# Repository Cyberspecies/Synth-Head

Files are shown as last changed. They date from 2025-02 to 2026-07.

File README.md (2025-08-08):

# Synth Head
To create an open source suit which can be worn by an individual and customised to their will. It also must be constructed in such a way that an average human could build it within a reasonable budget and time. The suit must be modular whilst remaining safe for the user to operate. The software must be easy to configure for any individual and has capability to modify without the need to always reflashing its firmware. The project was created according to this standard however, it has evolved over time to be more of a testing ground for sensors and other features of the like as I will continue this along with other projects I have due to compatibility.

DX.3

## Overview
This project is always in the works and will be updated. Although regular updates are not possible due to me still being in uni, I will do what I can. This repo is basically a better version of the other repo and a true migration as the old one due to its structure. The reason for it being a new repo rather then just a fix is cause the title changed so the old link wouldn't have worked anyway. The current design is DX which stands for Design 10 as it is the 10th time the base shape has changed, the .3 at the end is an iterator for which version were on.

### Features
* <strong style='color: #99ccff;'>Vacuum Formed Visor</strong> allows the user to see out of a clear shell rather then the previous mesh version which caused chromatic abberation, preventing the true colours of the display from emiting through the visor properly.
* <strong style='color: #99ccff;'>Detachable Substructure</strong> which conformes to the visor ridge provides an easy to modify platform to which different displays, sensors and other modules.
* <strong style='color: #99ccff;'>Builtin Head Restraint</strong> was designed to hold in an average head with relatively high pressure, although the pressure seems like it cause pain, the addition of a foam pad mitigates this and is actually comfortable to wear.
* <strong style='color: #99ccff;'>Silent Slim Jaw Mount</strong> of around 6mm in total thickness is directly integrated to the shell.
* <strong style='color: #99ccff;'>Snoot Sensors</strong> All of the sensors and modules are attached directly into the detachable substructure and can easily be replaced and upgraded as needed, many of which includes: Boop detection, snoot holding detection & IMUs.
* <strong style='color: #99ccff;'>Ventillation</strong> is key to an alive and well user, there are 2 fans located below the tongue which negatively ventillates the user.

### In the works
* The visor edge and mating surface will be changed due to it currently resulting in an uneven edge to edge connection.
* The builtin head restraint will also be upgraded, although the system works it is not the best designed as it is currently difficult to put the pins in place.
* Electronics & other cabling will be hidden in the final release as it is not compact due to the Rushed version built for speed and prototyping rather then stability.
* ARCOS migration is still under play, the entire library is basically being rewritten slowly so it runs faster with more features. The library is currently not accessable as it is privated but it will be released with the release of the synth head 10.3.
* <strong style='color: #ffb3ff;'>Feature Inclusion:</strong> Cable management
* <strong style='color: #ffb3ff;'>Feature Inclusion:</strong> Visor Edge Alignment Upgrade
* <strong style='color: #ffb3ff;'>Feature Inclusion:</strong> Ventillation Upgrade
* <strong style='color: #ffb3ff;'>Feature Inclusion:</strong> Jaw Mount Upgrade (Attached to head restraint)
* <strong style='color: #ffb3ff;'>Feature Inclusion:</strong> Lighter Frame
* <strong style='color: #ffb3ff;'>Feature Inclusion:</strong> Custom PCB (Control Board, Power & Sensors)

### Roadmap
* <strong style='color: #99ff99;'>Milestone:</strong> [Synth Head DX](/Archives/DX/README.md)
* <strong style='color: #99ff99;'>Milestone:</strong> [Synth Head DX.1](/Archives/DX.1/README.md)
* <strong style='color: #99ff99;'>Milestone:</strong> [Synth Head DX.2 Rushed](/Archives/DX.2%20Rushed/README.md)
* <strong style='color: #99ff99;'>Milestone:</strong> [Synth Head DX.3 Rushed](/Archives/DX.3%20Rushed/README.md)
* <strong style='color: #99ff99;'>Milestone:</strong> Properly Structured Github

### Licensing
* GNU-GPL-3.0: All Software
* CC-NONCOMM: All Hardware (Circuits, CAD, etc)

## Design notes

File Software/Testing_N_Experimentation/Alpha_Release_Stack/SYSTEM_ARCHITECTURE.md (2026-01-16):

# Synth-Head System Architecture & Reference

> **For AI Agents / New Chat Sessions**  
> This document contains all critical information about the dual-ESP32 Synth-Head project including pin mappings, communication protocols, HAL layer, GPU commands, and example code.

---

## Table of Contents

1. [Hardware Overview](#hardware-overview)
2. [Pin Mappings](#pin-mappings)
3. [CPU-GPU Communication Protocol](#cpu-gpu-communication-protocol)
4. [GPU Command Reference](#gpu-command-reference)
5. [HAL Layer Architecture](#hal-layer-architecture)
6. [HAL Interface Reference](#hal-interface-reference)
7. [Display Systems](#display-systems)
8. [Example: Polygon Demo with Cycling Hue](#example-polygon-demo-with-cycling-hue)
9. [PlatformIO Build Configuration](#platformio-build-configuration)
10. [File Structure](#file-structure)

---

## Hardware Overview

The Synth-Head project uses a **dual ESP32-S3 architecture**:

| Component | Description | COM Port |
|---|---|---|
| **CPU** | Main processor - runs application logic, sensors, WiFi | COM15 |
| **GPU** | Display processor - drives HUB75 + OLED, receives draw commands | COM5 |

### Displays

| Display | Resolution | Type | Location | Interface |
|---|---|---|---|---|
| **HUB75** | 128×32 | RGB LED Matrix (2× 64×32 panels) | Both eyes | GPU direct |
| **OLED** | 128×128 | Monochrome SH1107 | GPU board | I2C (0x3C) |

### Communication

- **CPU ↔ GPU**: UART @ **10 Mbps** (10,000,000 baud)
- **Protocol**: `[0xAA][0x55][CmdType:1][Length:2 LE][Payload:N]`

---

## Pin Mappings

### CPU Pins (ESP32-S3 on COM15)

#### I2C Bus
| Pin | GPIO | Function | Connected Devices |
|-----|---|---|---|
| SDA | **9** | I2C Data | ICM20948 (0x68), BME280 (0x76) |
| SCL | **10** | I2C Clock | ICM20948 (0x68), BME280 (0x76) |

#### LED Strips (WS2812B / SK6812)
| Strip | GPIO | LED Count | Purpose |
|---|---|---|---|
| Strip 0 | 16 | - | *Unused* |
| Left Fin | **18** | 13 | Left fin animation |
| Tongue | **8** | 9 | Tongue animation |
| Strip 3 | 39 | - | *Unused* |
| Right Fin | **38** | 13 | Right fin animation |
| Scale LEDs | **37** | 14 | Scale row |

#### Buttons (Active LOW)
| Button | GPIO | Label |
|---|---|---|
| A | **5** | Button A |
| B | **6** | Button B |
| C | **7** | Button C |
| D | **15** | Button D |

#### Fans (PWM)
| Fan | GPIO | Status |
|-----|---|---|
| Fan 1 | 17 | *Unused* |
| Fan 2 | **36** | Active |

#### SD Card (SPI)
| Signal | GPIO |
|---|---|
| MISO | 14 |
| MOSI | 47 |
| CLK | 21 |
| CS | 48 |

#### GPS (NEO-M8, UART2)
| Signal | GPIO | Baud |
|---|---|---|
| TX | 43 | 9600 |
| RX | 44 | 9600 |

#### CPU-GPU UART (UART1)
| Signal | GPIO | Note |
|---|---|---|
| TX | **12** | → GPU RX (GPIO 13) |
| RX | **11** | ← GPU TX (GPIO 12) |
| **Baud** | - | **10,000,000** (10 Mbps) |

#### I2S Microphone (INMP441)
| Signal | GPIO |
|---|---|
| DOUT (SD) | 2 |
| CLK (BCK) | 40 |
| L/R Select | 41 |
| WS | 42 |

### GPU Pins (ESP32-S3 on COM5)

#### CPU-GPU UART (UART1)
| Signal | GPIO |
|---|---|
| TX | 12 |
| RX | **13** |

#### HUB75 (Directly driven by GPU)
```
Configured in ARCOS HUB75 driver - see driver_hub75_simple.hpp
```

#### OLED (I2C)
| Signal | Address |
|---|---|
| SH1107 | **0x3C** |

---

## CPU-GPU Communication Protocol

### Packet Format

```
┌──────┬──────┬─────────┬───────────────┬─────────────┐
│ 0xAA │ 0x55 │ CmdType │ Length (2 LE) │ Payload (N) │
└──────┴──────┴─────────┴───────────────┴─────────────┘
   1B     1B      1B          2B            0-N B
```

- **Sync bytes**: `0xAA 0x55` (must be present)
- **CmdType**: Single byte command identifier
- **Length**: 16-bit little-endian payload length
- **Payload**: Command-specific data

### UART Configuration

```cpp
// CPU side (sending to GPU)
constexpr uart_port_t UART_PORT = UART_NUM_1;
constexpr int UART_TX_PIN = 12;  // CPU TX -> GPU RX (GPIO 13)
constexpr int UART_RX_PIN = 11;  // CPU RX <- GPU TX (GPIO 12)
constexpr int UART_BAUD = 10000000;  // 10 Mbps

uart_config_t cfg = {
    .baud_rate = UART_BAUD,
    .data_bits = UART_DATA_8_BITS,
    .parity = UART_PARITY_DISABLE,
    .stop_bits = UART_STOP_BITS_1,
    .flow_ctrl = UART_HW_FLOWCTRL_DISABLE,
    .source_clk = UART_SCLK_DEFAULT,
};
uart_param_config(UART_PORT, &cfg);
uart_set_pin(UART_PORT, UART_TX_PIN, UART_RX_PIN, -1, -1);
uart_driver_install(UART_PORT, 4096, 2048, 0, nullptr, 0);  // RX=4KB, TX=2KB
```

### ⚠️ CRITICAL TIMING REQUIREMENTS

**The GPU ESP32's uart_task needs time to initialize after boot!**

If you send commands immediately after CPU UART init, the GPU may not be ready to receive them, resulting in:
- Ping timeouts
- Commands being lost/ignored
- Intermittent connection failures

**Required Timing:**

```cpp
// After uart_driver_install(), WAIT before sending first command!
uart_driver_install(UART_PORT, 4096, 2048, 0, nullptr, 0);

// CRITICAL: Wait 500ms for GPU to fully initialize its UART task
// This matches the working CPU_PolygonDemo.cpp timing
vTaskDelay(pdMS_TO_TICKS(500));

// Now safe to send commands
sendResetCommand();
```

**Best Practices:**
1. **Wait 500ms** after UART init before sending first command
2. Use `uart_wait_tx_done(port, timeout)` after sending commands that need confirmation
3. Flush RX buffer before expecting responses: `uart_flush_input(port)`
4. Use larger buffers (4096 RX, 2048 TX) for high-speed communication

**Reference Implementation:**
- See [CPU_PolygonDemo.cpp](src/CPU_PolygonDemo.cpp) - this demo works reliably every time
- Line 193 has the critical 500ms delay after UART init

**If GPU Won't Connect:**
1. Check hardware connections (TX/RX crossover)
2. Verify GPIO pins are correct
3. **Increase startup delay** (500ms is minimum)
4. Check baud rate matches (10 Mbps)
5. Verify GPU firmware is flashed and running

---

## GPU Command Reference

### Command Types (CmdType values)

#### System Commands
| Cmd | Hex | Payload | Description |
|-----|-----|---|---|
| NOP | 0x00 | - | No operation |
| PING | 0xF0 | - | Ping GPU |
| RESET | 0xFF | - | Reset GPU state |

#### Target Selection
| Cmd | Hex | Payload | Description |
|-----|-----|---|---|
| SET_TARGET | 0x50 | `[target:1]` | 0=HUB75, 1=OLED |
| PRESENT | 0x51 | - | Swap framebuffer to display |

#### HUB75 Drawing (Target 0)
| Cmd | Hex | Payload | Description |
|-----|-----|---|---|
| DRAW_PIXEL | 0x40 | `[x:2][y:2][r:1][g:1][b:1]` | Draw single pixel |
| DRAW_LINE | 0x41 | `[x1:2][y1:2][x2:2][y2:2][r:1][g:1][b:1]` | Draw line |
| DRAW_RECT | 0x42 | `[x:2][y:2][w:2][h:2][r:1][g:1][b:1]` | Rectangle outline |
| DRAW_FILL | 0x43 | `[x:2][y:2][w:2][h:2][r:1][g:1][b:1]` | Filled rectangle |
| DRAW_CIRCLE | 0x44 | `[cx:2][cy:2][radius:2][r:1][g:1][b:1]` | Circle outline |
| DRAW_POLY | 0x45 | `[nVerts:1][varStart:1][r:1][g:1][b:1]` | Polygon from vars |
| BLIT_SPRITE | 0x46 | `[id:1][x:2][y:2]` | Blit uploaded sprite |
| CLEAR | 0x47 | `[r:1][g:1][b:1]` | Clear to color |

#### Float Coordinate Versions (Anti-aliased)
| Cmd | Hex | Payload | Description |
|-----|-----|---|---|
| DRAW_LINE_F | 0x48 | `[x1:4f][y1:4f][x2:4f][y2:4f][r:1][g:1][b:1]` | AA line |
| DRAW_CIRCLE_F | 0x49 | `[cx:4f][cy:4f][radius:4f][r:1][g:1][b:1]` | AA circle |
| DRAW_RECT_F | 0x4A | `[x:4f][y:4f][w:4f][h:4f][r:1][g:1][b:1]` | AA rect |

#### OLED Drawing (128×128 Mono)
| Cmd | Hex | Payload | Description |
|-----|-----|---|---|
| OLED_CLEAR | 0x60 | - | Clear OLED |
| OLED_LINE | 0x61 | `[x1:2][y1:2][x2:2][y2:2][on:1]` | Draw line |
| OLED_RECT | 0x62 | `[x:2][y:2][w:2][h:2][on:1]` | Rectangle outline |
| OLED_FILL | 0x63 | `[x:2][y:2][w:2][h:2][on:1]` | Filled rectangle |
| OLED_CIRCLE | 0x64 | `[cx:2][cy:2][r:2][on:1]` | Circle outline |
| OLED_PRESENT | 0x65 | - | Update OLED display |
| OLED_PIXEL | 0x66 | `[x:2][y:2][on:1]` | Single pixel |
| OLED_VLINE | 0x67 | `[x:2][y:2][len:2][on:1]` | Vertical line |
| OLED_HLINE | 0x68 | `[x:2][y:2][len:2][on:1]` | Horizontal line |
| OLED_FILL_CIRCLE | 0x69 | `[cx:2][cy:2][r:2][on:1]` | Filled circle |

#### Shader System
| Cmd | Hex | Payload | Description |
|-----|-----|---|---|
| UPLOAD_SHADER | 0x10 | `[slot:1][bytecode:N]` | Upload shader |
| DELETE_SHADER | 0x11 | `[slot:1]` | Delete shader |
| EXEC_SHADER | 0x12 | `[slot:1]` | Execute shader |
| SET_VAR | 0x30 | `[id:1][value:2]` | Set variable |
| SET_VARS | 0x31 | `[startId:1][count:1][values:2×N]` | Set multiple vars |

#### Sprite System
| Cmd | Hex | Payload | Description |
|-----|-----|---|---|
| UPLOAD_SPRITE | 0x20 | `[id:1][w:1][h:1][fmt:1][data:N]` | Upload sprite |
| DELETE_SPRITE | 0x21 | `[id:1]` | Delete sprite |

### Payload Encoding

All multi-byte integers are **little-endian (LE)**:
```cpp
// Encode int16_t to payload
void encodeI16(uint8_t* buf, int idx, int16_t val) {
    buf[idx] = val & 0xFF;           // Low byte first
    buf[idx + 1] = (val >> 8) & 0xFF; // High byte second
}
```

---

## HAL Layer Architecture

### Namespace Structure

```
arcos::hal
├── HalResult          // Result codes (OK, ERROR, TIMEOUT, etc.)
├── HalTypes           // RGB, RGBW, Vec3f, Vec3i
├── pins::cpu          // CPU pin definitions
├── pins::gpu          // GPU pin definitions  
├── pins::i2c_addr     // I2C device addresses
├── pins::defaults     // Default settings
│
├── IHalGpio           // Digital GPIO interface
├── IHalPwm            // PWM output interface
├── IHalButton         // Button input interface
├── IHalUart           // UART interface
├── IHalI2c            // I2C interface
├── IHalSpi            // SPI interface
├── IHalI2s            // I2S audio interface
├── IHalTimer          // Timer/delay interface
├── IHalImu            // IMU sensor interface
├── IHalEnvironmental  // Temperature/humidity/pressure
├── IHalGps            // GPS interface
├── IHalMicrophone     // Microphone input
├── IHalLedStrip       // Addressable LED strips
├── IHalDisplay        // Display interface
└── IHalStorage        // SD card/flash storage
```

### Pin Constants (from `HAL/hal.hpp`)

```cpp
namespace arcos::hal::pins {

namespace cpu {
  // I2C
  constexpr gpio_pin_t I2C_SDA = 9;
  constexpr gpio_pin_t I2C_SCL = 10;
  
  // LED Strips
  constexpr gpio_pin_t LED_LEFT_FIN = 18;    // 13 LEDs
  constexpr gpio_pin_t LED_RIGHT_FIN = 38;   // 13 LEDs
  constexpr gpio_pin_t LED_TONGUE = 8;       // 9 LEDs
  constexpr gpio_pin_t LED_SCALE = 37;       // 14 LEDs
  
  // Buttons
  constexpr gpio_pin_t BUTTON_A = 5;
  constexpr gpio_pin_t BUTTON_B = 6;
  constexpr gpio_pin_t BUTTON_C = 7;
  constexpr gpio_pin_t BUTTON_D = 15;
  
  // CPU-GPU UART
  constexpr gpio_pin_t UART_TX = 12;
  constexpr gpio_pin_t UART_RX = 11;
  
  // I2S Microphone
  constexpr gpio_pin_t MIC_DOUT = 2;
  constexpr gpio_pin_t MIC_CLK = 40;
  constexpr gpio_pin_t MIC_LR_SEL = 41;
  constexpr gpio_pin_t MIC_WS = 42;
  
  // GPS
  constexpr gpio_pin_t GPS_TX = 43;
  constexpr gpio_pin_t GPS_RX = 44;
}

namespace i2c_addr {
  constexpr i2c_addr_t ICM20948 = 0x68;
  constexpr i2c_addr_t BME280 = 0x76;
  constexpr i2c_addr_t OLED_SH1107 = 0x3C;
}

namespace defaults {
  constexpr uint32_t CPU_GPU_BAUD = 10000000;  // 10 Mbps
  constexpr uint32_t GPS_BAUD = 9600;
  constexpr uint32_t I2C_FREQ = 400000;
}

}
```

---

## HAL Interface Reference

### IHalImu (ICM20948)

```cpp
struct ImuData {
  Vec3f accel;        // Accelerometer (g)
  Vec3f gyro;         // Gyroscope (°/s)
  Vec3f mag;          // Magnetometer (μT)
  float temperature;  // Temperature (°C)
  timestamp_ms_t timestamp;
  bool accel_valid, gyro_valid, mag_valid;
};

struct ImuConfig {
  i2c_addr_t address = 0x68;
  uint8_t accel_range = 4;      // ±2, ±4, ±8, ±16 g
  uint16_t accel_rate = 100;    // Hz
  uint16_t gyro_range = 500;    // ±250, ±500, ±1000, ±2000 dps
  uint16_t gyro_rate = 100;     // Hz
  bool mag_enabled = true;
  uint8_t mag_rate = 100;       // Hz
};

class IHalImu {
  virtual HalResult init(const ImuConfig& config) = 0;
  virtual HalResult deinit() = 0;
  virtual bool isInitialized() const = 0;
  virtual HalResult readAll(ImuData& data) = 0;
  virtual HalResult readAccel(Vec3f& accel) = 0;
  virtual HalResult readGyro(Vec3f& gyro) = 0;
  virtual HalResult readMag(Vec3f& mag) = 0;
};
```

### IHalEnvironmental (BME280)

```cpp
struct EnvironmentalData {
  float temperature;     // °C
  float humidity;        // %
  float pressure;        // Pa
  timestamp_ms_t timestamp;
  bool temperature_valid, humidity_valid, pressure_valid;
};

struct EnvironmentalConfig {
  i2c_addr_t address = 0x76;
  uint8_t temp_oversampling = 1;     // 1, 2, 4, 8, 16
  uint8_t humidity_oversampling = 1;
  uint8_t pressure_oversampling = 1;
  uint8_t mode = 3;                   // 0=sleep, 1=forced, 3=normal
  uint16_t standby_ms = 1000;
};

class IHalEnvironmental {
  virtual HalResult init(const EnvironmentalConfig& config) = 0;
  virtual HalResult readAll(EnvironmentalData& data) = 0;
  virtual HalResult readTemperature(float& temp) = 0;
  virtual HalResult readHumidity(float& humidity) = 0;
  virtual HalResult readPressure(float& pressure) = 0;
};
```

### IHalGpio

```cpp
enum class GpioMode { INPUT, OUTPUT, INPUT_PULLUP, INPUT_PULLDOWN };
enum class GpioState { LOW, HIGH };

class IHalGpio {
  virtual HalResult init() = 0;
  virtual HalResult pinMode(gpio_pin_t pin, GpioMode mode) = 0;
  virtual GpioState digitalRead(gpio_pin_t pin) = 0;
  virtual HalResult digitalWrite(gpio_pin_t pin, GpioState state) = 0;
};
```

### Common Types

```cpp
enum class HalResult : uint8_t {
  OK = 0, ERROR, TIMEOUT, BUSY, INVALID_PARAM,
  NOT_INITIALIZED, NOT_SUPPORTED, BUFFER_FULL,
  BUFFER_EMPTY, NO_DATA, HARDWARE_FAULT,
  ALREADY_INITIALIZED, INVALID_STATE, NO_MEMORY,
  DEVICE_NOT_FOUND, READ_FAILED, WRITE_FAILED
};

struct RGB { uint8_t r, g, b; };
struct RGBW { uint8_t r, g, b, w; };
struct Vec3f { float x, y, z; };
struct Vec3i { int32_t x, y, z; };
```

---

## Display Systems

### HUB75 (128×32 RGB)

- **Configuration**: 2× 64×32 panels side-by-side
- **Coordinate System**: (0,0) = top-left, X increases right, Y increases down
- **Color Depth**: 24-bit RGB (8 bits per channel)
- **Frame Rate**: 60 FPS typical, 30 FPS minimum
- **Notes**: GPU automatically mirrors X-axis for correct orientation

### OLED (128×128 Mono)

- **Controller**: SH1107
- **Interface**: I2C @ 0x3C
- **Color Depth**: 1-bit (on/off)
- **Frame Rate**: 15 FPS typical
- **Notes**: GPU mirrors both X and Y for correct orientation

### Display Workflow

```cpp
// HUB75 rendering
gpu.setTarget(0);           // Target HUB75
gpu.hub75Clear(0, 0, 0);    // Clear to black
gpu.hub75Line(0, 0, 127, 31, 255, 0, 0);  // Draw red diagonal
gpu.hub75Present();         // Swap to display

// OLED rendering
gpu.oledClear();            // Clear OLED
gpu.oledText(10, 10, "Hello");  // Draw text
gpu.oledPresent();          // Update display
```

---

## Example: Polygon Demo with Cycling Hue

This example demonstrates:
- UART setup for CPU→GPU communication
- HSV to RGB color conversion
- Scanline polygon fill algorithm
- Animated hue cycling

### Full Source Code (`CPU_PolygonDemo.cpp`)

```cpp
/*****************************************************************
 * CPU_PolygonDemo.cpp - Simple filled polygon with RGB effect
 * 
 * Displays a filled polygon on both HUB75 panels with animated
 * RGB color cycling. OLED stays black.
 *****************************************************************/

#include <cstdio>
#include <cstring>
#include <cmath>
#include "freertos/FreeRTOS.h"
#include "freertos/task.h"
#include "driver/uart.h"
#include "esp_log.h"
#include "esp_timer.h"

static const char* TAG = "POLY_DEMO";

// ============================================================
// UART Configuration
// ============================================================
constexpr uart_port_t UART_PORT = UART_NUM_1;
constexpr int UART_TX_PIN = 12;
constexpr int UART_RX_PIN = 11;
constexpr int UART_BAUD = 10000000;

// ============================================================
// Protocol Constants
// ============================================================
constexpr uint8_t SYNC0 = 0xAA;
constexpr uint8_t SYNC1 = 0x55;

enum CmdType : uint8_t {
    DRAW_PIXEL = 0x40,
    CLEAR = 0x47,
    SET_TARGET = 0x50,
    PRESENT = 0x51,
    OLED_CLEAR = 0x60,
    OLED_PRESENT = 0x65,
};

// ============================================================
// Polygon Vertices (YOUR SHAPE)
// ============================================================
// Original: {6,8},{14,8},{20,11},{26,17},{27,19},{28,22},{23,22},
//           {21,19},{19,17},{17,17},{16,19},{18,22},{7,22},{4,20},{2,17},{2,12}
static const int16_t POLY_X[] = {6, 14, 20, 26, 27, 28, 23, 21, 19, 17, 16, 18, 7, 4, 2, 2};
static const int16_t POLY_Y[] = {8, 8, 11, 17, 19, 22, 22, 19, 17, 17, 19, 22, 22, 20, 17, 12};
static const int NUM_VERTS = 16;

// ============================================================
// Send Command to GPU
// ============================================================
static void sendCmd(CmdType type, const uint8_t* payload, uint16_t len) {
    uint8_t header[5] = {SYNC0, SYNC1, type, (uint8_t)(len & 0xFF), (uint8_t)(len >> 8)};
    uart_write_bytes(UART_PORT, header, 5);
    if (len > 0 && payload) {
        uart_write_bytes(UART_PORT, payload, len);
    }
    uart_wait_tx_done(UART_PORT, pdMS_TO_TICKS(50));
}

static void setTarget(uint8_t t) { sendCmd(SET_TARGET, &t, 1); }
static void present() { sendCmd(PRESENT, nullptr, 0); }
static void oledClear() { sendCmd(OLED_CLEAR, nullptr, 0); }
static void oledPresent() { sendCmd(OLED_PRESENT, nullptr, 0); }

static void clear(uint8_t r, uint8_t g, uint8_t b) {
    uint8_t p[3] = {r, g, b};
    sendCmd(CLEAR, p, 3);
}

// ============================================================
// HSV to RGB Conversion
// ============================================================
static void hsvToRgb(float h, float s, float v, uint8_t* r, uint8_t* g, uint8_t* b) {
    float c = v * s;
    float x = c * (1 - fabsf(fmodf(h / 60.0f, 2) - 1));
    float m = v - c;
    
    float rf, gf, bf;
    if (h < 60)       { rf = c; gf = x; bf = 0; }
    else if (h < 120) { rf = x; gf = c; bf = 0; }
    else if (h < 180) { rf = 0; gf = c; bf = x; }
    else if (h < 240) { rf = 0; gf = x; bf = c; }
    else if (h < 300) { rf = x; gf = 0; bf = c; }
    else              { rf = c; gf = 0; bf = x; }
    
    *r = (uint8_t)((rf + m) * 255);
    *g = (uint8_t)((gf + m) * 255);
    *b = (uint8_t)((bf + m) * 255);
}

// ============================================================
// Scanline Polygon Fill with Gradient
// ============================================================
static void fillPolygonGradient(int16_t* px, int16_t* py, int n, float baseHue) {
    // Find bounding box
    int16_t minX = px[0], maxX = px[0];
    int16_t minY = py[0], maxY = py[0];
    for (int i = 1; i < n; i++) {
        if (px[i] < minX) minX = px[i];
        if (px[i] > maxX) maxX = px[i];
        if (py[i] < minY) minY = py[i];
        if (py[i] > maxY) maxY = py[i];
    }
    
    float width = maxX - minX;
    if (width < 1) width = 1;
    
    // Scanline fill
    for (int16_t y = minY; y <= maxY; y++) {
        int16_t nodeX[32];
        int nodes = 0;
        
        // Find edge intersections
        int j = n - 1;
        for (int i = 0; i < n; i++) {
            if ((py[i] < y && py[j] >= y) || (py[j] < y && py[i] >= y)) {
                nodeX[nodes++] = px[i] + (y - py[i]) * (px[j] - px[i]) / (py[j] - py[i]);
            }
            j = i;
        }
        
        // Sort intersections
        for (int i = 0; i < nodes - 1; i++) {
            for (int k = i + 1; k < nodes; k++) {
                if (nodeX[i] > nodeX[k]) {
                    int16_t tmp = nodeX[i];
                    nodeX[i] = nodeX[k];
                    nodeX[k] = tmp;
                }
            }
        }
        
        // Fill between pairs with gradient
        for (int i = 0; i < nodes; i += 2) {
            if (i + 1 < nodes) {
                for (int16_t x = nodeX[i]; x <= nodeX[i+1]; x++) {
                    // Gradient: position-based hue (0° to 240° = red to blue)
                    float t = (float)(x - minX) / width;
                    float hue = baseHue + t * 240.0f;  // Red→Blue spectrum
                    while (hue >= 360.0f) hue -= 360.0f;
                    
                    uint8_t r, g, b;
                    hsvToRgb(hue, 1.0f, 1.0f, &r, &g, &b);
                    
                    // Send DRAW_PIXEL command
                    uint8_t p[7];
                    p[0] = x & 0xFF; p[1] = x >> 8;
                    p[2] = y & 0xFF; p[3] = y >> 8;
                    p[4] = r; p[5] = g; p[6] = b;
                    uint8_t hdr[5] = {SYNC0, SYNC1, DRAW_PIXEL, 7, 0};
                    uart_write_bytes(UART_PORT, hdr, 5);
                    uart_write_bytes(UART_PORT, p, 7);
                }
            }
        }
    }
}

// ============================================================
// UART Initialization
// ============================================================
static bool initUart() {
    uart_config_t cfg = {
        .baud_rate = UART_BAUD,
        .data_bits = UART_DATA_8_BITS,
        .parity = UART_PARITY_DISABLE,
        .stop_bits = UART_STOP_BITS_1,
        .flow_ctrl = UART_HW_FLOWCTRL_DISABLE,
        .rx_flow_ctrl_thresh = 0,
        .source_clk = UART_SCLK_DEFAULT,
    };
    uart_param_config(UART_PORT, &cfg);
    uart_set_pin(UART_PORT, UART_TX_PIN, UART_RX_PIN, -1, -1);
    uart_driver_install(UART_PORT, 1024, 1024, 0, nullptr, 0);
    return true;
}

// ============================================================
// Main Entry Point
// ============================================================
extern "C" void app_main() {
    ESP_LOGI(TAG, "=== Polygon Demo ===");
    
    initUart();
    vTaskDelay(pdMS_TO_TICKS(500));
    
    // Clear OLED once
    oledClear();
    oledPresent();
    
    // Prepare polygon vertices - FLIPPED horizontally for both eyes
    int16_t leftX[NUM_VERTS], leftY[NUM_VERTS];
    int16_t rightX[NUM_VERTS], rightY[NUM_VERTS];
    
    for (int i = 0; i < NUM_VERTS; i++) {
        // Left eye: mirror around x=32
        leftX[i] = 64 - POLY_X[i];
        leftY[i] = POLY_Y[i];
        
        // Right eye: mirror around x=96
        rightX[i] = 128 - POLY_X[i];
        rightY[i] = POLY_Y[i];
    }
    
    // Animation loop
    float hueOffset = 0.0f;
    
    while (true) {
        setTarget(0);
        clear(0, 0, 0);
        
        // Draw both eyes with gradient
        fillPolygonGradient(leftX, leftY, NUM_VERTS, hueOffset);
        fillPolygonGradient(rightX, rightY, NUM_VERTS, hueOffset);
        
        uart_wait_tx_done(UART_PORT, pdMS_TO_TICKS(100));
        present();
        
        // Cycle hue for animation (remove this line for static gradient)
        hueOffset += 2.0f;
        if (hueOffset >= 360.0f) hueOffset -= 360.0f;
        
        vTaskDelay(pdMS_TO_TICKS(33));  // ~30 FPS
    }
}
```

### Static vs Animated Gradient

**For static gradient (red→blue):**
```cpp
// Set hueOffset = 0 and don't increment it
fillPolygonGradient(leftX, leftY, NUM_VERTS, 0.0f);
```

**For cycling animation:**
```cpp
hueOffset += 2.0f;  // Speed of color cycling
if (hueOffset >= 360.0f) hueOffset -= 360.0f;
```

---

## PlatformIO Build Configuration

### For CPU Polygon Demo

Add to `platformio.ini`:

```ini
[env:CPU_PolygonDemo]
platform = espressif32
board = esp32s3usbotg
framework = espidf
upload_port = COM15
monitor_port = COM15
monitor_speed = 115200
board_build.flash_size = 8MB
board_build.cmake_extra_args = -DCPU_POLYGON_DEMO_MODE=1
build_flags = 
    -DARDUINO_USB_CDC_ON_BOOT
    -DCPU_BUILD
    -O3
    -std=c++17
```

Add to `src/CMakeLists.txt`:

```cmake
option(CPU_POLYGON_DEMO_MODE "Build CPU Polygon Demo" OFF)

if(CPU_POLYGON_DEMO_MODE)
    idf_component_register(
        SRCS "CPU_PolygonDemo.cpp"
        INCLUDE_DIRS "../include"
    )
endif()
```

### For GPU Programmable

```ini
[env:GPU_Programmable]
platform = espressif32
board = esp32s3usbotg
framework = espidf
upload_port = COM5
monitor_port = COM5
monitor_speed = 115200
board_build.flash_size = 8MB
board_build.sdkconfig_defaults = sdkconfig.defaults.GPU
board_build.cmake_extra_args = -DGPU_PROGRAMMABLE_MODE=1
build_flags = 
    -DARDUINO_USB_CDC_ON_BOOT
    -DGPU_BUILD
    -DGPU_PROGRAMMABLE
    -O3
    -std=c++17
    -I ../include
```

### Build Commands

```bash
# Build and upload GPU firmware first
pio run -e GPU_Programmable -t upload

# Build and upload CPU demo
pio run -e CPU_PolygonDemo -t upload
```

---

## File Structure

```
Alpha_Release_Stack/
├── platformio.ini              # Build configurations
├── CMakeLists.txt              # Main CMake config
├── PIN_MAPPING_CPU.md          # CPU pin reference
├── SYSTEM_ARCHITECTURE.md      # THIS FILE
│
├── include/
│   ├── HAL/
│   │   ├── hal.hpp             # Master HAL include
│   │   ├── HalTypes.hpp        # Common types
│   │   ├── IHalGpio.hpp        # GPIO interface
│   │   ├── IHalI2c.hpp         # I2C interface
│   │   ├── IHalUart.hpp        # UART interface
│   │   ├── IHalImu.hpp         # IMU interface
│   │   ├── IHalEnvironmental.hpp
│   │   ├── IHalGps.hpp
│   │   ├── IHalMicrophone.hpp
│   │   └── ...
│   │
│   ├── GpuDriver/
│   │   ├── GpuCommands.hpp     # Stable GPU command wrapper
│   │   ├── GpuBaseAPI.hpp
│   │   └── ...
│   │
│   ├── FrameworkAPI/
│   │   ├── Physics2D.hpp       # 2D physics engine
│   │   ├── InputManager.hpp
│   │   └── ...
│   │
│   └── SystemAPI/
│       ├── SystemAPI.hpp
│       ├── WebServer.hpp
│       └── UI/
│
├── src/
│   ├── CMakeLists.txt          # Source selection
│   ├── CPU.cpp                 # Default CPU main
│   ├── GPU.cpp                 # Default GPU main
│   ├── CPU_PolygonDemo.cpp     # Polygon demo
│   ├── GPU_Programmable.cpp    # Programmable GPU firmware
│   └── ...
│
└── ARCOS/ARCOS_library/        # Core ARCOS library
    └── include/
        └── abstraction/
            └── drivers/
                └── components/
                    ├── HUB75/
                    └── OLED/
```

---

## Quick Reference Card

### Essential Commands

```cpp
// Setup
GpuCommands gpu;
gpu.init();  // UART @ 10Mbps on GPIO 12/11

// HUB75 (128x32 RGB)
gpu.hub75Clear(0, 0, 0);
gpu.hub75Pixel(x, y, r, g, b);
gpu.hub75Line(x1, y1, x2, y2, r, g, b);
gpu.hub75Fill(x, y, w, h, r, g, b);
gpu.hub75Present();

// OLED (128x128 Mono)
gpu.oledClear();
gpu.oledText(x, y, "Hello", scale, on);
gpu.oledFill(x, y, w, h, on);
gpu.oledPresent();
```

### Key Constants

| Constant | Value |
|---|---|
| CPU→GPU Baud | 10,000,000 |
| CPU TX Pin | GPIO 12 |
| CPU RX Pin | GPIO 11 |
| GPU RX Pin | GPIO 13 |
| HUB75 Size | 128×32 |
| OLED Size | 128×128 |
| IMU Address | 0x68 |
| BME280 Address | 0x76 |
| OLED Address | 0x3C |

---

*Last updated: January 2026*

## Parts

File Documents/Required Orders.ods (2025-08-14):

Board : Main
Part | Quantity | Est Cost/1 | Est Cost | Total Req | Total Est Cost | Multiplier | 5
Wroom32-S3 USB OTG No Antenna | 1 | $5.50 | $5.50 | 5 | $27.50
JST GH1.25 Horizontal 2 Pin | 2 | $0.10 | $0.20 | 10 | $2.00 | Total Cost | $485.00
JST GH1.25 Horizontal 8 Pin | 1 | $0.10 | $0.10 | 5 | $0.50
Amass XT30PW Female | 1 | $1.00 | $1.00 | 5 | $5.00
Amass XT30PW Male | 1 | $1.00 | $1.00 | 5 | $5.00
MicroSD 8GB | 1 | $5.00 | $5.00 | 5 | $25.00
FFC 0.5P 4 Pin | 1 | $0.50 | $0.50 | 5 | $2.50
Board : GPU
Part | Quantity | Est Cost | Est Cost | Total Req | Total Est Cost
Wroom32-S3 USB OTG No Antenna | 1 | $5.50 | $5.50 | 5 | $27.50
ESP32 External Antenna | 1 | $1.50 | $1.50 | 5 | $7.50
Amass XT30 Female | 1 | $0.50 | $0.50 | 5 | $2.50
Amass XT30 Male | 1 | $0.50 | $0.50 | 5 | $2.50
MicroSD 8GB | 1 | $5.00 | $5.00 | 5 | $25.00
FFC 0.5P 4 Pin | 1 | $0.50 | $0.50 | 5 | $2.50
Board : Substructure Interface (Main Side)
Part | Quantity | Est Cost | Est Cost | Total Req | Total Est Cost
FFC 0.5P 4 Pin | 1 | $0.50 | $0.50 | 5 | $2.50
Magnetic 20P Pogo Pin Connector Female | 1 | $2.50 | $2.50 | 5 | $12.50
Board : Substructure Interface (Substructure Side)
Part | Quantity | Est Cost | Est Cost | Total Req | Total Est Cost
Amass XT30PW Female | 1 | $1.00 | $1.00 | 5 | $5.00
FFC 0.5P 4 Pin | 1 | $0.50 | $0.50 | 5 | $2.50
Magnetic 20P Pogo Pin Connector Male | 1 | $2.50 | $2.50 | 5 | $12.50
Components
Part | Quantity | Est Cost | Est Cost | Total Req | Total Est Cost
LED Matrix HUB75 P2.5 64x32 | 2 | $15.00 | $30.00 | 10 | $300.00
I2S Microphone | 1 | $3.00 | $3.00 | 5 | $15.00
Cables & Connections
Part | Quantity | Est Cost | Est Cost | Total Req | Total Est Cost
 | 1 | $0.00 | $0.00 | 5 | $0.00

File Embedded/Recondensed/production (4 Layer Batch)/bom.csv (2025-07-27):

Designator | Footprint | Quantity | Value | LCSC Part #
C1_2, C10_2, C10, C12, C2_2, C2, C3, C8 | 0603 | 8 | 0.1uf | C1591
C1, C3_2, C4_2, C4, C5_2, C5, C7_2, C9_2 | 0603 | 8 | 10uF | C3039698
C11, C7, C8_2, C9 | 0603 | 4 | 22uF | C84419
C6_2, C6 | 0603 | 2 | 1uF | C95843
D1_2, D1, D2_2, D2 | 0603 | 4 | LED | C7207730
D3_2, D3 | DIO_PMEG3050EP_115 | 2 | PMEG3050EP_115 | C50603
J1_2, J1 | MOLEX_2171790001 | 2 | 10171746-00021LF | C3197684
J10 | JST_GH_SM02B-GHS-TB_1x02-1MP_P1.25mm_Horizontal | 1 | Fan 1 | C189893
J13_2, J13 | MicroSD_473092651 | 2 | MicroSD | C587826
J14 | JST_GH_SM08B-GHS-TB_1x08-1MP_P1.25mm_Horizontal | 1 | Mic | C265111
J15 | JST_GH_SM08B-GHS-TB_1x08-1MP_P1.25mm_Horizontal | 1 | Expansion | C265111
J2_2 | PinHeader_2x08_P2.54mm_Vertical | 1 | HUB75 Right | C492425
J2 | JST_GH_SM03B-GHS-TB_1x03-1MP_P1.25mm_Horizontal | 1 | LEDs 0 | C514175
J3_2 | JST_GH_SM03B-GHS-TB_1x03-1MP_P1.25mm_Horizontal | 1 | LEDs 1 | C514175
J4_2 | PinHeader_2x08_P2.54mm_Vertical | 1 | HUB75 Left | C492425
J4 | JST_GH_SM03B-GHS-TB_1x03-1MP_P1.25mm_Horizontal | 1 | LEDs 2 | C514175
J5_2 | JST_GH_SM03B-GHS-TB_1x03-1MP_P1.25mm_Horizontal | 1 | LEDs 3 | C514175
J6_2 | JST_GH_SM03B-GHS-TB_1x03-1MP_P1.25mm_Horizontal | 1 | LEDs 4 | C514175
J7 | JST_GH_SM03B-GHS-TB_1x03-1MP_P1.25mm_Horizontal | 1 | LEDs 5 | C514175
J8 | JST_GH_SM08B-GHS-TB_1x08-1MP_P1.25mm_Horizontal | 1 | Buttons | C265111
J9 | JST_GH_SM02B-GHS-TB_1x02-1MP_P1.25mm_Horizontal | 1 | Fan 0 | C189893
Q1, Q2 | SOT-23 | 2 | DMG3402L | C96614
R1_2, R1, R2_2, R2 | 0603 | 4 | 5.1K | C328432
R10_2, R10, R11_2, R11, R12_2, R12, R13, R14, R15, R16, R17, R18, R19, R20, R3_2, R3, R4_2, R4, R5_2, R5, R6_2, R6, R9_2, R9 | 0603 | 24 | 10K | C98220
R7_2 | 0603 | 1 | 147ohm | C2930065
R7 | 0603 | 1 | 145ohm | C2930065
R8_2 | 0603 | 1 | 33ohm | C105588
R8 | 0603 | 1 | 33ohm | C108661
S1_2 | SW_B3U-1000P | 1 | Boot | C231329
S1 | SW_B3U-1000P | 1 | Boot | C231329
S2_2 | SW_B3U-1000P | 1 | RST | C231329
S2 | SW_B3U-1000P | 1 | RST | C231329
U1 | Sensored | 1 | Sensored
U2, U3_2 | SOIC127P1032X265-20N | 2 | 74HC245D_653 | C5625
U3, U6 | SOT-223-3_TabPin2 | 2 | LD1117S33TR_SOT223 | C86781
U4, U7 | SOT-223-3_TabPin2 | 2 | LD1117S50TR_SOT223 | C134077

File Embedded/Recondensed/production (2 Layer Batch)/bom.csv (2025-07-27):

Designator | Footprint | Quantity | Value | LCSC Part #
J1_2, J1 | AMASS_XT30PW-M_1x02_P2.50mm_Horizontal | 2 | Substructure Power
J2_2, J2 | PinHeader_2x10_P2.00mm_Vertical | 2 | Pogo Pins
J8 | JST_GH_SM08B-GHS-TB_1x08-1MP_P1.25mm_Horizontal | 1 | Buttons
SW1 | SW_PUSH_6mm_H5mm | 1 | 0
SW2 | SW_PUSH_6mm_H5mm | 1 | 1
SW3 | SW_PUSH_6mm_H5mm | 1 | 2
SW4 | SW_PUSH_6mm_H5mm | 1 | 3
U1_2, U1 | FFC-4-0.5 | 2 | Substructure

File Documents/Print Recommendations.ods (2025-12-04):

Component | Colour | Quantity | Print Time @ 150mm/s Inner Wall | Per Item Filament | Per Item Filament | Floating | Rec Support Type | Rec Support Z Top | Extra Support | Rec Layer Height | Photo
Substructure | Black | 1 | 1177 min | 218 g | 146 g | Yes | Tree | 0.225mm | Yes – Side struts require extra support | 0.12mm
P2.5 LED Matrix Mounts | N/A | 2 | 93 min | 24 g | 20 g | No | N/A | 0.225mm | No | N/A
OLED Adapter | N/A | 1 | 45 min | 8 g | 7 g | No | N/A | 0.225mm | No | N/A
HUD Light Shield | Black | 1 | 68 min | 15 g | 13 g | No | N/A | N/A | Yes – Thin top bar requires extra support | N/A
Blank Mount | N/A | 1 | 38 min | 6 g | 5 g | No | N/A | N/A | No | N/A

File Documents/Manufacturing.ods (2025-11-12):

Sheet: Main
Manufacturing Costs
Area | Cost | Delivery Time | Wait Time
Printing
Electronics
Misc

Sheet: Printing
Category | Component | Total | Model | Colour | Cost | Waste | Time | Floating Required | Notes |  | AUD | USD | EUR
Main White | Main Shell Back + Main Shell Front + Weld Mounts + Top Scale + Linkage Adapter | 880 g | 676 g | White | $17.16 | $3.98 | 29 h | Partial | Add extra supports to Front Part | Conversion | 1 | 0.66 | 0.56
Main Black | Jaw Front + Jaw Back + Weld Mounts + Maw Floor Plate + Mask + Top Scale + Back Head Restraint + LED Mounts + Vent + Lever | 759 g | 645 g | Black | $14.80 | $2.22 | 25 h | Partial | Added support required | Cost/1KG | $19.50 | $12.87 | $10.92
 |  |  |  |  | $0.00 | $0.00
 |  |  |  |  | $0.00 | $0.00
 |  |  |  |  | $0.00 | $0.00 |  |  |  | Filament | 1639 g
 |  |  |  |  | $0.00 | $0.00 |  |  |  | Total Cost | $31.96
 |  |  |  |  |  |  |  |  |  | Total Time | 2d 6h
 |  |  |  |  |  |  |  |  |  | Total Time H | 54 h

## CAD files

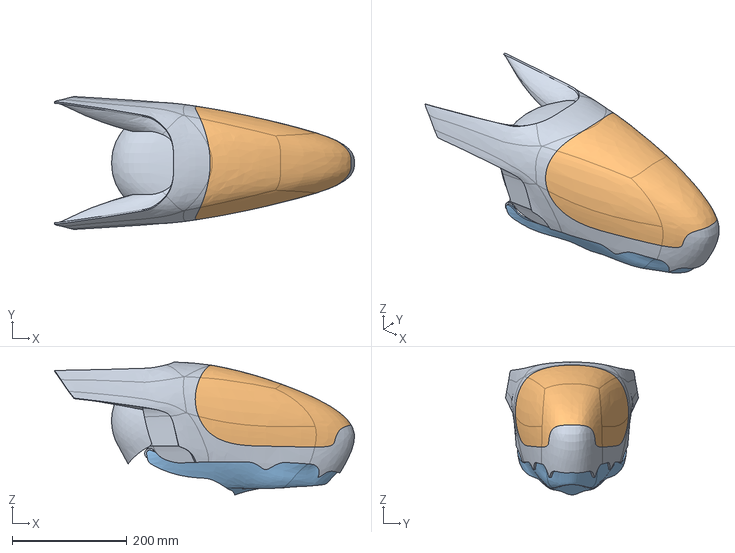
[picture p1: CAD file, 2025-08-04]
Hardware/XCR Head DX.3 (Main).step
522.7 x 231.6 x 231.5 mm

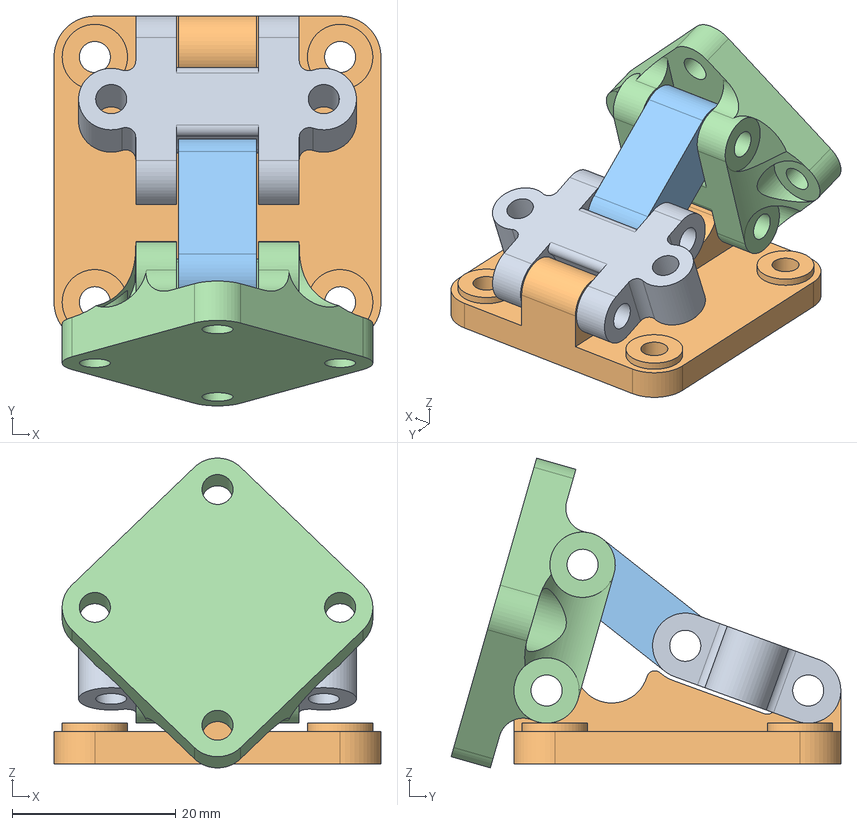
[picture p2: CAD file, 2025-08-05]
Hardware/Hardware Modules & Upgrades/Head Retention 4 Bar Linkage.step
40.0 x 47.7 x 37.9 mm

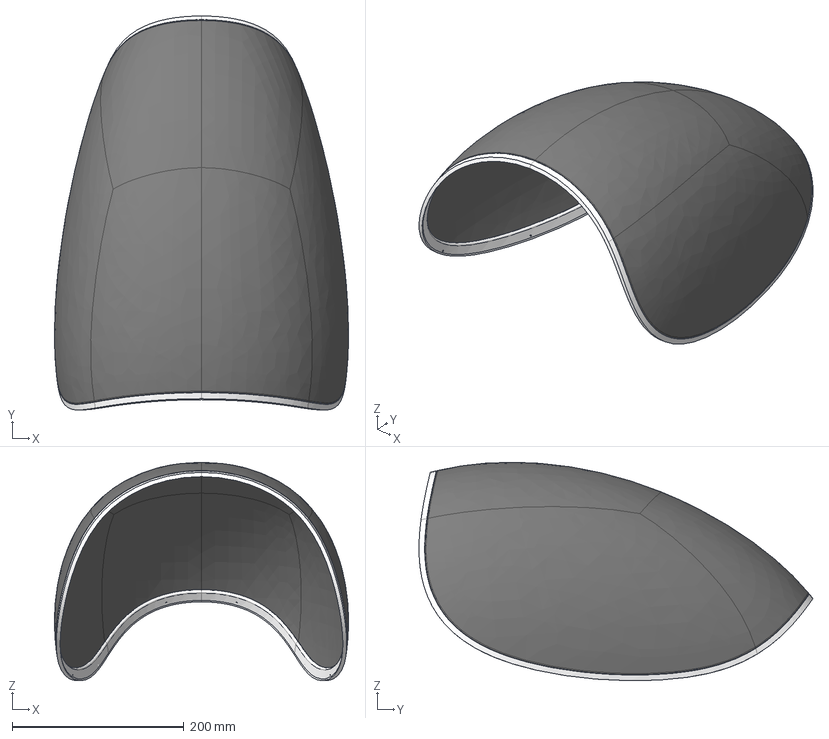
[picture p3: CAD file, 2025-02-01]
Hardware/Substructure Ideation/Substructure Edge Ideation.step
342.7 x 458.9 x 254.5 mm

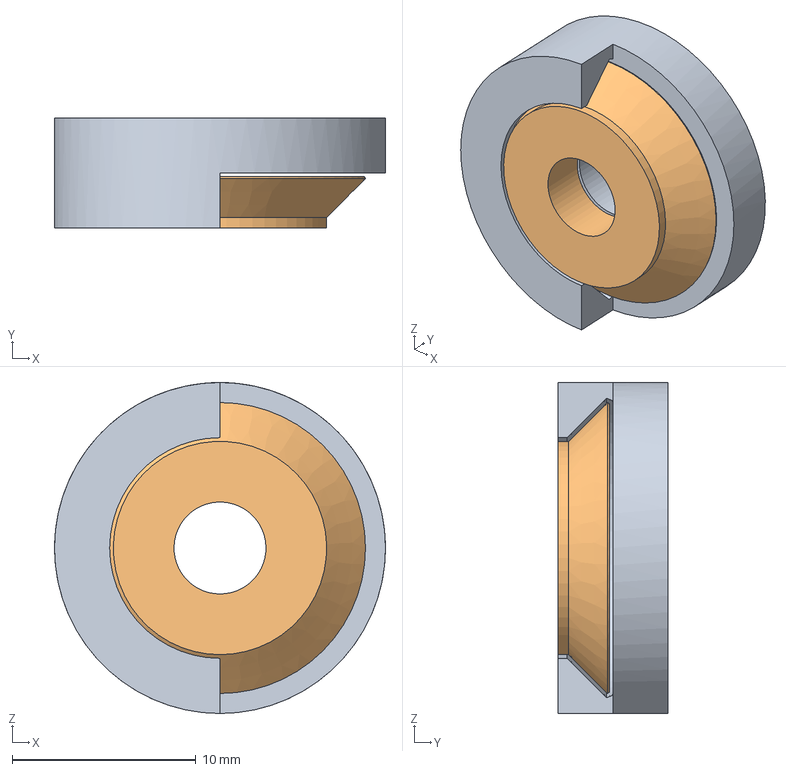
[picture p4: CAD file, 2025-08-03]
Hardware/Hardware Modules & Upgrades/Jaw Joint V4.step
18.0 x 6.00 x 18.0 mm

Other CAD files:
Hardware/Hardware Modules & Upgrades/Head Retention 4 Bar Linkage.f3d
Hardware/Hardware Modules & Upgrades/Jaw Joint V4.f3d
Hardware/Substructure Ideation/Substructure Edge Ideation.f3d

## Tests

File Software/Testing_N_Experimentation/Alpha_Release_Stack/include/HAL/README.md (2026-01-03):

# HAL (Hardware Abstraction Layer) API

## Overview

The HAL API provides **platform-independent interfaces** for all hardware access in the ARCOS system. This layer sits at the bottom of the software stack and abstracts all platform-specific code, registers, and direct hardware access.

```
┌────────────────────────────────────────────┐
│           Application Layer                │
│    (User code, animations, logic)          │
├────────────────────────────────────────────┤
│           Middleware Layer                 │
│  (Odometry, Telemetry, Graphics Pipeline)  │
│  ⚠️ NO platform-specific code allowed!     │
│  ⚠️ NO direct register/sensor access!      │
├────────────────────────────────────────────┤
│              HAL Layer                     │  ◄── YOU ARE HERE
│  (This API - Platform-independent          │
│   interfaces for all hardware)             │
├────────────────────────────────────────────┤
│       Platform Implementation              │
│  (ESP32-S3, etc. - implements HAL          │
│   interfaces with platform-specific code)  │
└────────────────────────────────────────────┘
```

## Design Principles

1. **Platform Independence**: All interfaces use only standard C++ types and custom ARCOS types. No platform-specific headers or types are exposed.

2. **Interface Segregation**: Each hardware category has its own interface file. Include only what you need.

3. **Dependency Injection**: Middleware receives HAL implementations through constructor injection, not global singletons.

4. **No Register Access**: Middleware MUST NOT access hardware registers directly. All hardware interaction goes through HAL interfaces.

5. **Sensor Abstraction**: Raw sensors (IMU, GPS, etc.) are wrapped in HAL interfaces. Middleware builds higher-level services (odometry, telemetry) on top.

## File Structure

```
include/HAL/
├── Hal.hpp                 # Master header - includes all interfaces
├── HalTypes.hpp            # Common types (RGB, Vec3f, HalResult, etc.)
├── README.md               # This file
│
├── Communication Interfaces
│   ├── IHalGpio.hpp        # GPIO, PWM, Button interfaces
│   ├── IHalUart.hpp        # UART serial communication
│   ├── IHalI2c.hpp         # I2C master communication
│   ├── IHalSpi.hpp         # SPI master communication
│   └── IHalI2s.hpp         # I2S audio interface
│
├── System Interfaces
│   └── IHalTimer.hpp       # System timers, delays, timestamps
│
├── Sensor Interfaces
│   ├── IHalImu.hpp         # 9-axis IMU (ICM20948)
│   ├── IHalEnvironmental.hpp # Temp/Humidity/Pressure (BME280)
│   ├── IHalGps.hpp         # GPS positioning (NEO-8M)
│   └── IHalMicrophone.hpp  # I2S microphone (INMP441)
│
├── Output Interfaces
│   ├── IHalLedStrip.hpp    # Addressable LED strips (NeoPixel/SK6812)
│   └── IHalDisplay.hpp     # Displays (HUB75, OLED)
│
└── Storage Interfaces
    └── IHalStorage.hpp     # SD card, file operations
```

## Quick Start

### Include the Master Header

```cpp
#include "HAL/Hal.hpp"

// All interfaces are now available under arcos::hal namespace
```

### Or Include Individual Interfaces

```cpp
#include "HAL/IHalI2c.hpp"
#include "HAL/IHalImu.hpp"

// Only I2C and IMU interfaces available
```

## Interface Categories

### Communication Interfaces

| Interface | File | Purpose |
|---|---|---|
| `IHalGpio` | [IHalGpio.hpp](IHalGpio.hpp) | Digital GPIO pin control |
| `IHalPwm` | [IHalGpio.hpp](IHalGpio.hpp) | PWM output (fans, dimmers) |
| `IHalButton` | [IHalGpio.hpp](IHalGpio.hpp) | Button input with debouncing |
| `IHalUart` | [IHalUart.hpp](IHalUart.hpp) | UART serial communication |
| `IHalI2c` | [IHalI2c.hpp](IHalI2c.hpp) | I2C master communication |
| `IHalSpi` | [IHalSpi.hpp](IHalSpi.hpp) | SPI master communication |
| `IHalI2s` | [IHalI2s.hpp](IHalI2s.hpp) | I2S audio streaming |

### System Interfaces

| Interface | File | Purpose |
|---|---|---|
| `IHalSystemTimer` | [IHalTimer.hpp](IHalTimer.hpp) | Timestamps, delays |
| `IHalHardwareTimer` | [IHalTimer.hpp](IHalTimer.hpp) | Periodic interrupts |

### Sensor Interfaces

| Interface | File | Hardware | Middleware Use |
|---|---|---|---|
| `IHalImu` | [IHalImu.hpp](IHalImu.hpp) | ICM20948 | → Odometry |
| `IHalEnvironmental` | [IHalEnvironmental.hpp](IHalEnvironmental.hpp) | BME280 | → Telemetry |
| `IHalGps` | [IHalGps.hpp](IHalGps.hpp) | NEO-8M | → Telemetry/Navigation |
| `IHalMicrophone` | [IHalMicrophone.hpp](IHalMicrophone.hpp) | INMP441 | → Audio Processing |

### Output Interfaces

| Interface | File | Hardware |
|---|---|---|
| `IHalLedStrip` | [IHalLedStrip.hpp](IHalLedStrip.hpp) | NeoPixel/SK6812 RGBW |
| `IHalHub75Display` | [IHalDisplay.hpp](IHalDisplay.hpp) | HUB75 LED Matrix |
| `IHalOledDisplay` | [IHalDisplay.hpp](IHalDisplay.hpp) | OLED SH1107 |

### Storage Interfaces

| Interface | File | Hardware |
|---|---|---|
| `IHalStorage` | [IHalStorage.hpp](IHalStorage.hpp) | SD Card |
| `IHalFile` | [IHalStorage.hpp](IHalStorage.hpp) | File operations |

## Pin Mapping

Pin definitions are available in `arcos::hal::pins` namespace:

```cpp
#include "HAL/Hal.hpp"
using namespace arcos::hal::pins;

// CPU pins (COM 15)
auto sda_pin = cpu::I2C_SDA;       // GPIO 9
auto button_a = cpu::BUTTON_A;     // GPIO 5

// GPU pins (COM 16)
auto gpu_tx = gpu::UART_TX;        // GPIO 12

// I2C addresses
auto imu_addr = i2c_addr::ICM20948; // 0x68

// Default settings
auto baud = defaults::CPU_GPU_BAUD; // 10 Mbps
```

## Usage Example

### Middleware Using HAL (Correct)

```cpp
// OdometryService.hpp
#include "HAL/IHalImu.hpp"

namespace arcos::middleware{

class OdometryService{
public:
  // Dependency injection - receives HAL implementation
  OdometryService(arcos::hal::IHalImu* imu)
    : imu_(imu){}
  
  bool init(){
    arcos::hal::ImuConfig config;
    config.accel_range = 4;
    config.gyro_range = 500;
    return imu_->init(config) == arcos::hal::HalResult::OK;
  }
  
  void update(){
    arcos::hal::ImuData data;
    if(imu_->readAll(data) == arcos::hal::HalResult::OK){
      // Process IMU data for odometry
      updateOrientation(data.accel, data.gyro);
    }
  }

private:
  arcos::hal::IHalImu* imu_;
  
  void updateOrientation(const arcos::hal::Vec3f& accel, 
                         const arcos::hal::Vec3f& gyro);
};

} // namespace arcos::middleware
```

### What NOT to Do in Middleware

```cpp
// ❌ WRONG - Direct hardware access in middleware
#include <driver/i2c.h>  // Platform-specific!

class BadOdometry{
  void readImu(){
    // ❌ Direct register access
    i2c_master_write_read_device(I2C_NUM_0, 0x68, ...);
  }
};
```

## Common Types

### HalResult

```cpp
enum class HalResult : uint8_t{
  OK = 0,           // Success
  ERROR,            // Generic error
  TIMEOUT,          // Operation timed out
  BUSY,             // Resource busy
  INVALID_PARAM,    // Invalid parameter
  NOT_INITIALIZED,  // Not initialized
  NOT_SUPPORTED,    // Not supported
  BUFFER_FULL,      // Buffer full
  BUFFER_EMPTY,     // Buffer empty
  NO_DATA,          // No data available
  HARDWARE_FAULT    // Hardware fault
};
```

### Color Types

```cpp
struct RGB{
  uint8_t r, g, b;
};

struct RGBW{
  uint8_t r, g, b, w;
  RGB toRGB() const;
};
```

### Vector Types

```cpp
struct Vec3f{
  float x, y, z;
};

struct Vec3i{
  int32_t x, y, z;
};
```

## Hardware Summary

### CPU (COM 15) Hardware

| Category | Hardware | HAL Interface |
|---|---|---|
| IMU | ICM20948 (I2C: 0x68) | `IHalImu` |
| Environmental | BME280 (I2C: 0x76) | `IHalEnvironmental` |
| GPS | NEO-8M (UART) | `IHalGps` |
| Microphone | INMP441 (I2S) | `IHalMicrophone` |
| LED Strips | SK6812 RGBW | `IHalLedStrip` |
| Buttons | A, B, C, D | `IHalButton` |
| Fans | PWM x2 | `IHalPwm` |
| SD Card | SPI | `IHalStorage` |
| GPU Comm | UART 10Mbps | `IHalUart` |

### GPU (COM 16) Hardware

| Category | Hardware | HAL Interface |
|---|---|---|
| Display | HUB75 128x32 | `IHalHub75Display` |
| OLED | SH1107 128x128 | `IHalOledDisplay` |
| CPU Comm | UART 10Mbps | `IHalUart` |

## See Also

- [CODING_STYLE.md](../../CODING_STYLE.md) - Project coding standards
- [PIN_MAPPING_CPU.md](../../PIN_MAPPING_CPU.md) - Hardware pin assignments
- [API_INDEX.md](../API_INDEX.md) - All API documentation index

---

*Part of the ARCOS (Autonomous Robotic Control & Operations System) project*
*Author: XCR1793 (Feather Forge)*

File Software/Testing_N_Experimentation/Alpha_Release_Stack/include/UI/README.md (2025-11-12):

# UI System Documentation

## Overview
Hierarchical menu system with button management for OLED interface.

## Directory Structure
```
include/UI/
├── ButtonManager.hpp          # Button state tracking with press/hold detection
├── Menu/
│   ├── MenuSystem.hpp         # Core menu hierarchy and navigation
│   └── MenuRenderer.hpp       # Rendering implementation
└── OLED/
    └── DebugPages.hpp         # Sensor data display pages
```

## Button Mapping
- **Button 1 (A / SET)**: Select/Confirm *(used in mode selector)*
- **Button 2 (B / UP)**: Navigate Up / Previous
- **Button 3 (C / DOWN)**: Navigate Down / Next
- **Button 4 (D / MODE)**: Mode selector (hold 2 seconds)

## Menu Hierarchy

### Top Level (Mode Selector)
Access by **holding MODE button (2 seconds)** from any screen:
1. **Debug Mode** - Sensor data pages
2. **Standard Mode** - Gyroscope circular visualization
3. **Screen Saver** - Animated bouncing text

**Mode Selector Controls:**
- **UP/DOWN**: Navigate between modes
- **SET**: Confirm selection and enter chosen mode
- **MODE (short press)**: Cancel and return to current mode

### Debug Mode Pages
Navigate with UP/DOWN buttons:
1. **IMU Data** - Accelerometer, gyroscope, magnetometer
2. **Environmental** - Temperature, humidity, pressure
3. **GPS Data** - Position, navigation, time
4. **Microphone** - Audio level, peak, bar graph
5. **System Info** - Frame rates, sensors, buttons

### Standard Mode
Gyroscope visualization with circular indicator:
- Center crosshair shows zero rotation
- Moving dot shows current gyro X/Y rotation rate (±500 dps)
- Line from center to dot shows direction of rotation
- Numeric values (X/Y/Z) displayed at bottom in dps
- Live pulse indicator shows active updates

## ButtonManager Features

### Detection Types
- **Short Press**: Released before 2 second threshold
- **Hold**: Triggered after 2 seconds
- **Hold Repeat**: Continuous events every 150ms while held
- **Debounce**: 50ms minimum

### API
```cpp
ButtonManager btnMgr;
btnMgr.update(sensor_data, current_time_ms);

if (btnMgr.wasPressed(ButtonID::UP)) { }      // Short press
if (btnMgr.wasHeld(ButtonID::MODE)) { }       // Hold started
if (btnMgr.isHeld(ButtonID::MODE)) { }        // Currently held
if (btnMgr.shouldRepeat(ButtonID::DOWN)) { }  // Repeat event

btnMgr.clearFlags();  // Call after processing
```

## MenuSystem Usage

```cpp
#include "UI/ButtonManager.hpp"
#include "UI/Menu/MenuSystem.hpp"
#include "UI/Menu/MenuRenderer.hpp"

// In your task:
ButtonManager btn_mgr;
MenuSystem menu;

// Update loop:
btn_mgr.update(sensor_data, current_time_ms);
menu.update(btn_mgr, sensor_data, current_time_ms);
menu.render(oled_manager);
```

## Integration with GPU.cpp

Replace existing OLED page code with menu system:
1. Include new headers
2. Create ButtonManager and MenuSystem instances
3. Update `oledUpdateTask()` to use menu system
4. Remove old `display*Page()` functions
5. Export stats as globals for system info page

## Global Variables Needed
```cpp
namespace arcos::ui::menu {
  uint32_t g_sensor_fps = 0;
  uint32_t g_led_fps = 0;
  uint8_t g_fan_speed = 0;
}
```

## Benefits
- ✅ **Organized**: UI code separated into logical modules
- ✅ **Hierarchical**: Clean menu tree structure
- ✅ **Extensible**: Easy to add new modes and pages
- ✅ **Robust**: Proper button debouncing and hold detection
- ✅ **Smaller GPU.cpp**: ~235 lines removed from main file

## File Sizes
- ButtonManager.hpp: ~180 lines
- MenuSystem.hpp: ~180 lines
- MenuRenderer.hpp: ~130 lines
- DebugPages.hpp: ~180 lines
- **Total**: ~670 lines (organized vs monolithic)

## Next Steps
To integrate into GPU.cpp:
1. Add includes for new UI system
2. Replace page navigation with menu system
3. Remove old display functions
4. Test button behavior and menu navigation

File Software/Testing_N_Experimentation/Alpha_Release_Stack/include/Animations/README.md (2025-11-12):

# Animation Library

This folder contains animation functions for HUB75, OLED, and LED displays. All animations use **function caching** rather than pixel caching for memory efficiency.

## Structure

```
Animations/
├── HUB75BootAnimations.hpp    - Boot animations for HUB75 matrix
├── HUB75TestAnimations.hpp    - Runtime test animations for HUB75
├── OLEDBootAnimations.hpp     - Boot animations for OLED display
├── LEDBootAnimations.hpp      - Boot animations for LED strips
└── LEDTestAnimations.hpp      - Runtime test animations for LEDs
```

## Usage Pattern

### 1. Include the animation header
```cpp
#include "Animations/HUB75BootAnimations.hpp"
```

### 2. Register animations with manager
```cpp
HUB75DisplayManager hub75;
hub75.initialize(true);

// Register all boot animations
arcos::animations::hub75::registerBootAnimations(hub75);

// Or register individual animations
hub75.registerAnimation("my_custom_anim", [&hub75](uint32_t time_ms){
  // Animation code here
  hub75.clear({0, 0, 0});
  // ... draw operations ...
  hub75.show();
});
```

### 3. Execute animations
```cpp
// By name
hub75.executeAnimation("boot_spinning_circles", millis());

// By index
hub75.executeAnimation(0, millis());
```

## Animation Function Signatures

### HUB75 & OLED Animations
```cpp
void animationFunc(uint32_t time_ms);
```
- `time_ms`: Animation time in milliseconds (for time-based effects)

### LED Animations
```cpp
void animationFunc(LedDataPayload& led_data, uint32_t time_ms);
```
- `led_data`: Reference to LED data payload (modify directly)
- `time_ms`: Animation time in milliseconds

## Creating Custom Animations

### Example: Custom HUB75 Animation
```cpp
inline void customPulse(arcos::manager::HUB75DisplayManager& manager, uint32_t time_ms){
  manager.clear({0, 0, 0});
  
  // Pulsing brightness
  float brightness = 127.5f + 127.5f * sinf(time_ms / 500.0f);
  RGB color = {static_cast<uint8_t>(brightness), 0, 0};
  
  // Draw expanding circle
  int radius = static_cast<int>(16.0f * (1.0f + sinf(time_ms / 300.0f)));
  manager.fillCircle(64, 16, radius, color);
  
  manager.show();
}

// Register it
hub75.registerAnimation("custom_pulse", [&hub75](uint32_t time_ms){
  customPulse(hub75, time_ms);
});
```

### Example: Custom LED Animation
```cpp
inline void customSparkle(LedDataPayload& led_data, uint32_t time_ms){
  // Clear all
  led_data.setAllColor(RgbwColor(0, 0, 0, 0));
  
  // Random sparkles
  for(int i = 0; i < 10; i++){
    uint16_t led_idx = (time_ms + i * 7) % LED_COUNT_TOTAL;
    uint8_t brightness = 255 - (i * 25);
    led_data.leds[led_idx] = RgbwColor(brightness, brightness, brightness, 0);
  }
}

// Register it
led_manager.registerAnimation("custom_sparkle", customSparkle);
```

## Boot Animations

### HUB75
- **boot_spinning_circles**: Dual counter-rotating patterns (good for showing dual display)
- **boot_progress_bar**: Gradient progress bar (visual feedback)
- **boot_ripple**: Expanding circles (smooth startup effect)

### OLED
- **boot_system_init**: Text-based initialization (shows subsystem status)
- **boot_circle_waves**: Expanding waves (visual appeal)
- **boot_logo**: Animated logo/brand (customizable branding)
- **boot_scan_lines**: Scanning effect (retro/technical look)

### LED
- **boot_rainbow_startup**: Rainbow fill (colorful startup)
- **boot_sequential_activation**: Strip-by-strip activation (hardware verification)
- **boot_pulse_wave**: Pulsing brightness (smooth transition)
- **boot_chase_effect**: Running lights (dynamic movement)
- **boot_color_wipe**: Progressive color fill (clear visual progress)

## Test/Runtime Animations

### HUB75
- **test_rainbow_wave**: Scrolling rainbow (color test)
- **test_plasma**: Plasma effect (complex math visualization)
- **test_bouncing_ball**: Physics simulation (motion test)
- **test_starfield**: Moving stars (depth effect)

### LED
- **test_rainbow**: Full spectrum wave
- **test_breathing**: Synchronized breathing per strip
- **test_wave**: Traveling wave effect
- **test_alternating**: Strip switching patterns
- **test_fire**: Flame simulation
- **test_theater_chase**: Classic marquee effect
- **test_color_fade**: Smooth color transitions

## Performance Notes

- All animations are computed in real-time (no pre-rendering)
- Typical animation execution: < 5ms per frame @ 60fps
- Memory usage: ~200 bytes per registered animation (function pointer + name)
- HUB75 antialiased lines: ~2-3x slower than normal lines (still fast enough)
- OLED antialiased lines: Similar performance (monochrome dithering)

## Tips for Animation Development

1. **Use time_ms for smooth animations**: Base effects on time rather than frame count
2. **Normalize values**: Keep brightness/position calculations in 0-1 range, then scale
3. **Avoid memory allocation**: Use stack variables or pre-allocated buffers
4. **Test on hardware**: Simulator doesn't show timing issues
5. **Profile performance**: Use `ESP_LOGI` with timestamps for debugging
6. **Consider display refresh**: HUB75 updates take ~1-2ms, OLED ~10-15ms

## Contributing

When adding new animations:
1. Follow CODING_STYLE.md conventions
2. Use `inline` keyword for header-only functions
3. Document parameters and behavior
4. Add to appropriate `register*Animations()` function
5. Test on actual hardware before committing

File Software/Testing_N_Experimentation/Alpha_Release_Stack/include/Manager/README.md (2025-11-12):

# Display and LED Managers

This folder contains manager classes for HUB75, OLED displays, and LED animations. Managers provide a high-level interface with animation function caching.

## Architecture

```
Manager/
├── HUB75DisplayManager.hpp    - HUB75 LED matrix manager
├── OLEDDisplayManager.hpp     - OLED display manager
└── LEDAnimationManager.hpp    - LED strip animation manager
```

## Design Philosophy

### Function Caching vs Pixel Caching
- **Function Caching**: Store animation functions, compute pixels on-demand
- **Pixel Caching**: Pre-render frames, store pixel data in memory

We use **function caching** because:
- Lower memory footprint (store function pointers, not pixel arrays)
- More flexible (animations can react to parameters)
- Easier to modify (change function, not data)
- Suitable for real-time rendering on ESP32-S3

## Manager Classes

### HUB75DisplayManager

Manages the dual HUB75 LED matrix (128x32 pixels, RGB).

#### Features
- Display initialization with dual OE pin support
- Line drawing (Bresenham and Xiaolin Wu antialiased)
- Shape primitives (circles, rectangles, filled variants)
- Alpha blending for antialiasing
- Animation registration and execution
- Direct pixel access

#### Example Usage
```cpp
#include "Manager/HUB75DisplayManager.hpp"

HUB75DisplayManager hub75;

void setup(){
  // Initialize display
  hub75.initialize(true);  // true = dual OE mode
  
  // Register animation
  hub75.registerAnimation("test", [&hub75](uint32_t time_ms){
    hub75.clear({0, 0, 0});
    
    // Draw antialiased line
    float angle = time_ms / 1000.0f;
    float x1 = 64.0f + 50.0f * cosf(angle);
    float y1 = 16.0f + 12.0f * sinf(angle);
    hub75.drawLineAntialiased(64.0f, 16.0f, x1, y1, {255, 0, 0});
    
    hub75.show();
  });
  
  // Execute animation
  hub75.executeAnimation("test", millis());
}
```

#### API Reference

**Initialization**
```cpp
bool initialize(bool dual_oe_mode = true);
```

**Drawing Functions**
```cpp
void clear(const RGB& color = {0, 0, 0});
void show();
void setPixel(int x, int y, const RGB& color);
void setPixelAlpha(int x, int y, const RGB& color, float alpha);
void drawLine(int x0, int y0, int x1, int y1, const RGB& color);
void drawLineAntialiased(float x0, float y0, float x1, float y1, const RGB& color);
void drawRect(int x, int y, int w, int h, const RGB& color);
void fillRect(int x, int y, int w, int h, const RGB& color);
void drawCircle(int cx, int cy, int radius, const RGB& color);
void fillCircle(int cx, int cy, int radius, const RGB& color);
```

**Animation Management**
```cpp
void registerAnimation(const char* name, HUB75AnimationFunc func);
void executeAnimation(size_t index, uint32_t time_ms);
bool executeAnimation(const char* name, uint32_t time_ms);
size_t getAnimationCount() const;
const char* getAnimationName(size_t index) const;
void clearAnimations();
```

---

### OLEDDisplayManager

Manages the OLED SH1107 display (128x128 pixels, monochrome).

#### Features
- I2C initialization with configurable pins
- Line drawing (normal and antialiased with dithering)
- Text rendering
- Shape primitives
- Animation registration and execution
- Display flip/rotation

#### Example Usage
```cpp
#include "Manager/OLEDDisplayManager.hpp"

OLEDDisplayManager oled;

void setup(){
  // Initialize display
  // i2c_bus, sda_pin, scl_pin, freq_hz, flip_h, flip_v, contrast
  oled.initialize(0, 2, 1, 400000, true, true, 0xCF);
  
  // Register animation
  oled.registerAnimation("clock", [&oled](uint32_t time_ms){
    oled.clear();
    
    // Draw clock face
    oled.drawCircle(64, 64, 50, true);
    
    // Draw hour hand
    float hour_angle = (time_ms / 1000.0f / 3600.0f) * 6.28318f;
    int hour_x = 64 + static_cast<int>(30.0f * sinf(hour_angle));
    int hour_y = 64 - static_cast<int>(30.0f * cosf(hour_angle));
    oled.drawLine(64, 64, hour_x, hour_y, true);
    
    oled.show();
  });
  
  // Execute animation
  oled.executeAnimation("clock", millis());
}
```

#### API Reference

**Initialization**
```cpp
bool initialize(int i2c_bus = 0, int sda_pin = 2, int scl_pin = 1, 
                uint32_t freq_hz = 400000, bool flip_horizontal = true,
                bool flip_vertical = true, uint8_t contrast = 0xCF);
```

**Drawing Functions**
```cpp
void clear();
void show();
void setPixel(int x, int y, bool on = true);
void drawText(int x, int y, const char* text, bool on = true);
void drawLine(int x0, int y0, int x1, int y1, bool on = true);
void drawLineAntialiased(float x0, float y0, float x1, float y1);
void drawRect(int x, int y, int w, int h, bool fill = false, bool on = true);
void fillRect(int x, int y, int w, int h, bool on = true);
void drawCircle(int cx, int cy, int radius, bool on = true);
void fillCircle(int cx, int cy, int radius, bool on = true);
```

**Animation Management**
```cpp
void registerAnimation(const char* name, OLEDAnimationFunc func);
void executeAnimation(size_t index, uint32_t time_ms);
bool executeAnimation(const char* name, uint32_t time_ms);
size_t getAnimationCount() const;
const char* getAnimationName(size_t index) const;
void clearAnimations();
```

---

### LEDAnimationManager

Manages NeoPixel RGBW LED strips (4 strips: left fin, tongue, right fin, scale).

#### Features
- Animation registration and execution
- Per-strip color control
- Fan speed management
- Animation cycling (next/previous)
- Current animation tracking
- Direct access to LED data payload for UART transmission

#### Example Usage
```cpp
#include "Manager/LEDAnimationManager.hpp"

LEDAnimationManager leds;

void setup(){
  // Initialize LED manager
  leds.initialize();
  leds.setFanSpeed(128);  // 50% fan speed
  
  // Register animation
  leds.registerAnimation("rainbow", [](LedDataPayload& data, uint32_t time_ms){
    float time_sec = time_ms / 1000.0f;
    
    for(uint16_t i = 0; i < LED_COUNT_TOTAL; i++){
      float hue = fmodf((i / (float)LED_COUNT_TOTAL) + time_sec * 0.1f, 1.0f);
      // Convert hue to RGB...
      data.leds[i] = RgbwColor(r, g, b, 0);
    }
  });
  
  // Set and update animation
  leds.setCurrentAnimation("rainbow");
  leds.updateCurrentAnimation(millis());
  
  // Get LED data for UART transmission
  LedDataPayload& data = leds.getLedData();
  uart.sendPacket(MessageType::LED_DATA, 
                  reinterpret_cast<uint8_t*>(&data), 
                  sizeof(LedDataPayload));
}
```

#### API Reference

**Initialization**
```cpp
void initialize();
```

**LED Control**
```cpp
LedDataPayload& getLedData();
void setFanSpeed(uint8_t speed);
uint8_t getFanSpeed() const;
void setAllColor(const RgbwColor& color);
void setLeftFinColor(const RgbwColor& color);
void setTongueColor(const RgbwColor& color);
void setRightFinColor(const RgbwColor& color);
void setScaleColor(const RgbwColor& color);
```

**Animation Management**
```cpp
void registerAnimation(const char* name, LEDAnimationFunc func);
void setCurrentAnimation(size_t index, bool reset_time = true);
bool setCurrentAnimation(const char* name, bool reset_time = true);
void updateCurrentAnimation(uint32_t time_ms);
void executeAnimation(size_t index, uint32_t time_ms);
bool executeAnimation(const char* name, uint32_t time_ms);
void nextAnimation();
void previousAnimation();
size_t getAnimationCount() const;
size_t getCurrentAnimationIndex() const;
const char* getAnimationName(size_t index) const;
void clearAnimations();
```

## Antialiasing

### HUB75 (RGB Color Display)
Uses **Xiaolin Wu's line algorithm** with alpha blending:
```cpp
hub75.drawLineAntialiased(0.5f, 0.5f, 127.5f, 31.5f, {255, 0, 0});
```
- Sub-pixel precision (float coordinates)
- Alpha blending based on pixel coverage
- Smooth, high-quality lines

### OLED (Monochrome Display)
Uses **dithering** to simulate antialiasing:
```cpp
oled.drawLineAntialiased(0.5f, 0.5f, 127.5f, 127.5f);
```
- Sub-pixel calculations
- Threshold-based pixel activation
- Best-effort smoothing for 1-bit display

## Thread Safety

### Shared Data Protection
When using managers across multiple tasks:

```cpp
// Create mutex
SemaphoreHandle_t display_mutex = xSemaphoreCreateMutex();

// Task 1: Update animation
void animationTask(void* param){
  while(true){
    if(xSemaphoreTake(display_mutex, portMAX_DELAY) == pdTRUE){
      hub75.executeAnimation("plasma", millis());
      xSemaphoreGive(display_mutex);
    }
    vTaskDelay(pdMS_TO_TICKS(16));
  }
}

// Task 2: Change animation
void controlTask(void* param){
  while(true){
    if(button_pressed){
      if(xSemaphoreTake(display_mutex, portMAX_DELAY) == pdTRUE){
        hub75.clearAnimations();
        hub75.registerAnimation("new_anim", newAnimFunc);
        xSemaphoreGive(display_mutex);
      }
    }
    vTaskDelay(pdMS_TO_TICKS(100));
  }
}
```

## Performance Considerations

### Frame Rate
- **Target**: 60 FPS (16.67ms per frame)
- **HUB75**: ~1-2ms update time
- **OLED**: ~10-15ms update time (I2C bottleneck)
- **LED Data**: <1ms preparation, UART transmission separate

### Optimization Tips
1. **Minimize `show()` calls**: Only call after all drawing complete
2. **Batch operations**: Group similar drawing operations
3. **Use integer math**: Faster than floating point where possible
4. **Profile animations**: Use ESP_LOGI with timestamps
5. **Avoid memory allocation**: Use stack or pre-allocated buffers

### Memory Usage
- **Manager overhead**: ~100-200 bytes per manager
- **Animation storage**: ~16 bytes per registered animation
- **Display buffers**: Managed by underlying drivers
- **No pixel caching**: Animations computed on-demand

## Best Practices

1. **RAII Pattern**: Managers handle initialization and cleanup
2. **Lambda Captures**: Capture manager by reference in lambdas
3. **Time-based Animation**: Use `time_ms` for smooth, frame-rate-independent effects
4. **Error Checking**: Always check `initialize()` return value
5. **Const Correctness**: Use const methods where appropriate

## Troubleshooting

### Display Not Initializing
```cpp
if(!hub75.initialize(true)){
  ESP_LOGE("APP", "HUB75 init failed!");
  // Check wiring, power supply, GPIO conflicts
}
```

### Animation Not Showing
```cpp
// Make sure to call show()
hub75.executeAnimation("test", millis());
hub75.show();  // <- Don't forget this!
```

### Flickering Display
```cpp
// Ensure single task updates display
// Use mutex if multiple tasks access display
```

### Slow Frame Rate
```cpp
// Profile animation execution time
uint32_t start = micros();
hub75.executeAnimation("plasma", millis());
uint32_t duration = micros() - start;
ESP_LOGI("PERF", "Animation took %luµs", duration);
```

## Future Enhancements

Potential improvements:
- [ ] Animation blending/transitions
- [ ] Sprite system for HUB75
- [ ] Font rendering for OLED
- [ ] Animation parameters/configuration
- [ ] Save/load animations from flash
- [ ] Animation scripting language

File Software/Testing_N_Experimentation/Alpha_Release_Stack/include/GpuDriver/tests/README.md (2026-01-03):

# GPU Driver Test Suite

## Overview

This directory contains comprehensive testing infrastructure for the GPU Driver system, including:
- **Virtual Tests**: Algorithm validation, protocol testing, performance benchmarks
- **Extended Tests**: Edge cases, boundary conditions, stress testing  
- **Hardware Tests**: Real ESP32-S3 device communication tests

## Test Files

| File | Tests | Description |
|---|---|---|
| `run_virtual_tests.py` | 35 | Core algorithm validation |
| `run_extended_tests.py` | 39 | Edge cases & stress tests |
| `run_hardware_tests.py` | 14 | Real hardware communication |
| `run_all_tests.py` | All | Master test runner |

## Running Tests

### Run All Virtual Tests
```bash
python run_all_tests.py --skip-hw
```

### Run Full Suite (with hardware)
```bash
python run_all_tests.py
```
Note: Ensure COM ports (COM5, COM15) are not in use by other applications.

### Run Individual Test Suites
```bash
python run_virtual_tests.py
python run_extended_tests.py
python run_hardware_tests.py --cpu-port COM15 --gpu-port COM5
```

## Test Categories

### Virtual Tests (run_virtual_tests.py)

| Category | Tests | Coverage |
|---|---|---|
| ISA | 3 | Opcode values, datatypes, encoding |
| Fixed-Point Math | 4 | Conversion, mul/div, precision |
| Trigonometry | 4 | sin/cos accuracy, identity, performance |
| Color Space | 3 | RGB/HSV conversion, roundtrip |
| Drawing Algorithms | 7 | Bresenham line, midpoint circle |
| Animation/Easing | 2 | Boundary conditions, monotonicity |
| SDF Rendering | 3 | Circle/box distance, operations |
| Protocol | 2 | Packet encoding, CRC |
| Stress Tests | 2 | Memory, fixed-point performance |
| Hardware Framework | 3 | Failure tracking, counters, thermal |
| Regression | 2 | Determinism, consistency |

### Extended Tests (run_extended_tests.py)

| Category | Tests | Coverage |
|---|---|---|
| Edge Cases | 5 | Empty/max payload, patterns |
| Boundary Conditions | 4 | Screen edges, clipping |
| Protocol Robustness | 4 | All opcodes, error detection |
| UART Simulation | 3 | Clean/noisy/lossy channels |
| GPU Integration | 3 | Command sequences |
| Fixed-Point Edge Cases | 4 | Overflow, underflow, negatives |
| Drawing Edge Cases | 4 | Zero-length, backwards lines |
| Animation/Timing | 3 | Frame timing, interpolation |
| Memory Patterns | 3 | Alignment, pooling, fragmentation |
| Color Conversion | 3 | RGB565, alpha blending |
| Performance Benchmarks | 3 | Encoding/decoding throughput |

### Hardware Tests (run_hardware_tests.py)

| Test | Description |
|---|---|
| GPU/CPU Connection | Verify serial port access |
| GPU Echo | Round-trip communication |
| GPU NOP/Reset | Basic commands |
| GPU Clear/Flip | Display operations |
| GPU Set Pixel | Single pixel write |
| GPU Fill Rect | Rectangle fill |
| GPU Draw Line | Line rendering |
| GPU Rapid Commands | Burst command handling |
| GPU Throughput | Data transfer rate |
| GPU Frame Rate | Achievable FPS |
| CPU to GPU Relay | Command forwarding |

## Test Results Summary

### Latest Run (Virtual Tests)
```
============================================================
   GPU Driver Complete Test Suite Results
============================================================

Test Suites Run:    3
Test Suites Passed: 3
Test Suites Failed: 0
Total Time:         0.54s

Individual Results:
  ✓ PASS  run_virtual_tests.py    (35 tests)
  ✓ PASS  run_extended_tests.py   (39 tests)
  ✓ PASS  run_hardware_tests.py   (skipped - ports in use)

Total: 74 tests PASSED
============================================================
```

## Performance Benchmarks

From extended test suite:
- Packet Encoding: ~235 ops/ms
- Packet Decoding: ~256 ops/ms
- GPU Command Execution: ~1200 ops/ms
- Trig Operations: ~10,500 ops/ms
- Fixed-Point Math: ~10,500 ops/ms
- Bresenham Line: ~140 lines/ms

## Hardware Requirements

For hardware tests:
- **CPU**: ESP32-S3 on COM15 (Arduino framework)
- **GPU**: ESP32-S3 on COM5 (ESP-IDF framework)
- **Baud Rate**: 2,000,000 (2 Mbps)

## Dependencies

```bash
pip install pyserial
```

## Adding New Tests

1. Create test function with `test_` prefix
2. Return `True` for pass, error message for fail
3. Add to appropriate test file
4. Use `runner.run_test("Test Name", test_function)` to register

## Continuous Integration

For CI environments, use:
```bash
python run_all_tests.py --skip-hw
exit $?  # Returns 0 on success, 1 on failure
```

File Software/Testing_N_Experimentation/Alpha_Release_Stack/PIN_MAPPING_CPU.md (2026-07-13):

# CPU Pin Mapping

Source of truth: `env:CPU_Main` → `CPU_Main.cpp` → `LifecycleController` / `CurrentMode` + `Drivers/*`.

Board: ESP32-S3 (`esp32s3_n16`), upload/monitor **COM6**.

---

## I2C (port 0, 400 kHz)

| Signal | GPIO | Devices |
|---|---|---|
| SDA | 9 | ICM20948 (`0x68`), BME280 (`0x76`) |
| SCL | 10 | |

## Buttons (active LOW)

| Button | GPIO | Notes |
|---|---|---|
| A | 5 | Boot: hold for debug menu; with D = system test |
| B | 6 | Select; hold 15s at boot = factory reset |
| C | 7 | Next / down |
| D | 15 | Back / cancel; with A at boot = system test |

## LED strips (WS2812)

| Strip | GPIO | LEDs | Role |
|---|---|---|---|
| 0 | 16 | 0 | Unused |
| 1 | 18 | 13 | Left fin |
| 2 | 8 | 9 | Tongue |
| 3 | 39 | 0 | Unused |
| 4 | 38 | 13 | Right fin |
| 5 | 37 | 14 | Scale LEDs |

## Fans

| Fan | GPIO |
|-----|---|
| 1 | 17 |
| 2 | 36 |

## MicroSD (SPI)

| Signal | GPIO |
|---|---|
| MISO | 14 |
| MOSI | 47 |
| CLK | 21 |
| CS | 48 |

## UART — GPS (UART2, 9600)

| Signal | GPIO | Direction |
|---|---|---|
| TX | 43 | CPU → GPS RX |
| RX | 44 | CPU ← GPS TX |

## UART — CPU↔GPU (UART1, **921600**)

| Signal | GPIO | Direction |
|---|---|---|
| TX | 12 | CPU → GPU RX (GPU GPIO 13) |
| RX | 11 | CPU ← GPU TX (GPU GPIO 12) |

## I2S mic (INMP441)

| Signal | GPIO |
|---|---|
| DOUT / DATA | 2 |
| CLK / BCK | 40 |
| L/R select | 41 |
| WS / LRCLK | 42 |

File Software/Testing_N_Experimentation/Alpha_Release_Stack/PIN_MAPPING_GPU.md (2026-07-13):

# GPU Pin Mapping

Source of truth: `env:GPU_Programmable` → `GPU_Programmable.cpp` (HUB75 pins from ARCOS `HUB75Config::getDefault()` / hardware pinout).

Board: ESP32-S3 (`esp32s3usbotg`), upload/monitor **COM5**.

---

## HUB75 (2× 64×32 → 128×32, dual OE)

Initialized with `begin(true, …)` (dual OE). Colour depth 5-bit, double buffer, gamma 2.2.

### Data

| Signal | GPIO |
|---|---|
| R0 | 7 |
| G0 | 15 |
| B0 | 16 |
| R1 | 17 |
| G1 | 18 |
| B1 | 8 |

### Row address

| Signal | GPIO |
|---|---|
| A | 41 |
| B | 40 |
| C | 39 |
| D | 38 |
| E | 42 |

### Control

| Signal | GPIO | Notes |
|---|---|---|
| CLK | 37 | |
| LAT | 36 | |
| OE | 35 | Left panel (X 0–63) |
| OE2 | 6 | Right panel (X 64–127) |

## I2C — OLED (SH1107 128×128)

| Signal | GPIO | Settings |
|---|---|---|
| SDA | 2 | 400 kHz, addr `0x3C` |
| SCL | 1 | Flip H + V on (upside-down mount); contrast `0xFF` |

## UART — CPU↔GPU (UART1, **921600**)

| Signal | GPIO | Direction |
|---|---|---|
| TX | 12 | GPU → CPU RX (CPU GPIO 11) |
| RX | 13 | GPU ← CPU TX (CPU GPIO 12) |

## GPIO summary

| GPIO | Function |
|---|---|
| 1 | OLED SCL |
| 2 | OLED SDA |
| 6 | HUB75 OE2 |
| 7 | HUB75 R0 |
| 8 | HUB75 B1 |
| 12 | UART TX → CPU |
| 13 | UART RX ← CPU |
| 15 | HUB75 G0 |
| 16 | HUB75 B0 |
| 17 | HUB75 R1 |
| 18 | HUB75 G1 |
| 35 | HUB75 OE |
| 36 | HUB75 LAT |
| 37 | HUB75 CLK |
| 38 | HUB75 D |
| 39 | HUB75 C |
| 40 | HUB75 B |
| 41 | HUB75 A |
| 42 | HUB75 E |

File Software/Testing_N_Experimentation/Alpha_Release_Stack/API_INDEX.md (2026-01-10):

# Lucidus/ARCOS API Documentation Index

## Overview

This document serves as the master index for all API documentation in the Lucidus project (powered by ARCOS - Autonomous Robotic Control & Operations System). Lucidus is an ESP32-S3 based animatronic eye display system with WiFi configuration, LED matrix displays, and a comprehensive sensor suite.

## System Architecture

```
┌─────────────────────────────────────────────────────────────────┐
│                     APPLICATION LAYER                           │
│  ┌───────────────┬──────────────────┬───────────────────────┐  │
│  │ BootMode      │ CurrentMode      │ CaptivePortalManager  │  │
│  │ (startup)     │ (runtime)        │ (web configuration)   │  │
│  └───────────────┴──────────────────┴───────────────────────┘  │
│  ┌───────────────────────────────────────────────────────────┐  │
│  │            EyeDisplayController (animations)              │  │
│  └───────────────────────────────────────────────────────────┘  │
├─────────────────────────────────────────────────────────────────┤
│                      SYSTEM API LAYER                           │
│  ┌─────────────┬─────────────┬──────────────┬───────────────┐  │
│  │   Network   │   Config    │   Security   │      UI       │  │
│  │  WiFiDriver │ EyeConfig   │ SecurityDrv  │  (future)     │  │
│  │  Portal     │ Storage     │ TRNG/Creds   │               │  │
│  └─────────────┴─────────────┴──────────────┴───────────────┘  │
├─────────────────────────────────────────────────────────────────┤
│                  MIDDLEWARE / GPU DRIVER                        │
│  ┌───────────────────────────────────────────────────────────┐  │
│  │  GpuDriver │ GpuRenderer │ GpuCommands │ GpuAnimations   │  │
│  └───────────────────────────────────────────────────────────┘  │
├─────────────────────────────────────────────────────────────────┤
│                   HAL (Hardware Abstraction)                    │
│  ┌─────────────┬─────────────┬─────────────┬─────────────────┐ │
│  │   Timer     │    GPIO     │    I2C      │    UART         │ │
│  │   I2S       │    SPI      │   IMU       │    GPS          │ │
│  │   Display   │  LEDStrip   │  Storage    │   Microphone    │ │
│  └─────────────┴─────────────┴─────────────┴─────────────────┘ │
├─────────────────────────────────────────────────────────────────┤
│              ESP32-S3 Platform (ESP-IDF 5.5.0)                  │
└─────────────────────────────────────────────────────────────────┘
```

---

## Quick Start

### Connecting to Lucidus

1. **Power on** the device
2. **Connect to WiFi**: Look for `Lucidus_XXXX` network
3. **Open browser**: Navigate to `http://10.0.0.1`
4. **Configure**: Use the web interface to customize eyes, animations, and settings

### Building & Uploading

```bash
# Build and upload to CPU (main processor)
pio run -e CPU_Main -t upload

# Build and upload to GPU (display processor)
pio run -e GPU_Programmable -t upload

# Monitor serial output
pio device monitor -p COM15 -b 115200
```

---

## API Layers

### 1. Application Layer

High-level application logic including modes and managers.

| File | Location | Description |
|---|---|---|
| `CPU_Main.cpp` | [src/CPU_Main.cpp](src/CPU_Main.cpp) | Main entry point |
| `BootMode` | [src/Modes/BootMode.hpp](src/Modes/BootMode.hpp) | Startup sequence, WiFi init |
| `CurrentMode` | [src/Modes/CurrentMode.hpp](src/Modes/CurrentMode.hpp) | Runtime eye display mode |
| `CaptivePortalManager` | [src/Application/CaptivePortalManager.hpp](src/Application/CaptivePortalManager.hpp) | Web portal orchestration |
| `EyeDisplayController` | [src/Application/EyeDisplayController.hpp](src/Application/EyeDisplayController.hpp) | Eye rendering & animation |

---

### 2. System API Layer

Platform services for networking, configuration, and security.
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

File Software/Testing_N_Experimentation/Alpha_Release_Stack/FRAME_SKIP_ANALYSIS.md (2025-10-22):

# Frame Skip Analysis Report

## Summary
Frame skip detection has been implemented and tested. The system shows **excellent frame delivery** with minimal skipping.

## Test Results (Sample)
```
Frame 60  | Counter=49 | Skipped=3 (0.6%)
Frame 120 | Counter=30 | Skipped=3 (0.3%)
Frame 180 | Counter=28 | Skipped=3 (0.2%)
```

**Conclusion**: Only **3 frames skipped out of 180 received** = **0.2% skip rate**

## Implementation Details
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

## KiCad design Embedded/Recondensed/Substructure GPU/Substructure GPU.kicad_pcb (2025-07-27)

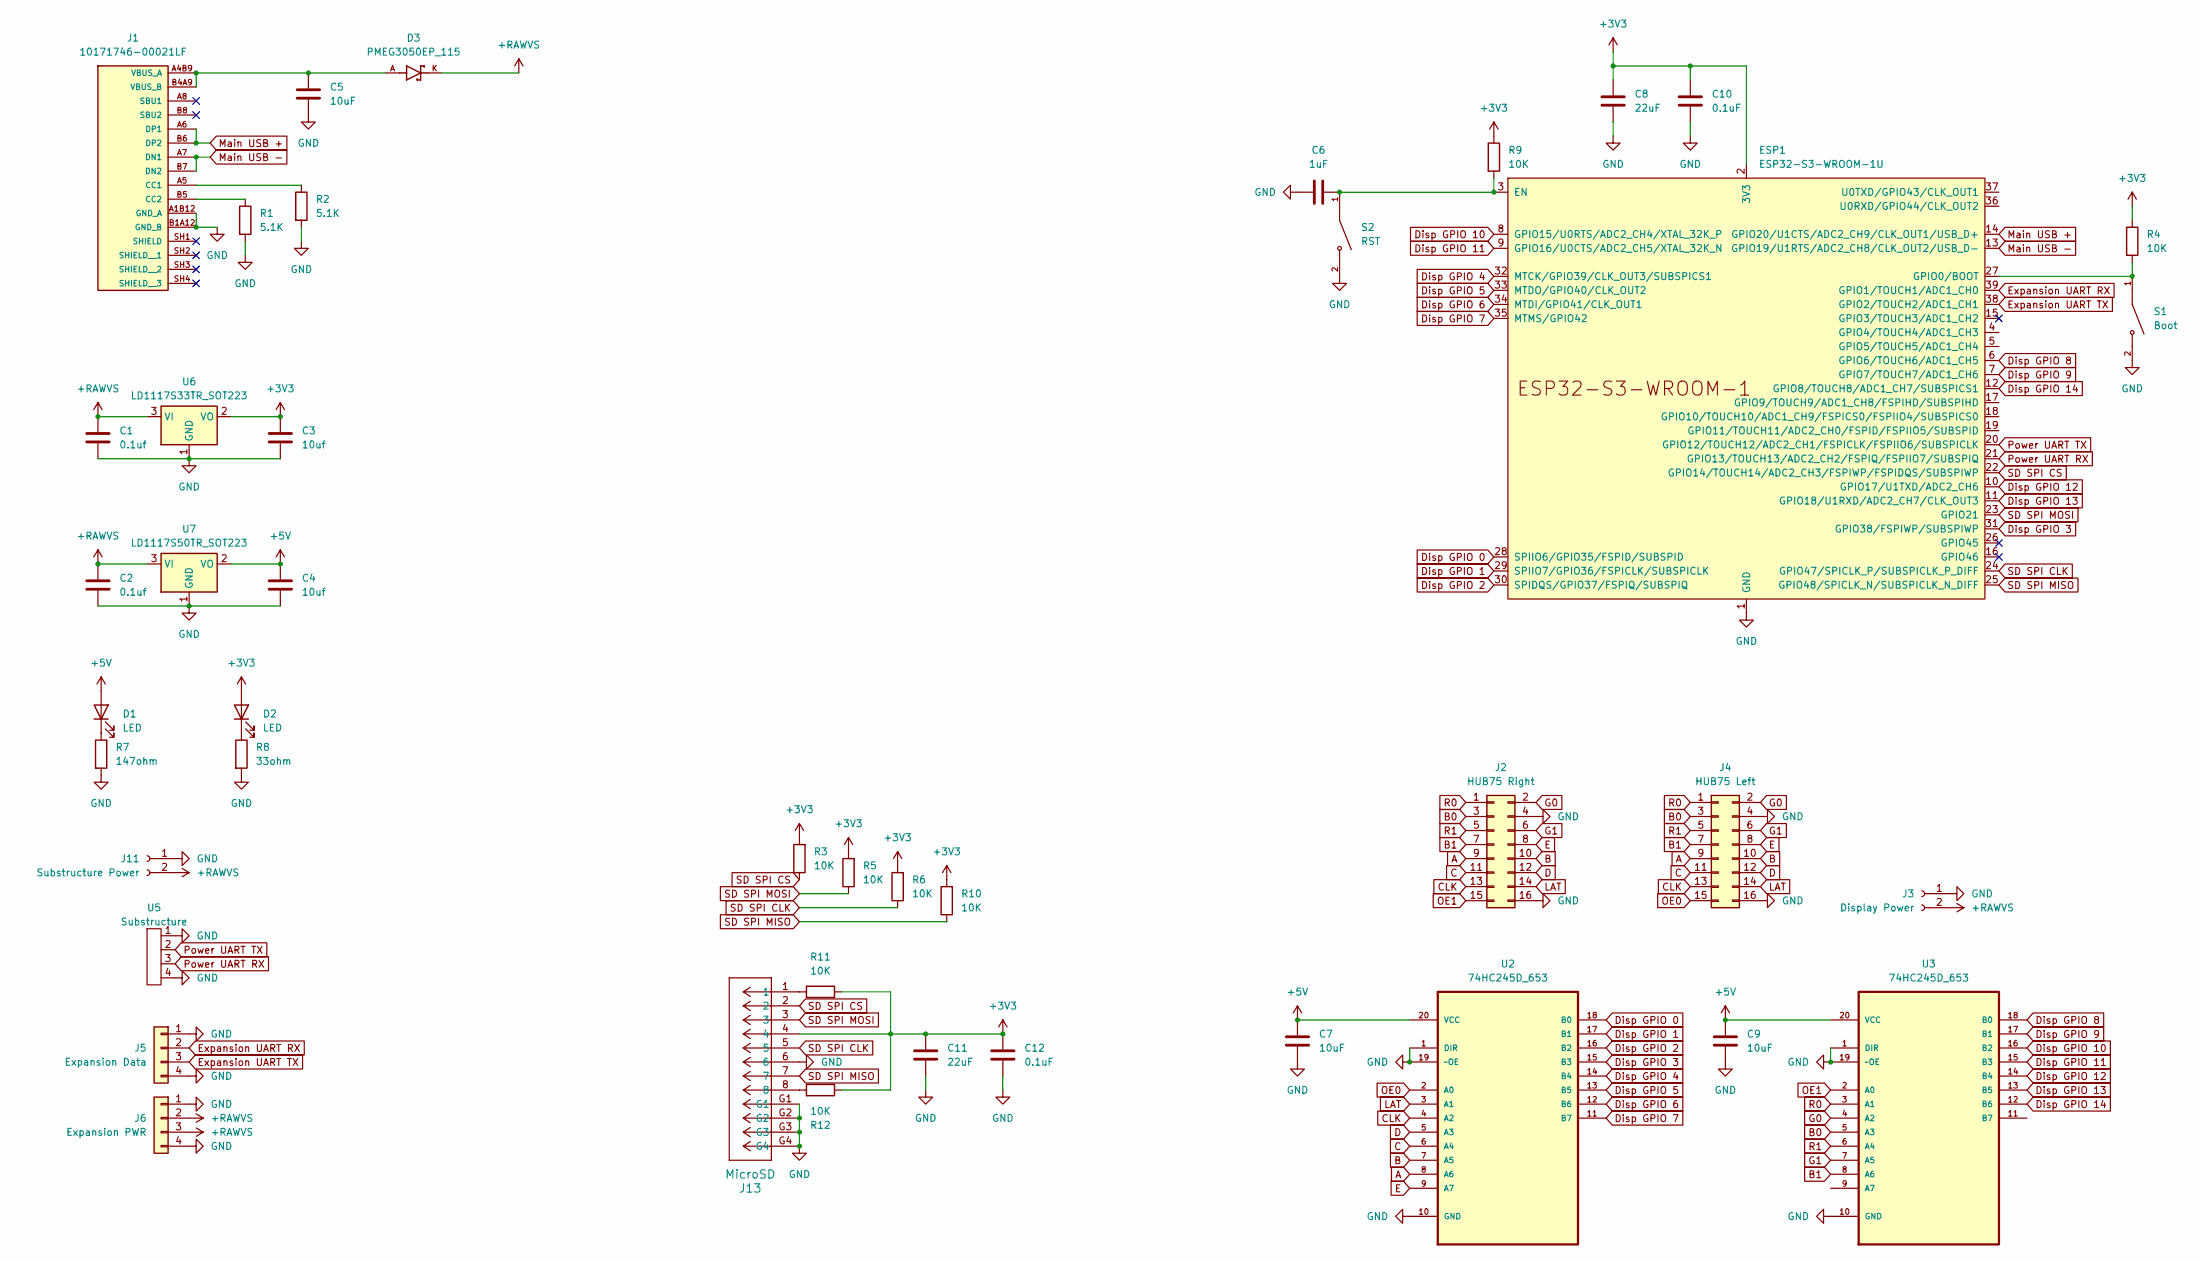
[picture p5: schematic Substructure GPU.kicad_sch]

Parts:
C1, C2: 0.1uf; C_0603_1608Metric_Pad1.08x0.95mm_HandSolder; LCSC C1591
C3, C4: 10uf; C_0603_1608Metric_Pad1.08x0.95mm_HandSolder; LCSC C3039698
C5: 10uF; C_0603_1608Metric; LCSC C3039698
C6: 1uF; C_0603_1608Metric_Pad1.08x0.95mm_HandSolder; LCSC C95843
C7, C9: 10uF; C_0603_1608Metric_Pad1.08x0.95mm_HandSolder; LCSC C3039698
C8, C11: 22uF; C_0603_1608Metric_Pad1.08x0.95mm_HandSolder; LCSC C84419
C10, C12: 0.1uF; C_0603_1608Metric_Pad1.08x0.95mm_HandSolder; LCSC C1591
D1, D2: LED; D_0603_1608Metric_Pad1.05x0.95mm_HandSolder; LCSC C7207730
D3: PMEG3050EP_115; DIO_PMEG3050EP_115; LCSC C50603
ESP1: ESP32-S3-WROOM-1U
J1: 10171746-00021LF; MOLEX_2171790001; PARTREV A; LCSC C3197684
J2: HUB75 Right; PinHeader_2x08_P2.54mm_Vertical; LCSC C492425
J3: Display Power; AMASS_XT30U-M_1x02_P5.0mm_Vertical
J4: HUB75 Left; PinHeader_2x08_P2.54mm_Vertical; LCSC C492425
J5: Expansion Data; PinSocket_1x04_P2.54mm_Vertical
J6: Expansion PWR; PinSocket_1x04_P2.54mm_Vertical
J11: Substructure Power; AMASS_XT30U-M_1x02_P5.0mm_Vertical
J13: MicroSD; MicroSD_473092651; LCSC C587826
R1, R2: 5.1K; R_0603_1608Metric; LCSC C328432
R3, R4, R5, R6, R9, R10, R11, R12: 10K; R_0603_1608Metric; LCSC C98220
R7: 147ohm; C_0603_1608Metric_Pad1.08x0.95mm_HandSolder; LCSC C2930065
R8: 33ohm; C_0603_1608Metric_Pad1.08x0.95mm_HandSolder; LCSC C105588
S1: Boot; SW_B3U-1000P; LCSC C231329
S2: RST; SW_B3U-1000P; LCSC C231329
U2, U3: 74HC245D_653; SOIC127P1032X265-20N; MPN 74HC245D,653; LCSC C5625
U5: Substructure; FFC-4-0.5
U6: LD1117S33TR_SOT223; SOT-223-3_TabPin2; LCSC C86781
U7: LD1117S50TR_SOT223; SOT-223-3_TabPin2; LCSC C134077

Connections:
+3V3: C3.1, C8.1, C10.1, C11.1, C12.1, D2.2 (A), ESP1.2 (3V3), J13.4, R3.2, R4.1, R5.2, R6.2, R9.1, R10.2, R11.1, R12.1, U6.2 (VO)
+5V: C4.1, C7.1, C9.1, D1.2 (A), U2.20 (VCC), U3.20 (VCC), U7.2 (VO)
+RAWVS: C1.1, C2.1, D3.K, J3.2, J6.2, J6.3, J11.2, U6.3 (VI), U7.3 (VI)
A: J2.9, J4.9, U2.8 (A6)
B: J2.10, J4.10, U2.7 (A5)
B0: J2.3, J4.3, U3.5 (A3)
B1: J2.7, J4.7, U3.8 (A6)
C: J2.11, J4.11, U2.6 (A4)
CLK: J2.13, J4.13, U2.4 (A2)
D: J2.12, J4.12, U2.5 (A3)
Disp GPIO 0: ESP1.28 (SPIIO6/GPIO35/FSPID/SUBSPID), U2.18 (B0)
Disp GPIO 1: ESP1.29 (SPIIO7/GPIO36/FSPICLK/SUBSPICLK), U2.17 (B1)
Disp GPIO 2: ESP1.30 (SPIDQS/GPIO37/FSPIQ/SUBSPIQ), U2.16 (B2)
Disp GPIO 3: ESP1.31 (GPIO38/FSPIWP/SUBSPIWP), U2.15 (B3)
Disp GPIO 4: ESP1.32 (MTCK/GPIO39/CLK_OUT3/SUBSPICS1), U2.14 (B4)
Disp GPIO 5: ESP1.33 (MTDO/GPIO40/CLK_OUT2), U2.13 (B5)
Disp GPIO 6: ESP1.34 (MTDI/GPIO41/CLK_OUT1), U2.12 (B6)
Disp GPIO 7: ESP1.35 (MTMS/GPIO42), U2.11 (B7)
Disp GPIO 8: ESP1.6 (GPIO6/TOUCH6/ADC1_CH5), U3.18 (B0)
Disp GPIO 9: ESP1.7 (GPIO7/TOUCH7/ADC1_CH6), U3.17 (B1)
Disp GPIO 10: ESP1.8 (GPIO15/U0RTS/ADC2_CH4/XTAL_32K_P), U3.16 (B2)
Disp GPIO 11: ESP1.9 (GPIO16/U0CTS/ADC2_CH5/XTAL_32K_N), U3.15 (B3)
Disp GPIO 12: ESP1.10 (GPIO17/U1TXD/ADC2_CH6), U3.14 (B4)
Disp GPIO 13: ESP1.11 (GPIO18/U1RXD/ADC2_CH7/CLK_OUT3), U3.13 (B5)
Disp GPIO 14: ESP1.12 (GPIO8/TOUCH8/ADC1_CH7/SUBSPICS1), U3.12 (B6)
E: J2.8, J4.8, U2.9 (A7)
Expansion UART RX: ESP1.39 (GPIO1/TOUCH1/ADC1_CH0), J5.2
Expansion UART TX: ESP1.38 (GPIO2/TOUCH2/ADC1_CH1), J5.3
G0: J2.2, J4.2, U3.4 (A2)
G1: J2.6, J4.6, U3.7 (A5)
GND: C1.2, C2.2, C3.2, C4.2, C5.2, C6.1, C7.2, C8.2, C9.2, C10.2, C11.2, C12.2, ESP1.1 (GND), ESP1.40 (GND), ESP1.41 (GND), J1.A1B12 (GND_A), J1.B1A12 (GND_B), J2.4, J2.16, J3.1, J4.4, J4.16, J5.1, J5.4, J6.1, J6.4, J11.1, J13.6, J13.G1, J13.G2, J13.G3, J13.G4, R1.2, R2.2, R7.2, R8.2, S1.2, S2.2, U2.1 (DIR), U2.10 (GND), U2.19 (~OE), U3.1 (DIR), U3.10 (GND), U3.19 (~OE), U5.1, U5.4, U6.1 (GND), U7.1 (GND)
LAT: J2.14, J4.14, U2.3 (A1)
Main USB +: ESP1.14 (GPIO20/U1CTS/ADC2_CH9/CLK_OUT1/USB_D+), J1.A6 (DP1), J1.B6 (DP2)
Main USB -: ESP1.13 (GPIO19/U1RTS/ADC2_CH8/CLK_OUT2/USB_D-), J1.A7 (DN1), J1.B7 (DN2)
unnamed: D1.1 (K), R7.1
unnamed: D2.1 (K), R8.1
unnamed: C6.2, ESP1.3 (EN), R9.2, S2.1
unnamed: ESP1.27 (GPIO0/BOOT), R4.2, S1.1
unnamed: J1.A5 (CC1), R2.1
unnamed: J1.B5 (CC2), R1.1
unnamed: C5.1, D3.A, J1.A4B9 (VBUS_A), J1.B4A9 (VBUS_B)
unnamed: J13.1, R11.2
unnamed: J13.8, R12.2
OE0: J4.15, U2.2 (A0)
OE1: J2.15, U3.2 (A0)
Power UART RX: ESP1.21 (GPIO13/TOUCH13/ADC2_CH2/FSPIQ/FSPIIO7/S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), U5.3
Power UART TX: ESP1.20 (GPIO12/TOUCH12/ADC2_CH1/FSPICLK/FSPIIO6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), U5.2
R0: J2.1, J4.1, U3.3 (A1)
R1: J2.5, J4.5, U3.6 (A4)
SD SPI CLK: ESP1.24 (GPIO47/SPICLK_P/SUBSPICLK_P_DIFF), J13.5, R6.1
SD SPI CS: ESP1.22 (GPIO14/TOUCH14/ADC2_CH3/FSPIWP/FSPIDQS/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), J13.2, R3.1
SD SPI MISO: ESP1.25 (GPIO48/SPICLK_N/SUBSPICLK_N_DIFF), J13.7, R10.1
SD SPI MOSI: ESP1.23 (GPIO21), J13.3, R5.1

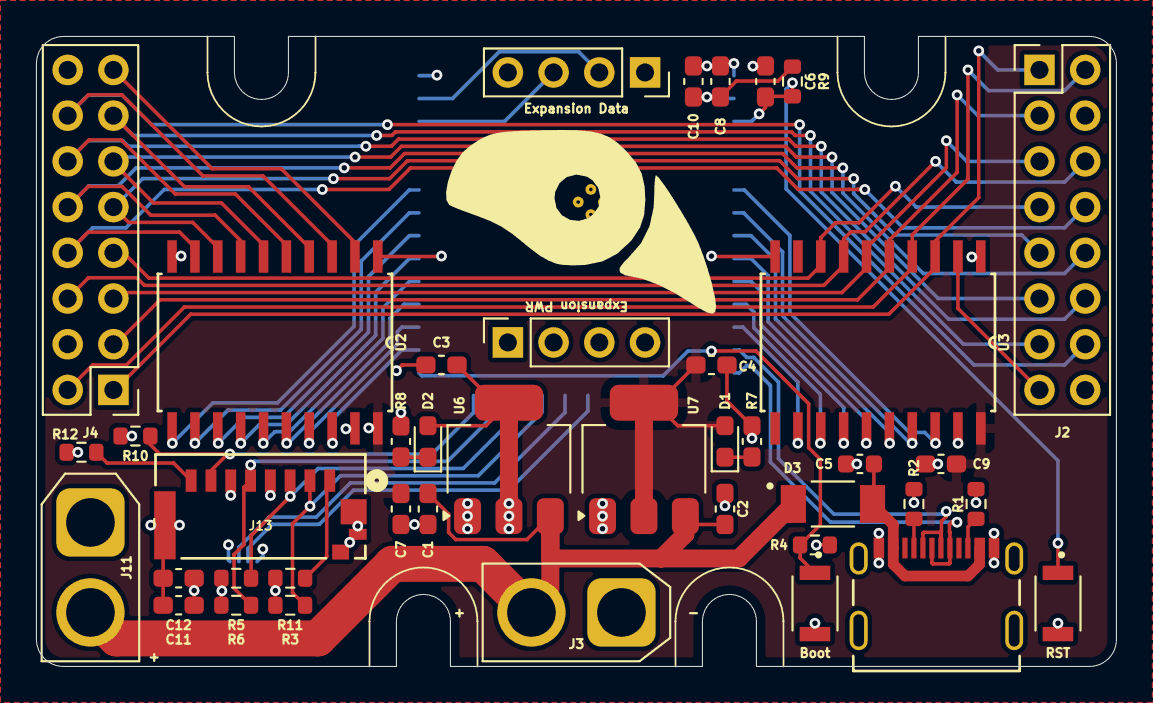
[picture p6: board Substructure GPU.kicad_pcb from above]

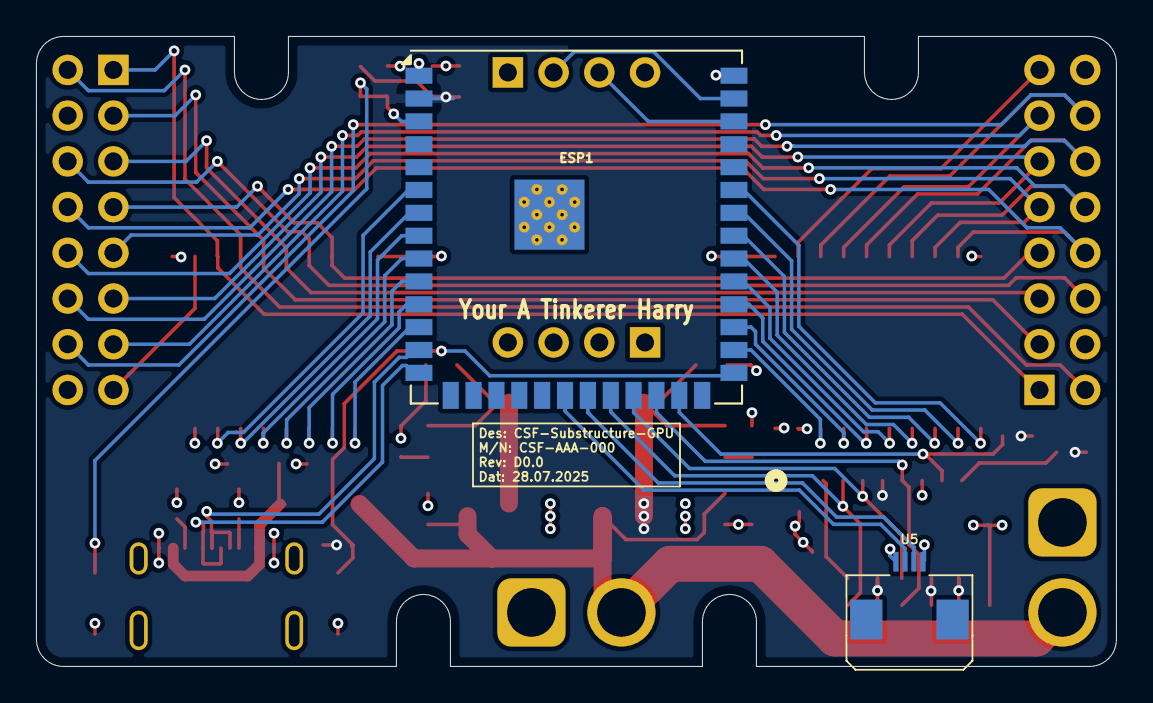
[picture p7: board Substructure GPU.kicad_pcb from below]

Board: 4 copper layers, 60.0 x 35.0 mm, 43 parts (2 on the bottom side), 53 nets.

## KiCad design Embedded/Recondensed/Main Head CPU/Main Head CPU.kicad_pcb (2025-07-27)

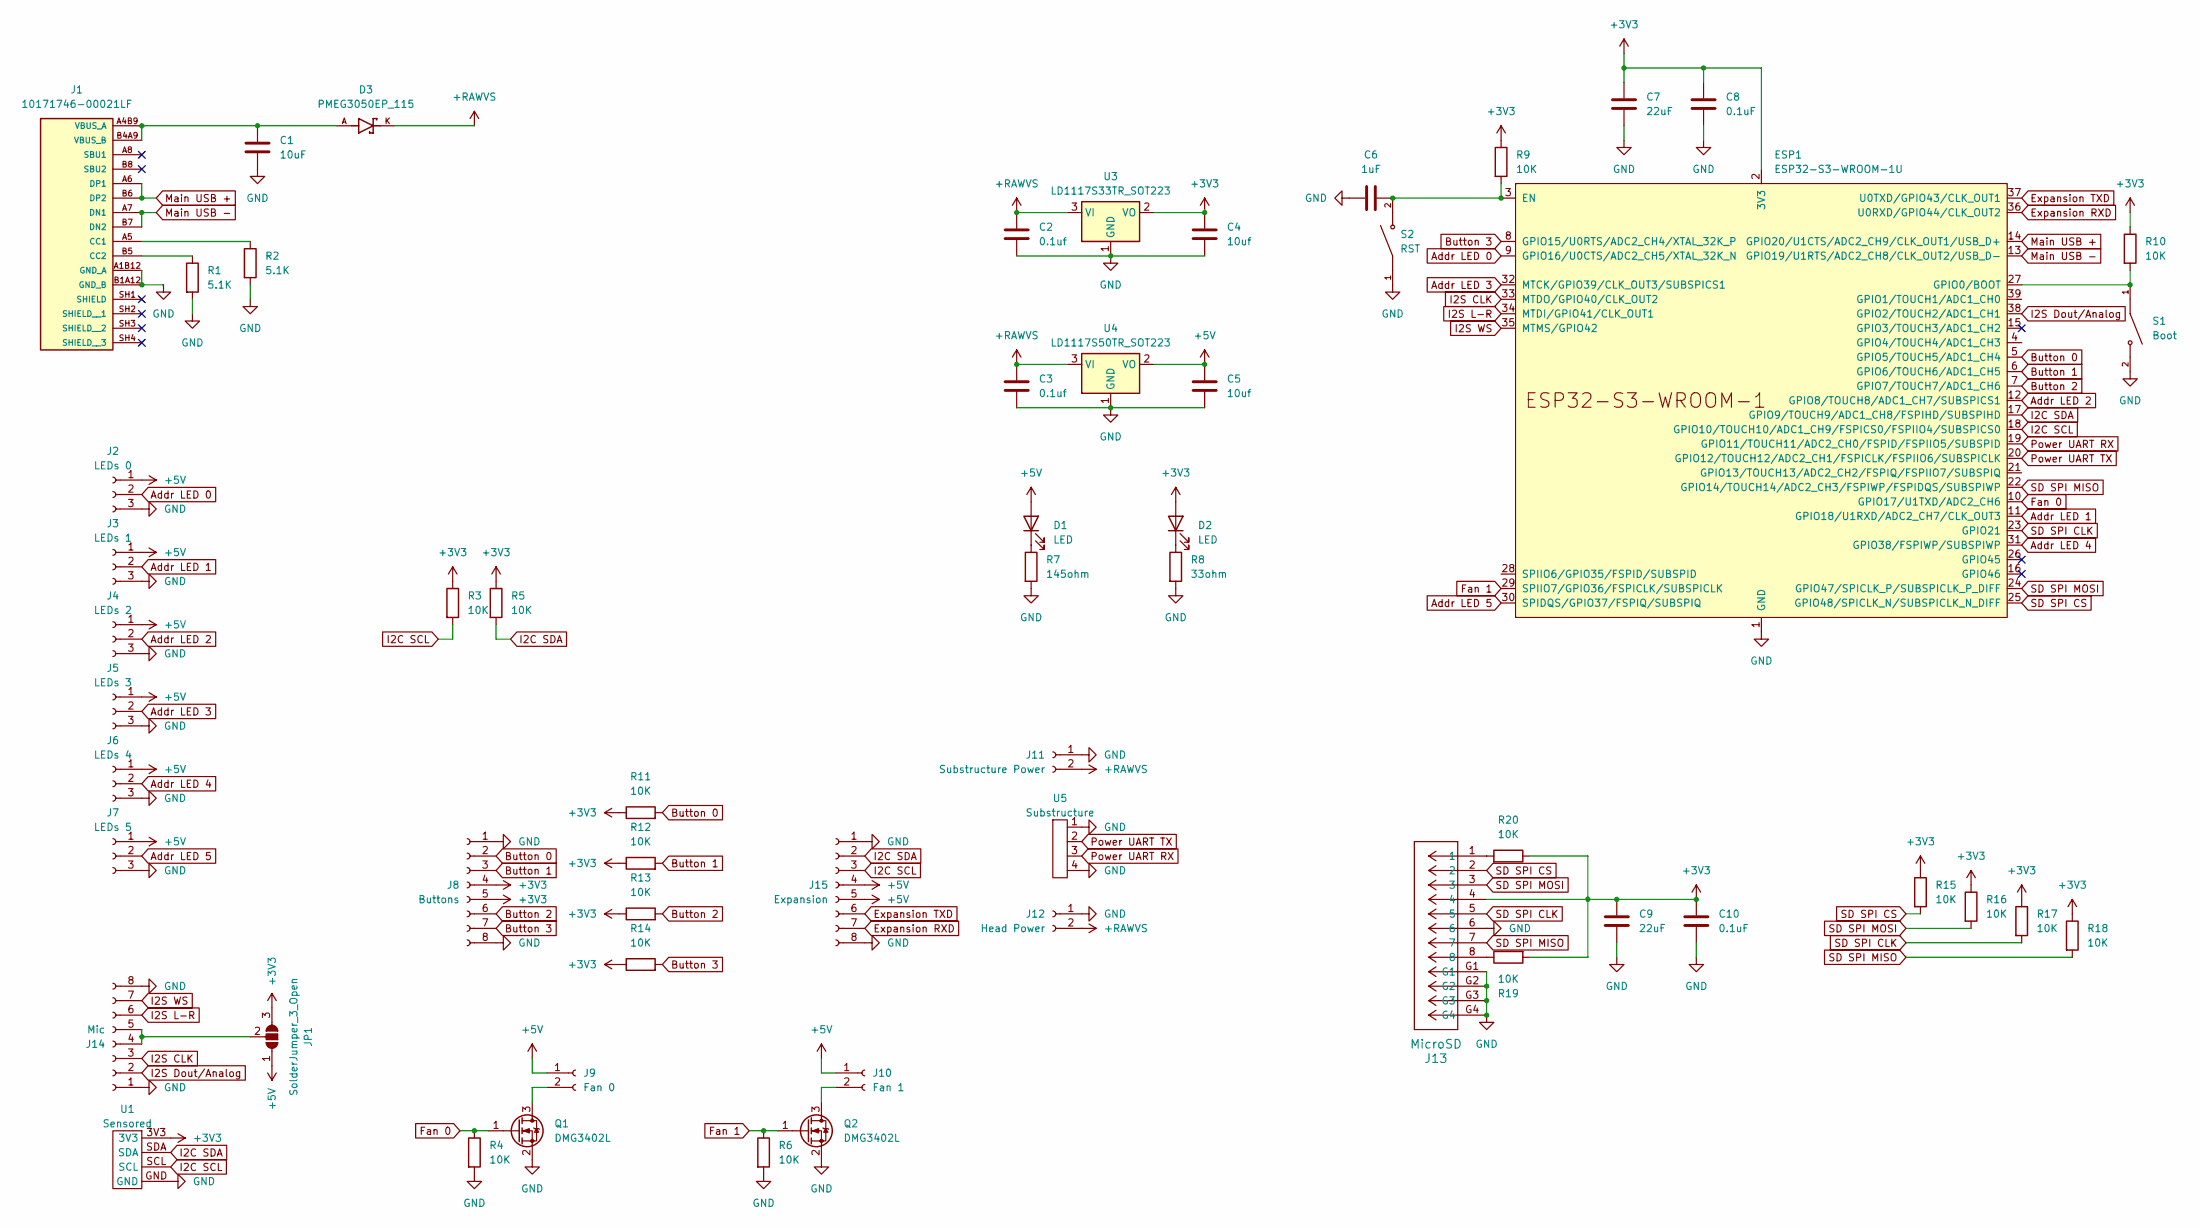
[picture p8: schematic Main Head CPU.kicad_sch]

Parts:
C1: 10uF; C_0603_1608Metric; LCSC C3039698
C2, C3: 0.1uf; C_0603_1608Metric_Pad1.08x0.95mm_HandSolder; LCSC C1591
C4, C5: 10uf; C_0603_1608Metric_Pad1.08x0.95mm_HandSolder; LCSC C3039698
C6: 1uF; C_0603_1608Metric_Pad1.08x0.95mm_HandSolder; LCSC C95843
C7, C9: 22uF; C_0603_1608Metric_Pad1.08x0.95mm_HandSolder; LCSC C84419
C8, C10: 0.1uF; C_0603_1608Metric_Pad1.08x0.95mm_HandSolder; LCSC C1591
D1, D2: LED; D_0603_1608Metric_Pad1.05x0.95mm_HandSolder; LCSC C7207730
D3: PMEG3050EP_115; DIO_PMEG3050EP_115; LCSC C50603
ESP1: ESP32-S3-WROOM-1U
J1: 10171746-00021LF; MOLEX_2171790001; PARTREV A; LCSC C3197684
J2: LEDs 0; JST_GH_SM03B-GHS-TB_1x03-1MP_P1.25mm_Horizontal; LCSC C514175
J3: LEDs 1; JST_GH_SM03B-GHS-TB_1x03-1MP_P1.25mm_Horizontal; LCSC C514175
J4: LEDs 2; JST_GH_SM03B-GHS-TB_1x03-1MP_P1.25mm_Horizontal; LCSC C514175
J5: LEDs 3; JST_GH_SM03B-GHS-TB_1x03-1MP_P1.25mm_Horizontal; LCSC C514175
J6: LEDs 4; JST_GH_SM03B-GHS-TB_1x03-1MP_P1.25mm_Horizontal; LCSC C514175
J7: LEDs 5; JST_GH_SM03B-GHS-TB_1x03-1MP_P1.25mm_Horizontal; LCSC C514175
J8: Buttons; JST_GH_SM08B-GHS-TB_1x08-1MP_P1.25mm_Horizontal; LCSC C265111
J9: Fan 0; JST_GH_SM02B-GHS-TB_1x02-1MP_P1.25mm_Horizontal; LCSC C189893
J10: Fan 1; JST_GH_SM02B-GHS-TB_1x02-1MP_P1.25mm_Horizontal; LCSC C189893
J11: Substructure Power; AMASS_XT30PW-M_1x02_P2.50mm_Horizontal
J12: Head Power; AMASS_XT30PW-M_1x02_P2.50mm_Horizontal
J13: MicroSD; MicroSD_473092651; LCSC C587826
J14: Mic; JST_GH_SM08B-GHS-TB_1x08-1MP_P1.25mm_Horizontal; LCSC C265111
J15: Expansion; JST_GH_SM08B-GHS-TB_1x08-1MP_P1.25mm_Horizontal; LCSC C265111
JP1: SolderJumper_3_Open; SolderJumper-3_P1.3mm_Open_RoundedPad1.0x1.5mm
Q1, Q2: DMG3402L; SOT-23; LCSC C96614
R1, R2: 5.1K; R_0603_1608Metric; LCSC C328432
R3, R4, R5, R6, R11, R12, R13, R14, R15, R16, R17, R18, R19, R20: 10K; R_0603_1608Metric_Pad0.98x0.95mm_HandSolder; LCSC C98220
R7: 145ohm; C_0603_1608Metric_Pad1.08x0.95mm_HandSolder; LCSC C2930065
R8: 33ohm; C_0603_1608Metric_Pad1.08x0.95mm_HandSolder; LCSC C108661
R9, R10: 10K; R_0603_1608Metric; LCSC C98220
S1: Boot; SW_B3U-1000P; LCSC C231329
S2: RST; SW_B3U-1000P; LCSC C231329
U1: Sensored
U3: LD1117S33TR_SOT223; SOT-223-3_TabPin2; LCSC C86781
U4: LD1117S50TR_SOT223; SOT-223-3_TabPin2; LCSC C134077
U5: Substructure; FFC-4-0.5

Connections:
+3V3: C4.1, C7.1, C8.1, C9.1, C10.1, D2.2 (A), ESP1.2 (3V3), J8.4, J8.5, J13.4, JP1.3 (B), R3.1, R5.1, R9.1, R10.1, R11.1, R12.1, R13.1, R14.1, R15.1, R16.1, R17.1, R18.1, R19.2, R20.1, U1.3V3, U3.2 (VO)
+5V: C5.1, D1.2 (A), J2.1, J3.1, J4.1, J5.1, J6.1, J7.1, J9.1, J10.1, J15.4, J15.5, JP1.1 (A), U4.2 (VO)
+RAWVS: C2.1, C3.1, D3.K, J11.2, J12.2, U3.3 (VI), U4.3 (VI)
Addr LED 0: ESP1.9 (GPIO16/U0CTS/ADC2_CH5/XTAL_32K_N), J2.2
Addr LED 1: ESP1.11 (GPIO18/U1RXD/ADC2_CH7/CLK_OUT3), J3.2
Addr LED 2: ESP1.12 (GPIO8/TOUCH8/ADC1_CH7/SUBSPICS1), J4.2
Addr LED 3: ESP1.32 (MTCK/GPIO39/CLK_OUT3/SUBSPICS1), J5.2
Addr LED 4: ESP1.31 (GPIO38/FSPIWP/SUBSPIWP), J6.2
Addr LED 5: ESP1.30 (SPIDQS/GPIO37/FSPIQ/SUBSPIQ), J7.2
Button 0: ESP1.5 (GPIO5/TOUCH5/ADC1_CH4), J8.2, R11.2
Button 1: ESP1.6 (GPIO6/TOUCH6/ADC1_CH5), J8.3, R12.2
Button 2: ESP1.7 (GPIO7/TOUCH7/ADC1_CH6), J8.6, R13.2
Button 3: ESP1.8 (GPIO15/U0RTS/ADC2_CH4/XTAL_32K_P), J8.7, R14.2
Expansion RXD: ESP1.36 (U0RXD/GPIO44/CLK_OUT2), J15.7
Expansion TXD: ESP1.37 (U0TXD/GPIO43/CLK_OUT1), J15.6
Fan 0: ESP1.10 (GPIO17/U1TXD/ADC2_CH6), Q1.1 (G), R4.1
Fan 1: ESP1.29 (SPIIO7/GPIO36/FSPICLK/SUBSPICLK), Q2.1 (G), R6.1
GND: C1.2, C2.2, C3.2, C4.2, C5.2, C6.1, C7.2, C8.2, C9.2, C10.2, ESP1.1 (GND), ESP1.40 (GND), ESP1.41 (GND), J1.A1B12 (GND_A), J1.B1A12 (GND_B), J2.3, J3.3, J4.3, J5.3, J6.3, J7.3, J8.1, J8.8, J11.1, J12.1, J13.6, J13.G1, J13.G2, J13.G3, J13.G4, J14.1, J14.8, J15.1, J15.8, Q1.2 (S), Q2.2 (S), R1.2, R2.2, R4.2, R6.2, R7.2, R8.2, S1.2, S2.1, U1.GND, U3.1 (GND), U4.1 (GND), U5.1, U5.4
I2C SCL: ESP1.18 (GPIO10/TOUCH10/ADC1_CH9/FSPICS0/FSPIIO4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), J15.3, R3.2, U1.SCL
I2C SDA: ESP1.17 (GPIO9/TOUCH9/ADC1_CH8/FSPIHD/SUBSPIHD), J15.2, R5.2, U1.SDA
I2S CLK: ESP1.33 (MTDO/GPIO40/CLK_OUT2), J14.3
I2S Dout/Analog: ESP1.38 (GPIO2/TOUCH2/ADC1_CH1), J14.2
I2S L-R: ESP1.34 (MTDI/GPIO41/CLK_OUT1), J14.6
I2S WS: ESP1.35 (MTMS/GPIO42), J14.7
Main USB +: ESP1.14 (GPIO20/U1CTS/ADC2_CH9/CLK_OUT1/USB_D+), J1.A6 (DP1), J1.B6 (DP2)
Main USB -: ESP1.13 (GPIO19/U1RTS/ADC2_CH8/CLK_OUT2/USB_D-), J1.A7 (DN1), J1.B7 (DN2)
unnamed: D1.1 (K), R7.1
unnamed: D2.1 (K), R8.1
unnamed: C6.2, ESP1.3 (EN), R9.2, S2.2
unnamed: ESP1.27 (GPIO0/BOOT), R10.2, S1.1
unnamed: J1.A5 (CC1), R2.1
unnamed: J1.B5 (CC2), R1.1
unnamed: C1.1, D3.A, J1.A4B9 (VBUS_A), J1.B4A9 (VBUS_B)
unnamed: J9.2, Q1.3 (D)
unnamed: J10.2, Q2.3 (D)
unnamed: J13.1, R20.2
unnamed: J13.8, R19.1
unnamed: J14.4, J14.5, JP1.2 (C)
Power UART RX: ESP1.19 (GPIO11/TOUCH11/ADC2_CH0/FSPID/FSPIIO5/S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), U5.3
Power UART TX: ESP1.20 (GPIO12/TOUCH12/ADC2_CH1/FSPICLK/FSPIIO6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), U5.2
SD SPI CLK: ESP1.23 (GPIO21), J13.5, R17.2
SD SPI CS: ESP1.25 (GPIO48/SPICLK_N/SUBSPICLK_N_DIFF), J13.2, R15.2
SD SPI MISO: ESP1.22 (GPIO14/TOUCH14/ADC2_CH3/FSPIWP/FSPIDQS/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), J13.7, R18.2
SD SPI MOSI: ESP1.24 (GPIO47/SPICLK_P/SUBSPICLK_P_DIFF), J13.3, R16.2

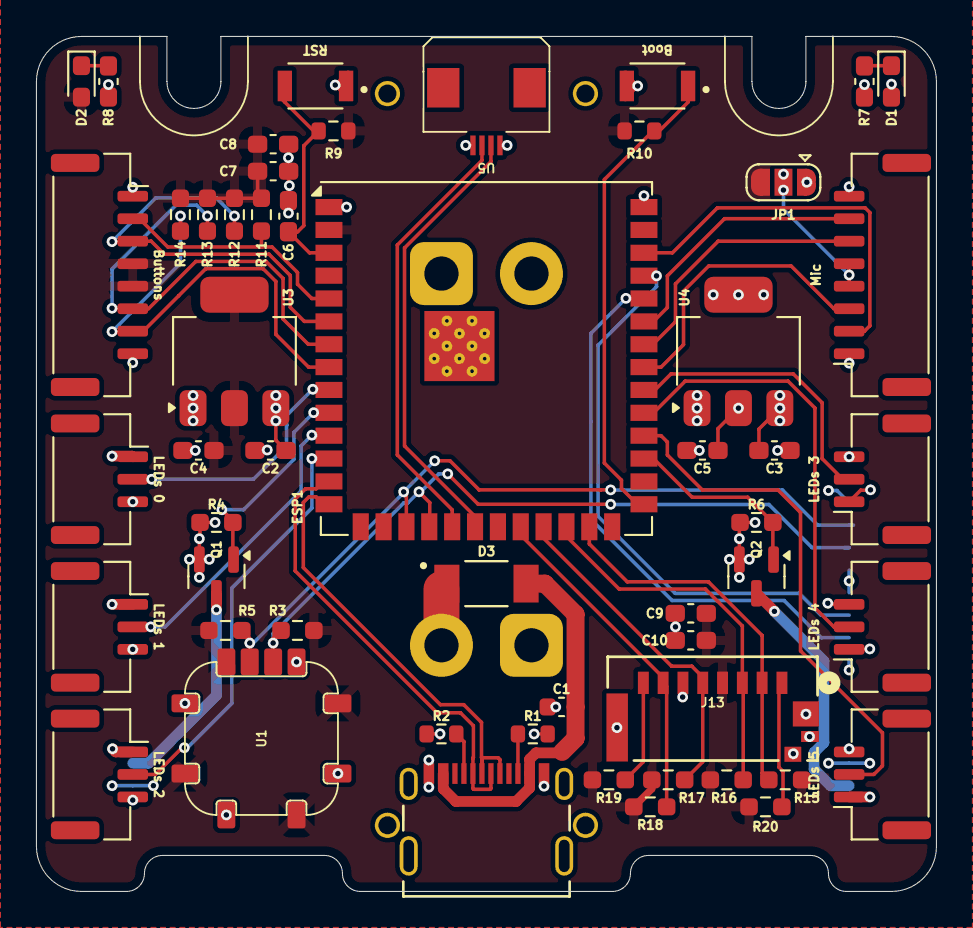
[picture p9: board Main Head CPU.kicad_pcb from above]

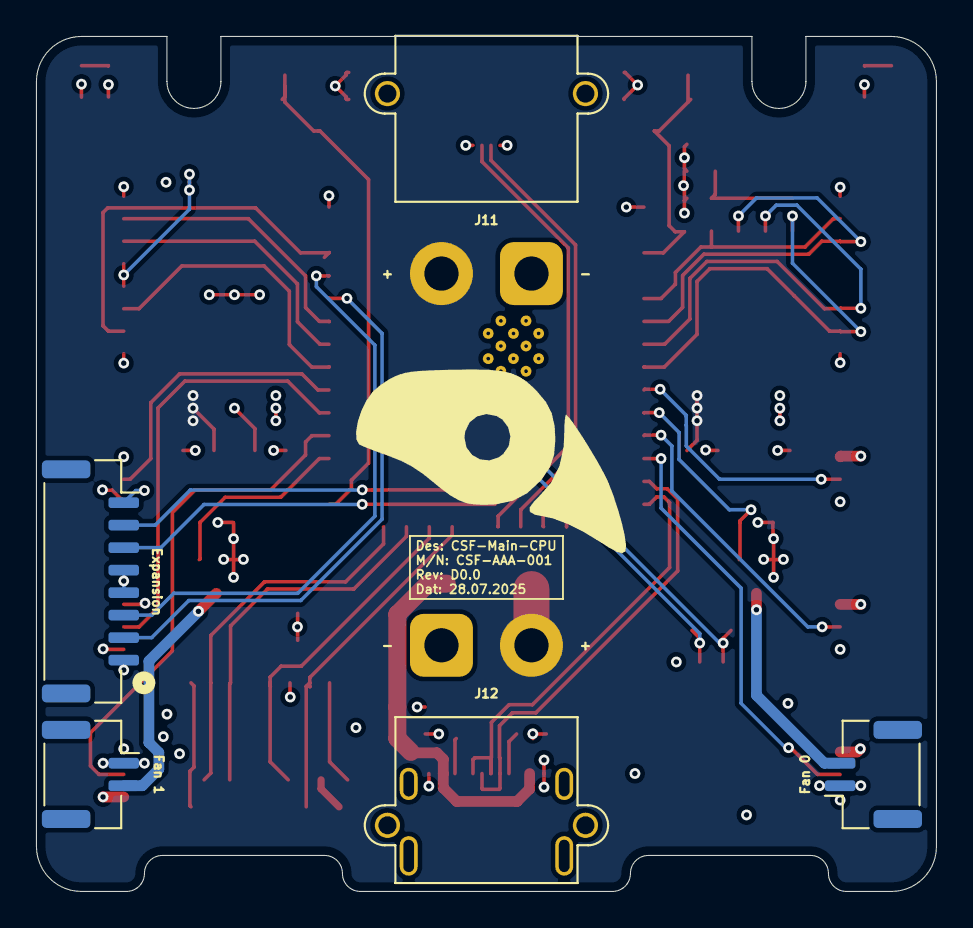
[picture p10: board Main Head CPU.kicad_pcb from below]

Board: 4 copper layers, 50.0 x 47.5 mm, 58 parts (5 on the bottom side), 44 nets.

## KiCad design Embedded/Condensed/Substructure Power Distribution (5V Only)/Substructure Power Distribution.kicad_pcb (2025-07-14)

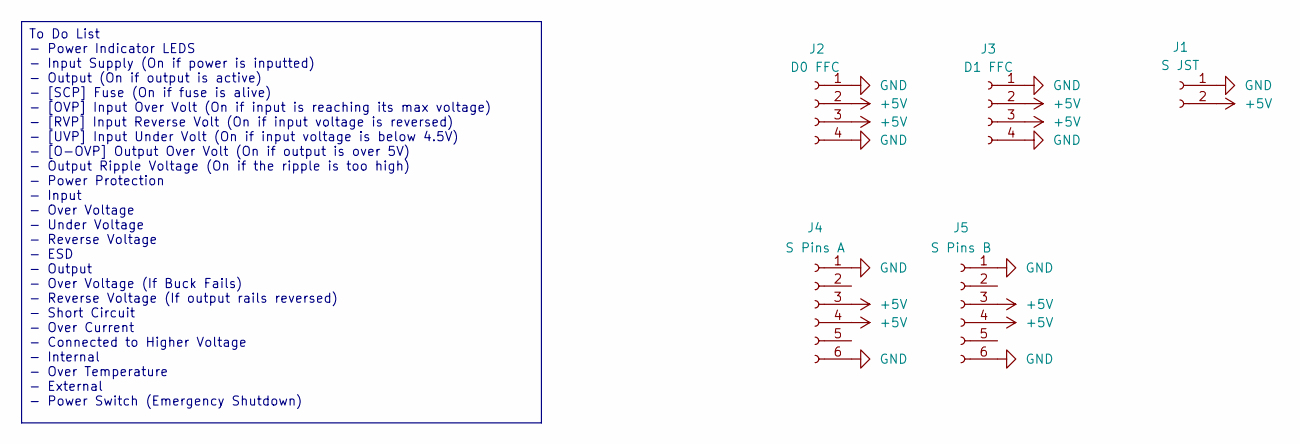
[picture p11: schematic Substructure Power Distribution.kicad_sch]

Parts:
J1: S JST; AMASS_XT30PW-M_1x02_P2.50mm_Horizontal
J2: D0 FFC; JST_XH_B4B-XH-A_1x04_P2.50mm_Vertical
J3: D1 FFC; JST_XH_B4B-XH-A_1x04_P2.50mm_Vertical
J4: S Pins A; PinHeader_1x06_P2.54mm_Vertical
J5: S Pins B; PinHeader_1x06_P2.54mm_Vertical

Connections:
+5V: J1.2, J2.2, J2.3, J3.2, J3.3, J4.3, J4.4, J5.3, J5.4
GND: J1.1, J2.1, J2.4, J3.1, J3.4, J4.1, J4.6, J5.1, J5.6

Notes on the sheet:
To Do List - Power Indicator LEDS - Input Supply (On if power is inputted) - Output (On if output is active) - [SCP] Fuse (On if fuse is alive) - [OVP] Input Over Volt (On if input is reaching its max voltage) - [RVP] Input Reverse Volt (On if input voltage is reversed) - [UVP] Input Under Volt (On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

Board: 2 copper layers, 5 parts (2 on the bottom side), 2 nets, no tracks yet.

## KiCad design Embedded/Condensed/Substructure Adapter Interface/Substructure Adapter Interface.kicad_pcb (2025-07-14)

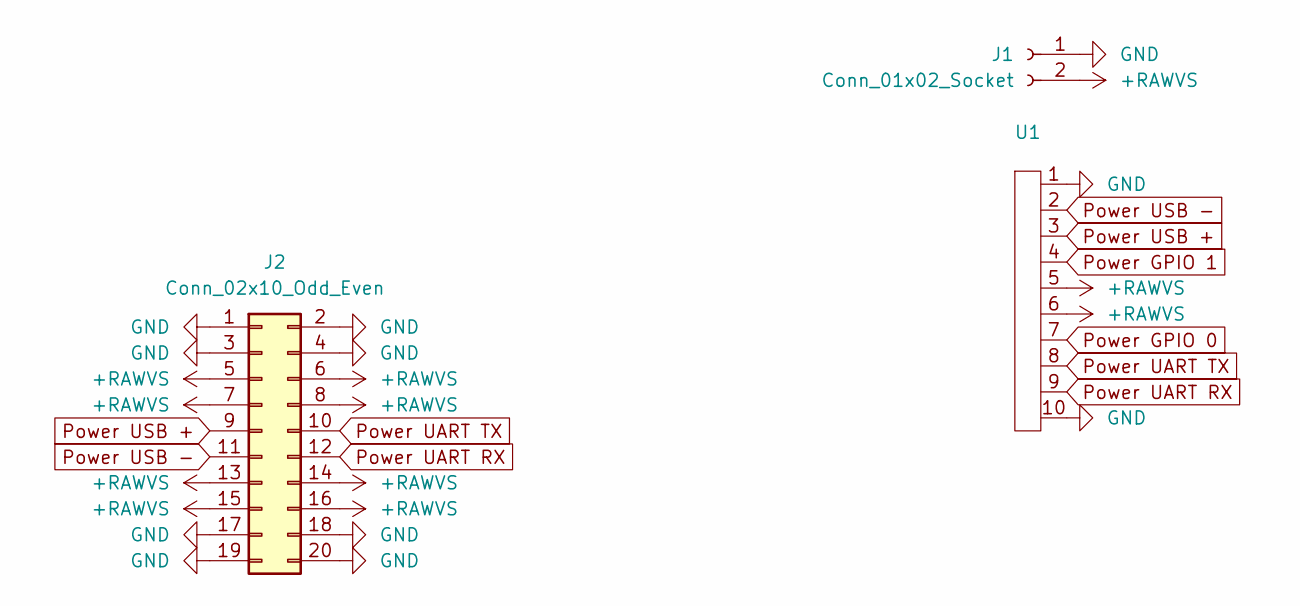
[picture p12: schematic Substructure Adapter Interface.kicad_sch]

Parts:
J1: Conn_01x02_Socket; AMASS_XT30PW-M_1x02_P2.50mm_Horizontal
J2: Conn_02x10_Odd_Even; PinHeader_2x10_P1.00mm_Vertical
U1: FFC 0.8mm 10P

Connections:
+RAWVS: J1.2, J2.5, J2.6, J2.7, J2.8, J2.13, J2.14, J2.15, J2.16, U1.5, U1.6
GND: J1.1, J2.1, J2.2, J2.3, J2.4, J2.17, J2.18, J2.19, J2.20, U1.1, U1.10
Power GPIO 0: U1.7
Power GPIO 1: U1.4
Power UART RX: J2.12, U1.9
Power UART TX: J2.10, U1.8
Power USB +: J2.9, U1.3
Power USB -: J2.11, U1.2

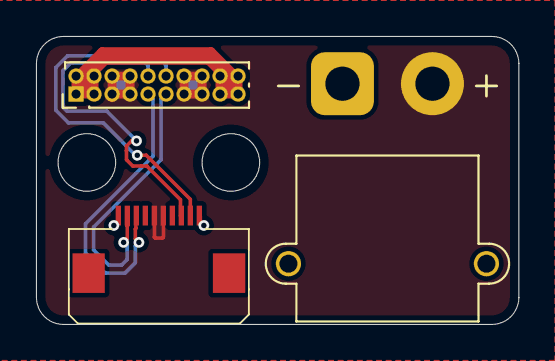
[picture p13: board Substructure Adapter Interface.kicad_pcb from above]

Board: 2 copper layers, 26.8 x 16.0 mm, 3 parts (0 on the bottom side), 6 nets.

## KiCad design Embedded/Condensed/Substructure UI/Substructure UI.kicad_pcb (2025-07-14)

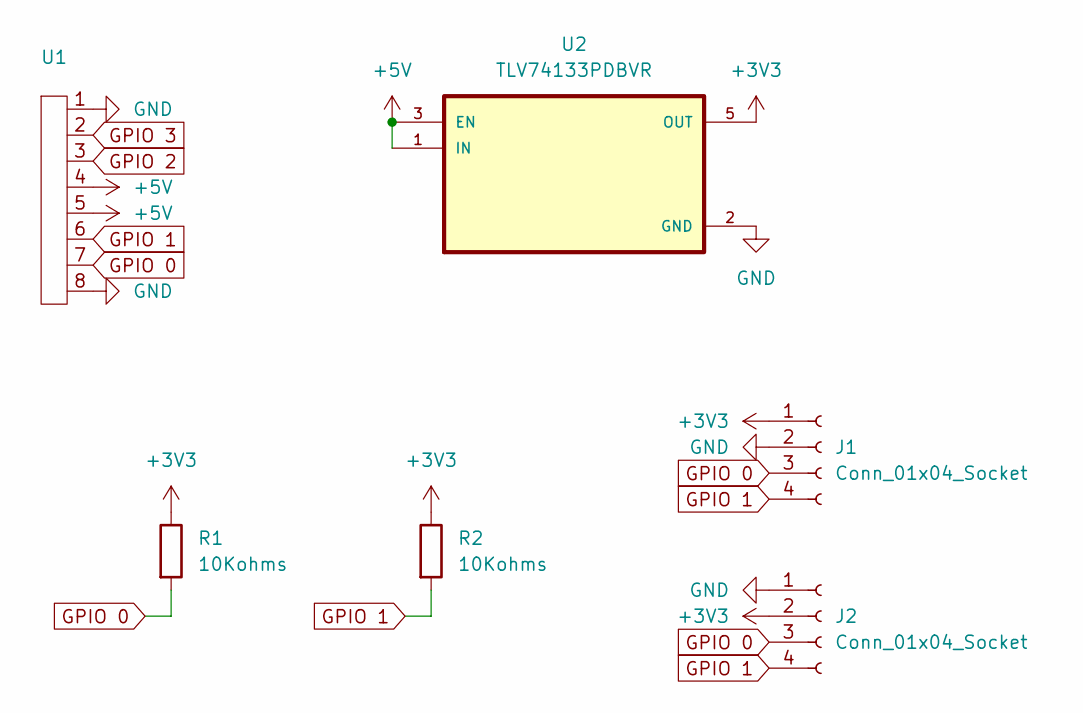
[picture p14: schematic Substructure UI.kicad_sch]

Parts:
J1, J2: Conn_01x04_Socket; PinHeader_1x04_P2.54mm_Vertical
R1, R2: 10Kohms; R_0603_1608Metric_Pad0.98x0.95mm_HandSolder
U1: FFC 0.8mm 8P
U2: TLV74133PDBVR; SOT95P280X145-5N

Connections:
+3V3: J1.1, J2.2, R1.1, R2.1, U2.5 (OUT)
+5V: U1.4, U1.5, U2.1 (IN), U2.3 (EN)
GND: J1.2, J2.1, U1.1, U1.8, U2.2 (GND)
GPIO 0: J1.3, J2.3, R1.2, U1.7
GPIO 1: J1.4, J2.4, R2.2, U1.6
GPIO 2: U1.3
GPIO 3: U1.2

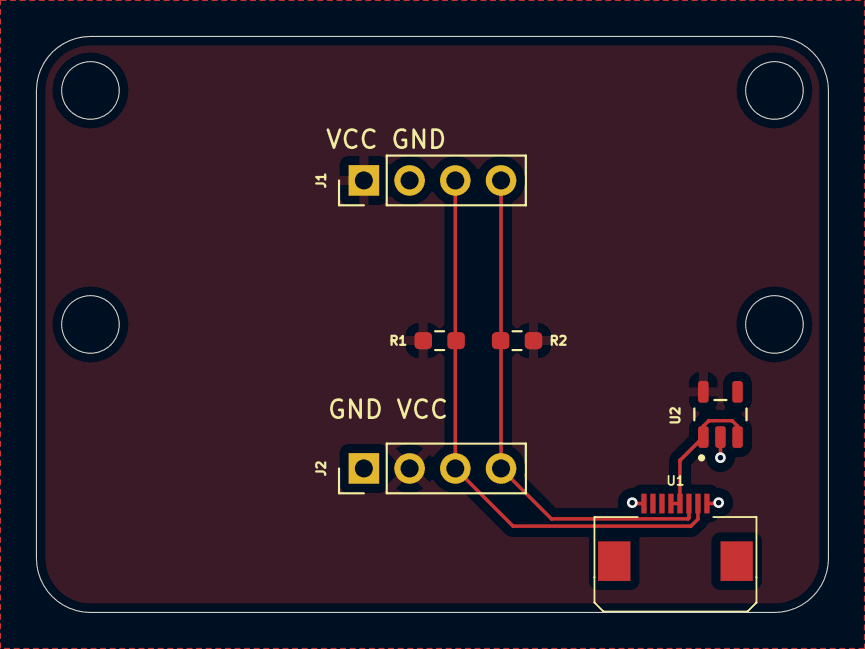
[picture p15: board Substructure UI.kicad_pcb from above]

Board: 2 copper layers, 44.0 x 32.0 mm, 6 parts (0 on the bottom side), 5 nets.

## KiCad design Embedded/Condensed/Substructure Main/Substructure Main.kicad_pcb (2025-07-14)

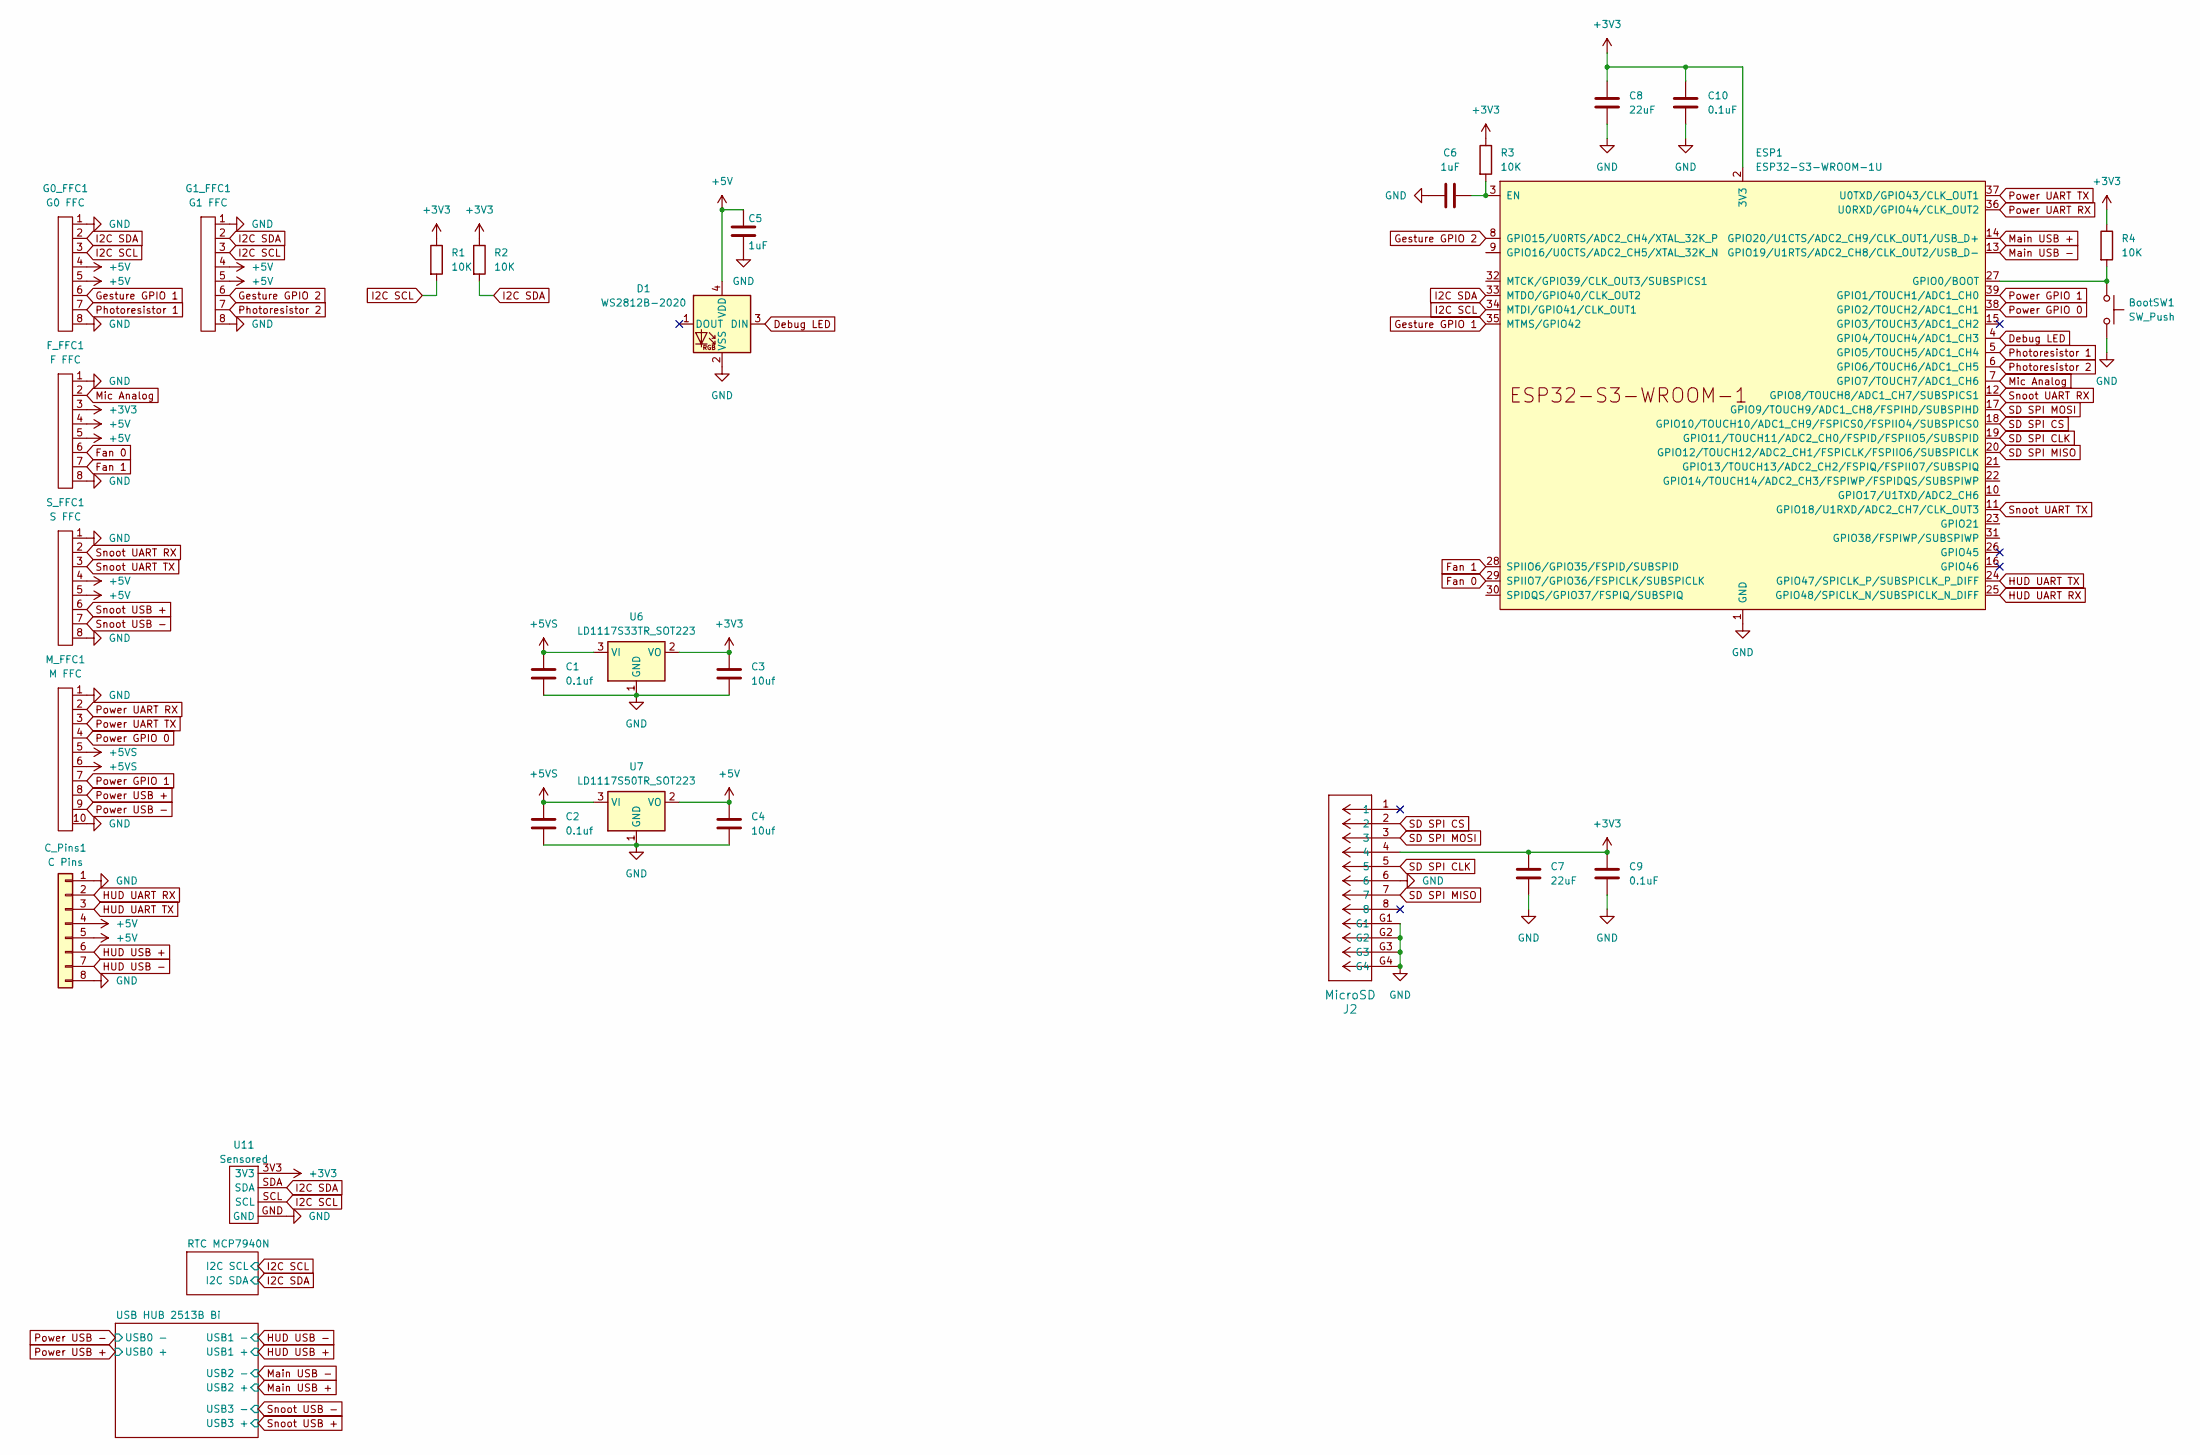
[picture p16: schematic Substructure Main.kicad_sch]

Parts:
BootSW1: SW_Push; R-667843
C1, C2: 0.1uf; C_0603_1608Metric_Pad1.08x0.95mm_HandSolder
C3, C4: 10uf; C_0603_1608Metric_Pad1.08x0.95mm_HandSolder
C5, C6: 1uF; C_0603_1608Metric_Pad1.08x0.95mm_HandSolder
C7, C8: 22uF; C_0603_1608Metric_Pad1.08x0.95mm_HandSolder
C9, C10: 0.1uF; C_0603_1608Metric_Pad1.08x0.95mm_HandSolder
C_Pins1: C Pins; PinHeader_1x08_P1.27mm_Vertical
D1: WS2812B-2020; LED_WS2812B-2020_PLCC4_2.0x2.0mm
ESP1: ESP32-S3-WROOM-1U
F_FFC1: F FFC; FFC-8-0.5
G0_FFC1: G0 FFC; FFC-8-0.5
G1_FFC1: G1 FFC; FFC-8-0.5
J2: MicroSD; MicroSD_473092651
M_FFC1: M FFC; FFC-10-0.5
R1, R2: 10K; R_0603_1608Metric_Pad0.98x0.95mm_HandSolder
R3, R4: 10K; R_0603_1608Metric
S_FFC1: S FFC; FFC-8-0.5
U6: LD1117S33TR_SOT223; SOT-223-3_TabPin2
U7: LD1117S50TR_SOT223; SOT-223-3_TabPin2
U11: Sensored

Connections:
+3V3: C3.1, C7.1, C8.1, C9.1, C10.1, ESP1.2 (3V3), F_FFC1.3, J2.4, R1.1, R2.1, R3.1, R4.1, U6.2 (VO), U11.3V3; also elsewhere on the board
+5V: C4.1, C5.1, C_Pins1.4, C_Pins1.5, D1.4 (VDD), F_FFC1.4, F_FFC1.5, G0_FFC1.4, G0_FFC1.5, G1_FFC1.4, G1_FFC1.5, S_FFC1.4, S_FFC1.5, U7.2 (VO)
+5VS: C1.1, C2.1, M_FFC1.5, M_FFC1.6, U6.3 (VI), U7.3 (VI)
Debug LED: D1.3 (DIN), ESP1.4 (GPIO4/TOUCH4/ADC1_CH3)
Fan 0: ESP1.29 (SPIIO7/GPIO36/FSPICLK/SUBSPICLK), F_FFC1.6
Fan 1: ESP1.28 (SPIIO6/GPIO35/FSPID/SUBSPID), F_FFC1.7
GND: BootSW1.2, C1.2, C2.2, C3.2, C4.2, C5.2, C6.1, C7.2, C8.2, C9.2, C10.2, C_Pins1.1, C_Pins1.8, D1.2 (VSS), ESP1.1 (GND), ESP1.40 (GND), ESP1.41 (GND), F_FFC1.1, F_FFC1.8, G0_FFC1.1, G0_FFC1.8, G1_FFC1.1, G1_FFC1.8, J2.6, J2.G1, J2.G2, J2.G3, J2.G4, M_FFC1.1, M_FFC1.10, S_FFC1.1, S_FFC1.8, U6.1 (GND), U7.1 (GND), U11.GND; also elsewhere on the board
Gesture GPIO 1: ESP1.35 (MTMS/GPIO42), G0_FFC1.6
Gesture GPIO 2: ESP1.8 (GPIO15/U0RTS/ADC2_CH4/XTAL_32K_P), G1_FFC1.6
HUD UART RX: C_Pins1.2, ESP1.25 (GPIO48/SPICLK_N/SUBSPICLK_N_DIFF)
HUD UART TX: C_Pins1.3, ESP1.24 (GPIO47/SPICLK_P/SUBSPICLK_P_DIFF)
HUD USB +: C_Pins1.6; also elsewhere on the board
HUD USB -: C_Pins1.7; also elsewhere on the board
I2C SCL: ESP1.34 (MTDI/GPIO41/CLK_OUT1), G0_FFC1.3, G1_FFC1.3, R1.2, U11.SCL; also elsewhere on the board
I2C SDA: ESP1.33 (MTDO/GPIO40/CLK_OUT2), G0_FFC1.2, G1_FFC1.2, R2.2, U11.SDA; also elsewhere on the board
Main USB +: ESP1.14 (GPIO20/U1CTS/ADC2_CH9/CLK_OUT1/USB_D+); also elsewhere on the board
Main USB -: ESP1.13 (GPIO19/U1RTS/ADC2_CH8/CLK_OUT2/USB_D-); also elsewhere on the board
Mic Analog: ESP1.7 (GPIO7/TOUCH7/ADC1_CH6), F_FFC1.2
unnamed: C6.2, ESP1.3 (EN), R3.2
unnamed: BootSW1.1, ESP1.27 (GPIO0/BOOT), R4.2
Photoresistor 1: ESP1.5 (GPIO5/TOUCH5/ADC1_CH4), G0_FFC1.7
Photoresistor 2: ESP1.6 (GPIO6/TOUCH6/ADC1_CH5), G1_FFC1.7
Power GPIO 0: ESP1.38 (GPIO2/TOUCH2/ADC1_CH1), M_FFC1.4
Power GPIO 1: ESP1.39 (GPIO1/TOUCH1/ADC1_CH0), M_FFC1.7
Power UART RX: ESP1.36 (U0RXD/GPIO44/CLK_OUT2), M_FFC1.2
Power UART TX: ESP1.37 (U0TXD/GPIO43/CLK_OUT1), M_FFC1.3
Power USB +: M_FFC1.8; also elsewhere on the board
Power USB -: M_FFC1.9; also elsewhere on the board
SD SPI CLK: ESP1.19 (GPIO11/TOUCH11/ADC2_CH0/FSPID/FSPIIO5/S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), J2.5
SD SPI CS: ESP1.18 (GPIO10/TOUCH10/ADC1_CH9/FSPICS0/FSPIIO4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), J2.2
SD SPI MISO: ESP1.20 (GPIO12/TOUCH12/ADC2_CH1/FSPICLK/FSPIIO6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), J2.7
SD SPI MOSI: ESP1.17 (GPIO9/TOUCH9/ADC1_CH8/FSPIHD/SUBSPIHD), J2.3
Snoot UART RX: ESP1.12 (GPIO8/TOUCH8/ADC1_CH7/SUBSPICS1), S_FFC1.2
Snoot UART TX: ESP1.11 (GPIO18/U1RXD/ADC2_CH7/CLK_OUT3), S_FFC1.3
Snoot USB +: S_FFC1.6; also elsewhere on the board
Snoot USB -: S_FFC1.7; also elsewhere on the board


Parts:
C11, C12: 18pf; C_0402_1005Metric_Pad0.74x0.62mm_HandSolder
C13, C17: 1uF; C_0402_1005Metric_Pad0.74x0.62mm_HandSolder
C14, C15, C16, C18, C19, C20, C21, C22, C23, C24: 0.1uF; C_0402_1005Metric_Pad0.74x0.62mm_HandSolder
R5: 1M; R_0402_1005Metric_Pad0.72x0.64mm_HandSolder
R6: 100K; R_0402_1005Metric_Pad0.72x0.64mm_HandSolder
R7: 12K; R_0402_1005Metric_Pad0.72x0.64mm_HandSolder
U8: USB2513B_Bi; QFN-36-1EP_6x6mm_P0.5mm_EP3.7x3.7mm
Y1: TSX-3225 24MF18X-C0; Crystal_SMD_SeikoEpson_TSX3225-4Pin_3.2x2.5mm_HandSoldering

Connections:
+3V3: C19.1, C20.1, C21.1, C22.1, C23.1, C24.1, R6.2, U8.5 (VDDA33), U8.10 (VDDA33), U8.15 (VDD33), U8.23 (VDD33), U8.29 (VDDA33), U8.36 (VDDA33); also elsewhere on the board
+5VP: C16.1, U8.27 (VBUS_DET)
GND: C11.1, C12.1, C13.2, C14.2, C15.2, C16.2, C17.2, C18.2, C19.2, C20.2, C21.2, C22.2, C23.2, C24.2, R7.1, U8.11 (TEST), U8.37 (VSS), Y1.2, Y1.4; also elsewhere on the board
HUD USB +: U8.2 (USBDP_DN1/PRT_DIS_P1); also elsewhere on the board
HUD USB -: U8.1 (USBDM_DN1/PRT_DIS_M1); also elsewhere on the board
Main USB +: U8.4 (USBDP_DN2/PRT_DIS_P2); also elsewhere on the board
Main USB -: U8.3 (USBDM_DN2/PRT_DIS_M2); also elsewhere on the board
unnamed: C17.1, C18.1, U8.14 (CRFILT)
unnamed: C13.1, C15.1, U8.34 (PLLFILT)
unnamed: R7.2, U8.35 (RBIAS)
unnamed: C14.1, R6.1, U8.26 (RESET_N)
unnamed: C11.2, R5.2, U8.33 (XTALIN/CLKIN), Y1.3
unnamed: C12.2, R5.1, U8.32 (XTALOUT), Y1.1
Power USB +: U8.31 (USBDP_UP); also elsewhere on the board
Power USB -: U8.30 (USBDM_UP); also elsewhere on the board
Snoot USB +: U8.7 (USBDP_DN3/PRT_DIS_P3); also elsewhere on the board
Snoot USB -: U8.6 (USBDM_DN3/PRT_DIS_M3); also elsewhere on the board


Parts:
C25: 0.1uF; C_0402_1005Metric_Pad0.74x0.62mm_HandSolder
C26: 10pf; C_0402_1005Metric_Pad0.74x0.62mm_HandSolder
C27: 12pf; C_0402_1005Metric_Pad0.74x0.62mm_HandSolder
Coin_Cell1: Coin Cell; JST_GH_SM02B-GHS-TB_1x02-1MP_P1.25mm_Horizontal
U9: MCP7940N-xMNY; DFN-8-1EP_3x2mm_P0.5mm_EP1.36x1.46mm
Y2: CM7V-T1A; Crystal_SMD_MicroCrystal_CC7V-T1A-2Pin_3.2x1.5mm_HandSolder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

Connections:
+3V3: C25.1, U9.8 (VCC); also elsewhere on the board
GND: C25.2, C26.2, C27.2, Coin_Cell1.1, U9.4 (VSS), U9.9 (EP); also elsewhere on the board
I2C SCL: U9.6 (SCL); also elsewhere on the board
I2C SDA: U9.5 (SDA); also elsewhere on the board
unnamed: Coin_Cell1.2, U9.3 (VBAT)
unnamed: C26.1, U9.1 (X1), Y2.1
unnamed: C27.1, U9.2 (X2), Y2.2



Board: 4 copper layers, 40.0 x 35.5 mm, 52 parts (17 on the bottom side), 46 nets.

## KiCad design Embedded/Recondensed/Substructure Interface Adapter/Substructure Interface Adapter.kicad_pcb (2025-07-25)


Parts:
J1: Substructure Power; AMASS_XT30PW-M_1x02_P2.50mm_Horizontal
J2: Pogo Pins; PinHeader_2x10_P2.00mm_Vertical
U1: Substructure; FFC-4-0.5

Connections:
+RAWVS: J1.2, J2.5, J2.6, J2.7, J2.8, J2.13, J2.14, J2.15, J2.16
GND: J1.1, J2.1, J2.2, J2.3, J2.4, J2.17, J2.18, J2.19, J2.20, U1.1, U1.4
Power UART RX: J2.9, J2.12, U1.2
Power UART TX: J2.10, J2.11, U1.3


Board: 2 copper layers, 15.5 x 20.0 mm, 3 parts (1 on the bottom side), 4 nets.

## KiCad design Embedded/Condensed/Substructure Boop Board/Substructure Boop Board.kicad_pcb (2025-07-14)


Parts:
C1: 10nF; C_0402_1005Metric_Pad0.74x0.62mm_HandSolder; LCSC C327025
C2, C7, C8, C9: 10uF; C_0402_1005Metric_Pad0.74x0.62mm_HandSolder; LCSC C15525
C3, C4, C5, C6, C10, C11, C16: 0.1uF; C_0402_1005Metric_Pad0.74x0.62mm_HandSolder; LCSC C1525
C12, C13: 33pF; C_0402_1005Metric_Pad0.74x0.62mm_HandSolder; LCSC C70465
C14: 0.1uF; C_0603_1608Metric_Pad1.08x0.95mm_HandSolder; LCSC C1591
C15: 10uF; C_0603_1608Metric_Pad1.08x0.95mm_HandSolder; LCSC C3039698
C17: 1nF; C_0402_1005Metric_Pad0.74x0.62mm_HandSolder; LCSC C14442
C18, C23: 150pF; C_0402_1005Metric_Pad0.74x0.62mm_HandSolder; LCSC C86286
C19, C21, C24, C27: NC; C_0402_1005Metric_Pad0.74x0.62mm_HandSolder
C20, C25: 22pF; C_0402_1005Metric_Pad0.74x0.62mm_HandSolder; LCSC C307342
C22, C26: 220pF; C_0402_1005Metric_Pad0.74x0.62mm_HandSolder; LCSC C307445
L1, L2: 560nH; L_0603_1608Metric_Pad1.05x0.95mm_HandSolder; LCSC C502009
R1, R2: 2.2K; C_0402_1005Metric_Pad0.74x0.62mm_HandSolder; LCSC C163447
R3: 1K; C_0402_1005Metric_Pad0.74x0.62mm_HandSolder; LCSC C844716
R4: 1.7K; C_0402_1005Metric_Pad0.74x0.62mm_HandSolder; LCSC C482079
R5, R6: 1.5; C_0402_1005Metric_Pad0.74x0.62mm_HandSolder; LCSC C482091
U1: PN5321A3HN_C1xx; HVQFN-40-1EP_6x6mm_P0.5mm_EP4.1x4.1mm; LCSC C28925
U2: AD7142ACPZ-500RL7; LFCSP-32-1EP_5x5mm_P0.5mm_EP3.1x3.1mm_ThermalVias; LCSC C208139
U3: LD1117S33TR_SOT223; SOT-223-3_TabPin2; LCSC C86781
U4: 0.35uH (Per Coil); 30 x 40 - 2 Pair 2 Layer 2 Turn Loop Antenna
U5: R FFC; FFC 0.8mm 8P
Y1: 7M-27.120MAAJ-T; XTAL_7M-27.120MAAJ-T; PARTREV N/A; DIGIKEY 887-1424-1-ND

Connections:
+3V3: C2.1, C3.1, C10.1, C11.1, C15.1, R1.1, R2.2, U1.16 (I0), U1.23 (PVDD), U1.38 (~RSTPD), U1.40 (VBAT), U2.13 (AVCC), U2.17 (DVCC), U2.20 (VDrive), U2.28 (VREF+), U3.2 (VO)
+5V: C14.1, U3.3 (VI), U5.4, U5.5
GND: C1.1, C2.2, C3.2, C4.2, C5.2, C6.2, C7.2, C8.2, C9.2, C10.2, C11.2, C12.2, C13.2, C14.2, C15.2, C16.2, C18.2, C19.2, C22.2, C23.2, C24.2, C26.1, U1.1 (DVSS), U1.3 (TVSS1), U1.7 (TVSS2), U1.11 (AVSS), U1.17 (I1), U1.18 (TESTEN), U1.41 (AVSS), U2.14 (AGND), U2.18 (DGND1), U2.19 (DGND2), U2.22 (SDI/ADD0), U2.24 (_CS/ADD1), U2.27 (TEST), U2.29 (VREF-), U3.1 (GND), U4.3, U5.1, U5.8, Y1.2 (GND), Y1.4 (GND__1)
I2C SCL: R2.1, U1.27 (NSS/P50_SCL/HSU_RX), U2.23 (SCLK), U5.3, U5.7
I2C SDA: R1.2, U1.28 (MOSI/SDA/HSU_TX), U2.21 (SDO/SDA), U5.2, U5.6
unnamed: C17.2, R4.1
unnamed: C18.1, C19.1, C20.1, C21.1, R5.1
unnamed: C20.2, C21.2, C22.1, L1.2
unnamed: C23.1, C24.1, C25.1, C27.1, R6.1
unnamed: C25.2, C26.2, C27.2, L2.2, R4.2
unnamed: R5.2, U4.1
unnamed: R6.2, U4.2
unnamed: C4.1, C5.1, C6.1, C7.1, C8.1, C9.1, U1.5 (TVDD), U1.8 (AVDD), U1.39 (DVDD)
unnamed: C12.1, U1.14 (OSCIN), Y1.1
unnamed: C13.1, U1.15 (OSCOUT), Y1.3
unnamed: C17.1, R3.1, U1.10 (RX)
unnamed: L1.1, U1.4 (TX1)
unnamed: L2.1, U1.6 (TX2)
unnamed: C16.1, R3.2, U1.9 (VMID)
unnamed: C1.2, U2.12 (CShield)

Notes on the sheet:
LC Tank (Tuned to 13.62MHz 1% Error from 13.56MHZ)
Note: The capacitive charge differential is between CINx and SRC


Board: 2 copper layers, 30.0 x 40.0 mm, 41 parts (1 on the bottom side), 20 nets.

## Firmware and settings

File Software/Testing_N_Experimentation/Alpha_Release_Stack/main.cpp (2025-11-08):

/*****************************************************************
 * File:      main.cpp
 * Category:  application
 * Author:    XCR1793 (Feather Forge)
 * 
 * Purpose:
 *    Main application for SD card image converter. Lists all
 *    images with metadata, converts them to BMP format with
 *    progress tracking, then lists the converted bitmaps.
 *****************************************************************/

#include <stdio.h>
#include <string.h>
#include <sys/unistd.h>
#include <sys/stat.h>
#include "freertos/FreeRTOS.h"
#include "freertos/task.h"
#include "esp_log.h"
#include "esp_vfs_fat.h"
#include "driver/spi_common.h"
#include "driver/sdspi_host.h"
#include "sdmmc_cmd.h"
#include "ImageConverter.h"
#include "ImageConverter.impl.hpp"

using namespace arcos::abstraction::utilities;

static const char* MAIN_TAG = "main";

// Global image converter instance
ImageConverter image_converter;

/** List all image files on SD card with metadata
 * @param directory Directory to search
 * @param file_count Output parameter for total files found
 */
void listImageFiles(const char* directory, int& file_count);

/** List all BMP files on SD card
 * @param directory Directory to search
 */
void listBmpFiles(const char* directory);

/** Recursive helper to list images with metadata */
void listImagesRecursive(const char* dir_path, int& file_count);

/** Recursive helper to list BMP files */
void listBmpsRecursive(const char* dir_path);

/** Check if file is an image */
bool isImageFile(const char* filename);

/** Get image dimensions and bit depth from file */
bool getImageMetadata(const char* filepath, uint32_t& width, uint32_t& height, uint16_t& bit_depth);

/** Format file size as human-readable string */
void formatFileSize(size_t size, char* buffer, size_t buffer_size);

/** Convert all images with progress tracking */
int convertAllImagesWithProgress(const char* directory);

/** Recursive conversion with progress */
void convertRecursiveWithProgress(const char* dir_path, int& converted_count, int& total_count, int total_images);

extern "C" void app_main(void){
  // Wait 3 seconds at startup
  vTaskDelay(pdMS_TO_TICKS(3000));
  
  ESP_LOGI(MAIN_TAG, "\n========================================");
  ESP_LOGI(MAIN_TAG, "    SD Card Image Converter v1.0");
  ESP_LOGI(MAIN_TAG, "========================================\n");
  
  // Configure SD card and image converter
  ImageConverterConfig config;
  config.cs_pin = 14;
  config.mosi_pin = 21;
  config.miso_pin = 48;
  config.clk_pin = 47;
  config.spi_frequency = 40000000; // 40 MHz
  config.chunk_size = 2048; // Process 2KB at a time for better performance
  
  // Initialize the converter
  ESP_LOGI(MAIN_TAG, "Initializing SD card...");
  if(!image_converter.init(config)){
    ESP_LOGE(MAIN_TAG, "\n[ERROR] Failed to initialize image converter!");
    ESP_LOGE(MAIN_TAG, "Please check SD card connection and try again.");
    return;
  }
  
  ESP_LOGI(MAIN_TAG, "SD card initialized successfully!\n");
  
  // Step 1: List all image files with metadata
  ESP_LOGI(MAIN_TAG, "========================================");
  ESP_LOGI(MAIN_TAG, "  STEP 1: Scanning for Image Files");
  ESP_LOGI(MAIN_TAG, "========================================\n");
  
  int file_count = 0;
  listImageFiles("/sdcard", file_count);
  
  if(file_count == 0){
    ESP_LOGI(MAIN_TAG, "\nNo image files found on SD card.");
    return;
  }
  
  ESP_LOGI(MAIN_TAG, "\nTotal images found: %d\n", file_count);
  
  // Step 2: Convert all images with progress tracking
  ESP_LOGI(MAIN_TAG, "========================================");
  ESP_LOGI(MAIN_TAG, "  STEP 2: Converting Images to BMP");
  ESP_LOGI(MAIN_TAG, "========================================\n");
  
  int converted = convertAllImagesWithProgress("/sdcard");
  
  ESP_LOGI(MAIN_TAG, "\n========================================");
  ESP_LOGI(MAIN_TAG, "  Conversion Complete: %d/%d images", converted, file_count);
  ESP_LOGI(MAIN_TAG, "========================================\n");
  
  // Step 3: List all BMP files
  ESP_LOGI(MAIN_TAG, "========================================");
  ESP_LOGI(MAIN_TAG, "  STEP 3: Listing BMP Files");
  ESP_LOGI(MAIN_TAG, "========================================\n");
  
  listBmpFiles("/sdcard");
  
  ESP_LOGI(MAIN_TAG, "\n========================================");
  ESP_LOGI(MAIN_TAG, "  All operations completed!");
  ESP_LOGI(MAIN_TAG, "========================================\n");
  
  // Keep task alive
  while(1){
    vTaskDelay(pdMS_TO_TICKS(1000));
  }
}

void listImageFiles(const char* directory, int& file_count){
  DIR* dir = opendir(directory);
  if(!dir){
    ESP_LOGE(MAIN_TAG, "[ERROR] Failed to open directory: %s", directory);
    return;
  }
  
  file_count = 0;
  printf("Filename                        | Size      | Dimensions  | Bit Depth\n");
  printf("----------------------------------------------------------------\n");
  
  listImagesRecursive(directory, file_count);
  closedir(dir);
}

void listImagesRecursive(const char* dir_path, int& file_count){
  DIR* dir = opendir(dir_path);
  if(!dir){
    return;
  }
  
  struct dirent* entry;
  while((entry = readdir(dir)) != NULL){
    // Skip . and ..
    if(strcmp(entry->d_name, ".") == 0 || strcmp(entry->d_name, "..") == 0){
      continue;
    }
    
    // Build full path
    char full_path[256];
    snprintf(full_path, sizeof(full_path), "%s/%s", dir_path, entry->d_name);
    
    // Check if directory or file
    struct stat st;
    if(stat(full_path, &st) == 0){
      if(S_ISDIR(st.st_mode)){
        // Recursively list subdirectories
        listImagesRecursive(full_path, file_count);
      }else{
        if(isImageFile(entry->d_name)){
          file_count++;
          
          // Get file size
          size_t file_size = st.st_size;
          char size_str[16];
          formatFileSize(file_size, size_str, sizeof(size_str));
          
          // Get image metadata
          uint32_t width = 0;
          uint32_t height = 0;
          uint16_t bit_depth = 0;
          bool has_metadata = getImageMetadata(full_path, width, height, bit_depth);
          
          // Print file information
          printf("%-30s | %-9s | ", full_path, size_str);
          
          if(has_metadata && width > 0 && height > 0){
            printf("%4lu x %-4lu | %u-bit\n", (unsigned long)width, (unsigned long)height, (unsigned int)bit_depth);
          }else{
            printf("Unknown     | Unknown\n");
          }
        }
      }
    }
  }
  
  closedir(dir);
}

void listBmpFiles(const char* directory){
  DIR* dir = opendir(directory);
  if(!dir){
    ESP_LOGE(MAIN_TAG, "[ERROR] Failed to open directory: %s", directory);
    return;
  }
  
  printf("BMP Filename                    | Size      | Dimensions  | Bit Depth\n");
  printf("----------------------------------------------------------------\n");
  
  listBmpsRecursive(directory);
  closedir(dir);
}

void listBmpsRecursive(const char* dir_path){
  DIR* dir = opendir(dir_path);
  if(!dir){
    return;
  }
  
  struct dirent* entry;
  while((entry = readdir(dir)) != NULL){
    // Skip . and ..
    if(strcmp(entry->d_name, ".") == 0 || strcmp(entry->d_name, "..") == 0){
      continue;
    }
    
    // Build full path
    char full_path[256];
    snprintf(full_path, sizeof(full_path), "%s/%s", dir_path, entry->d_name);
    
    // Check if directory or file
    struct stat st;
    if(stat(full_path, &st) == 0){
      if(S_ISDIR(st.st_mode)){
        // Recursively list subdirectories
        listBmpsRecursive(full_path);
      }else{
        size_t len = strlen(entry->d_name);
        
        // Check if file is .bmp
        if(len > 4 && strcasecmp(entry->d_name + len - 4, ".bmp") == 0){
          // Get file size
          size_t file_size = st.st_size;
          char size_str[16];
          formatFileSize(file_size, size_str, sizeof(size_str));
          
          // Get BMP metadata
          uint32_t width = 0;
          uint32_t height = 0;
          uint16_t bit_depth = 0;
          bool has_metadata = getImageMetadata(full_path, width, height, bit_depth);
          
          // Print BMP information
          printf("%-30s | %-9s | ", full_path, size_str);
          
          if(has_metadata && width > 0 && height > 0){
            printf("%4lu x %-4lu | %u-bit\n", (unsigned long)width, (unsigned long)height, (unsigned int)bit_depth);
          }else{
            printf("Unknown     | Unknown\n");
          }
        }
      }
    }
  }
  
  closedir(dir);
}

bool isImageFile(const char* filename){
  if(!filename){
    return false;
  }
  
  size_t len = strlen(filename);
  if(len < 4){
    return false;
  }
  
  // Check file extension (case-insensitive)
  const char* ext = filename + len - 4;
  return (strcasecmp(ext, ".jpg") == 0 ||
          strcasecmp(ext, ".png") == 0 ||
          strcasecmp(ext, ".gif") == 0 ||
          strcasecmp(ext, ".tga") == 0 ||
          (len > 5 && strcasecmp(filename + len - 5, ".jpeg") == 0));
}

bool getImageMetadata(const char* filepath, uint32_t& width, uint32_t& height, uint16_t& bit_depth){
  FILE* file = fopen(filepath, "rb");
  if(!file){
    return false;
  }
  
  uint8_t header[32];
  size_t bytes_read = fread(header, 1, sizeof(header), file);
  
  if(bytes_read < 4){
    fclose(file);
    return false;
  }
  
  // Check for BMP format
  if(header[0] == 'B' && header[1] == 'M'){
    if(bytes_read < 30){
      fclose(file);
      return false;
    }
    
    // BMP dimensions are at offset 18
    width = *((uint32_t*)(header + 18));
    height = *((uint32_t*)(header + 22));
    bit_depth = *((uint16_t*)(header + 28));
    
    fclose(file);
    return true;
  }
  
  // Check for GIF format
  if(header[0] == 'G' && header[1] == 'I' && header[2] == 'F'){
    if(bytes_read < 10){
      fclose(file);
      return false;
    }
    
    // GIF width and height are at bytes 6-7 and 8-9 (little-endian)
    width = header[6] | (header[7] << 8);
    height = header[8] | (header[9] << 8);
    bit_depth = ((header[10] & 0x07) + 1); // Color depth from packed field
    
    fclose(file);
    return true;
  }
  
  // Check for JPEG format
  if(header[0] == 0xFF && header[1] == 0xD8){
    // JPEG parsing requires scanning for SOF marker
    bit_depth = 24; // Typically 24-bit
    fclose(file);
    return false; // Dimension parsing not implemented
  }
  
  // Check for PNG format
  if(header[0] == 0x89 && header[1] == 'P' && header[2] == 'N' && header[3] == 'G'){
    if(bytes_read < 24){
      fclose(file);
      return false;
    }
    
    // PNG IHDR chunk at offset 16 (width and height are big-endian)
    width = (header[16] << 24) | (header[17] << 16) | (header[18] << 8) | header[19];
    height = (header[20] << 24) | (header[21] << 16) | (header[22] << 8) | header[23];
    bit_depth = header[24]; // Bit depth
    
    fclose(file);
    return true;
  }
  
  fclose(file);
  return false;
}

void formatFileSize(size_t size, char* buffer, size_t buffer_size){
  if(size < 1024){
    snprintf(buffer, buffer_size, "%zu B", size);
  }else if(size < 1024 * 1024){
    snprintf(buffer, buffer_size, "%.1f KB", size / 1024.0);
  }else{
    snprintf(buffer, buffer_size, "%.1f MB", size / (1024.0 * 1024.0));
  }
}

int convertAllImagesWithProgress(const char* directory){
  DIR* dir = opendir(directory);
  if(!dir){
    ESP_LOGE(MAIN_TAG, "[ERROR] Failed to open directory: %s", directory);
    return 0;
  }
  closedir(dir);
  
  // First pass: count total images
  int total_images = 0;
  listImagesRecursive(directory, total_images);
  
  // Second pass: convert with progress
  int converted_count = 0;
  int processed_count = 0;
  convertRecursiveWithProgress(directory, converted_count, processed_count, total_images);
  
  return converted_count;
}

void convertRecursiveWithProgress(const char* dir_path, int& converted_count, int& total_count, int total_images){
  DIR* dir = opendir(dir_path);
  if(!dir){
    return;
  }
  
  struct dirent* entry;
  while((entry = readdir(dir)) != NULL){
    // Skip . and ..
    if(strcmp(entry->d_name, ".") == 0 || strcmp(entry->d_name, "..") == 0){
      continue;
    }
    
    // Build full path
    char full_path[256];
    snprintf(full_path, sizeof(full_path), "%s/%s", dir_path, entry->d_name);
    
    // Check if directory or file
    struct stat st;
    if(stat(full_path, &st) == 0){
      if(S_ISDIR(st.st_mode)){
        // Recursively convert subdirectories
        convertRecursiveWithProgress(full_path, converted_count, total_count, total_images);
      }else{
        if(isImageFile(entry->d_name)){
          total_count++;
          
          // Calculate progress
          int progress = (total_count * 100) / total_images;
          
          printf("[%3d%%] Converting: %s\n", progress, full_path);
          
          // Generate output path
          char output_path[256];
          strncpy(output_path, full_path, sizeof(output_path) - 1);
          output_path[sizeof(output_path) - 1] = '\0';
          
          char* last_dot = strrchr(output_path, '.');
          if(last_dot){
            strncpy(last_dot, ".bmp", sizeof(output_path) - (last_dot - output_path));
          }else{
            strncat(output_path, ".bmp", sizeof(output_path) - strlen(output_path) - 1);
          }
          
          // Check if output already exists and is same as input (skip .bmp files)
          if(strcmp(full_path, output_path) == 0){
            printf("       -> Skipped (already BMP format)\n");
            continue;
          }
          
          // Convert the image
          if(image_converter.convertImage(full_path, output_path)){
            converted_count++;
            printf("       -> Success: %s\n", output_path);
          }else{
            printf("       -> Failed\n");
          }
        }
      }
    }
  }
  
  closedir(dir);
}

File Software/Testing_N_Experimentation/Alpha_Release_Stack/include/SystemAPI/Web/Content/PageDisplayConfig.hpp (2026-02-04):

/*****************************************************************
 * @file PageDisplayConfig.hpp
 * @brief Display Configuration Page using YAML-driven UI
 * 
 * This page auto-generates a settings UI based on the active
 * scene's YAML configuration. All controls are defined by the
 * schema metadata in the YAML file itself.
 * 
 * @author ARCOS
 * @version 1.0
 *****************************************************************/

#pragma once

namespace SystemAPI {
namespace Web {
namespace Content {

/**
 * @brief Display Configuration Page HTML
 * 
 * The page loads the current scene YAML and renders UI controls
 * based on the schema definitions. All updates are sent to
 * /api/scene/update and saved back to the YAML file.
 */
inline const char PAGE_DISPLAY_CONFIG[] = R"rawliteral(
<!DOCTYPE html>
<html lang="en">
<head>
  <meta charset="UTF-8">
  <meta name="viewport" content="width=device-width, initial-scale=1.0, maximum-scale=1.0, user-scalable=no">
  <title>Lucidius - Display Config</title>
  <link rel="stylesheet" href="/style.css">
  <style>
/* ============================================
   YAML UI Generator Styles
   ============================================ */

.yaml-form {
  display: flex;
  flex-direction: column;
  gap: 16px;
}

/* Section Cards */
.yaml-section {
  background: var(--bg-card);
  border-radius: 12px;
  border: 1px solid var(--border);
  overflow: hidden;
}

.yaml-section-header {
  display: flex;
  align-items: center;
  justify-content: space-between;
  padding: 14px 18px;
  background: var(--bg-tertiary);
  cursor: pointer;
  user-select: none;
}

.yaml-section-header:hover {
  background: var(--bg-secondary);
}

.yaml-section-title {
  display: flex;
  align-items: center;
  gap: 10px;
  font-weight: 600;
  font-size: 14px;
  color: var(--text-primary);
}

.yaml-section-icon {
  font-size: 16px;
  color: var(--accent);
  opacity: 0.9;
}

.yaml-section-chevron {
  transition: transform 0.2s ease;
  color: var(--text-muted);
}

.yaml-section.collapsed .yaml-section-chevron {
  transform: rotate(-90deg);
}

.yaml-section-body {
  padding: 18px;
  display: flex;
  flex-direction: column;
  gap: 12px;
}

.yaml-section.collapsed .yaml-section-body {
  display: none;
}

/* Field Rows */
.yaml-field-row {
  display: flex;
  align-items: center;
  justify-content: space-between;
  padding: 10px 0;
  border-bottom: 1px solid var(--border);
}

.yaml-field-row:last-child {
  border-bottom: none;
}

.yaml-field-label {
  flex: 0 0 40%;
  font-size: 13px;
  color: var(--text-secondary);
  display: flex;
  align-items: center;
  gap: 6px;
}

.yaml-field-label .help-icon {
  width: 14px;
  height: 14px;
  font-size: 10px;
  background: var(--bg-tertiary);
  border-radius: 50%;
  text-align: center;
  line-height: 14px;
  color: var(--text-muted);
  cursor: help;
}

.yaml-field-control {
  flex: 0 0 55%;
  display: flex;
  align-items: center;
  gap: 8px;
}

/* Text Input */
.yaml-input-text {
  width: 100%;
  padding: 10px 14px;
  background: var(--bg-tertiary);
  border: 1px solid var(--border);
  border-radius: 8px;
  color: var(--text-primary);
  font-size: 13px;
  transition: border-color 0.2s;
}

.yaml-input-text:focus {
  outline: none;
  border-color: var(--accent);
  box-shadow: 0 0 0 3px var(--accent-glow);
}

/* Number Input */
.yaml-input-number {
  width: 90px;
  padding: 10px 30px 10px 12px;
  background: var(--bg-tertiary);
  border: 1px solid var(--border);
  border-radius: 8px;
  color: var(--text-primary);
  font-size: 13px;
  font-family: 'SF Mono', Monaco, monospace;
  text-align: left;
  -moz-appearance: textfield;
}

.yaml-input-number::-webkit-inner-spin-button,
.yaml-input-number::-webkit-outer-spin-button {
  -webkit-appearance: none;
  margin: 0;
}

.yaml-input-number:focus {
  outline: none;
  border-color: var(--accent);
}

.yaml-input-unit {
  font-size: 12px;
  color: var(--text-muted);
  min-width: 24px;
}

/* Slider */
.yaml-slider-container {
  display: flex;
  align-items: center;
  gap: 10px;
  width: 100%;
}

.yaml-slider {
  flex: 1;
  height: 6px;
  -webkit-appearance: none;
  background: var(--bg-tertiary);
  border-radius: 3px;
  outline: none;
}

.yaml-slider::-webkit-slider-thumb {
  -webkit-appearance: none;
  width: 16px;
  height: 16px;
  background: var(--accent);
  border-radius: 50%;
  cursor: pointer;
}

.yaml-slider-value {
  min-width: 50px;
  text-align: right;
  font-size: 12px;
  font-family: 'SF Mono', Monaco, monospace;
  color: var(--text-muted);
}

/* Toggle Switch */
.yaml-toggle {
  position: relative;
  width: 44px;
  height: 24px;
  flex-shrink: 0;
}

.yaml-toggle input {
  opacity: 0;
  width: 0;
  height: 0;
}

.yaml-toggle-slider {
  position: absolute;
  cursor: pointer;
  top: 0;
  left: 0;
  right: 0;
  bottom: 0;
  background-color: var(--bg-tertiary);
  border: 1px solid var(--border);
  transition: 0.2s;
  border-radius: 24px;
}
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

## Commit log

2024-12-26 Schematic Rework
    Placed all old files in an folder for review and referencing use only as the electronic architecture will change.
    [1V8 Reg.kicad_sch, 3V3 Reg.kicad_sch, 5V Reg.kicad_sch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]
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2025-01-17 Added foam padding & starry effect features to list
    [Features.ods]
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2025-01-19 Added a couple extra features
    Batteries & Scales
    [Features.ods]
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2025-02-01 Added Bolt Holes for the Substructure Visor Retention
    [Substructure Edge Ideation.step]
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2025-02-06 Modified Tape to 3M
    From testing, the phone screen 2mm tape is way too weak.
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2025-03-17 Added Top Level Redesign, Started KiCAD Fab Files & Migrated old files to OBSOLETE
    [1V8 Reg.kicad_sch, 3V3 Reg.kicad_sch, 5V Reg.kicad_sch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]
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2025-03-20 Modified Schematic to use correct library
    [Substructure Main.kicad_sch]
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2025-03-24 Added 2 features & removed synth complexities column
    [Features.ods]
2025-03-25 Added Ports
    Main to Snoot
    Power to Main
    Main to HUD
    [Substructure Main.kicad_sch]
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2025-03-28 Added Hot Swappable Panel Mount Ideation
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2025-04-07 Added USB & Power Pins for Main Board
    [Substructure Main.kicad_sch]
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2025-04-08 Added Power & General Connections to Current Sensor
    [Substructure Main.kicad_sch]
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2025-04-19 Modified USB HUB Components from 0603 to 0402
    [Substructure Main.kicad_pcb, Substructure Main.kicad_sch]
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2025-04-21 Added FFC Ports U and R to Schematic
    [Substructure Snoot Board.kicad_sch]
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2025-04-23 Modified ESP32 for 1U instead of Integrated Antenna
    [Substructure Main.kicad_pcb, Substructure Main.kicad_sch]
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2025-04-30 Modified GPU PSU Buck Converter IC to LM5176PWPR
    [Substructure Snoot Board.kicad_sch, buckconverter.kicad_sch]
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2025-05-03 Modified Buck Converter (Added Duplicate Components from Reference Design)
    [buckconverter.kicad_sch]
2025-05-04 Added Footprints to the Input Power Filtering (Buck Converter)
    [Substructure Snoot Board.kicad_sch, buckconverter.kicad_sch]
2025-05-04 Added LCSC Parts to Power Input, VCC and Mosfets (Buck Converter)
    [buckconverter.kicad_sch]
2025-05-04 Added Remaining Power Filtering Component LCSC & Footprint (Buck Converter)
    [buckconverter.kicad_sch]
2025-05-04 Added LCSC Components & Footprints to Buck Setup
    [buckconverter.kicad_sch]
2025-05-04 Added LCSC Components & Footprints to Buck Current Sense
    [buckconverter.kicad_sch]
2025-05-05 Added LCSC Components & Footprints to Buck Boot Setup
    [buckconverter.kicad_sch]
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2025-05-05 Modified PCB from 2 Layers to 4 Layers
    [Substructure Snoot Board.kicad_pcb]
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2025-05-09 Added A JST (S JST Alternative Power Port) & S Pin Configs
    [Substructure Snoot Board.kicad_pcb, Substructure Snoot Board.kicad_sch]
2025-05-09 Added Power Distribution Board & Migrated Components from Snoot to it
    [PowerSense.kicad_sch, Substructure Power Distribution.kicad_pcb, Substructure Power Distribution.kicad_sch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]
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2025-05-11 Added System PWR Jumper Pins & USBC Connector & PWR Indicator LEDS
    [Substructure Snoot Board.kicad_pcb, Substructure Snoot Board.kicad_sch]
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2025-05-23 Added Routing (Simple Connections & Display Pins Start)
    [Substructure Snoot Board.kicad_pcb]
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2025-06-24 Added Component Placement Optimisation & Board Edge & Routing
    [Substructure Fan Mic Board.kicad_pcb]
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2025-07-01 Modified Board Outline (Fixed Overlapping Issues)
    [Substructure Display Adapter.kicad_pcb]
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2025-07-01 Modified Schematic (Added Notes to the Capacitive Pads & Antenna)
    [Substructure Boop Board.kicad_sch]
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2025-07-02 Added Antenna LC tank values & EMC filter values
    [Substructure Boop Board.kicad_pcb, Substructure Boop Board.kicad_sch]
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2025-07-03 Added Keep Out Zones (Radio EMI Reduction)
    [Substructure Boop Board.kicad_pcb]
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2025-07-03 Added LCSC & Digikey IDs for main components
    [Substructure Boop Board.kicad_sch]
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2025-07-06 Modified Board from 2 Layer to 4 Layers & Routed close components
    [Substructure Main.kicad_pcb, USBHUB..kicad_sch]
2025-07-07 Added Routing for USB lanes, power & other data lanes
    [Substructure Main.kicad_pcb, Substructure Main.kicad_sch, USBHUB..kicad_sch]
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2025-07-11 Added P Channel mosfets & crow bar circuits
    [PowerSense.kicad_sch, Substructure Power Distribution.kicad_sch, buckconverter.kicad_sch]
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2025-07-11 Modified Thyristor (Replaced component)
    [Substructure Power Distribution.kicad_sch]
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2025-07-17 Modified Fill plane to detach each pcb from each other
    [Substructure Display Adapter.kicad_pcb]
2025-07-17 Added Non SMT Batch for 2 Layer PCBs
    [Batch (2 Layer Non SMT).kicad_pcb]
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2025-07-18 Modified Board positions for optimal cutting & manufacture
    [Batch (2 Layer Non SMT).kicad_pcb]
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2025-07-21 Added New Routing (Improved board space & signal noise)
    [Substructure GPU.kicad_pcb, Substructure GPU.kicad_sch]
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2025-07-23 Modified Addressable LED strip labels for general systems
    [Main Head CPU.kicad_pcb, Main Head CPU.kicad_sch]
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2025-07-23 Modified Addressable LED ports for general (instead of static config names)
    [Main Head CPU.kicad_pcb, Main Head CPU.kicad_sch]
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2025-07-25 Modified Display pins (Corrected port orientation) & Added Silkscreen Data
    [Substructure GPU.kicad_pcb, Substructure GPU.kicad_sch]
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2025-07-25 Modified Buttons from pull down to pull up
    [Main Head CPU.kicad_pcb, Main Head CPU.kicad_sch]
2025-07-26 Added Component placement & routing & asset data
    [Main Buttons.kicad_pcb, Main Buttons.kicad_sch]
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2025-07-27 Modified Tables per component to centralise LCSC IDs
    [4 layer Batch.kicad_pcb, Main Head CPU.kicad_pcb, Main Head CPU.kicad_sch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]
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2025-07-29 Added Hardware Fixes (New Magnetic Jaw Joint Ideation)
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2025-08-09 Added Nose holes & reinforced jaw
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2025-09-06 Added Wroom32 hole to substructure (fitting issues)
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2025-09-13 Added Reinforcements to CPU mount tabs
2025-09-22 Modified Model to print better and accounted for some tolerances
2025-09-24 Added Manufacturing costs (useful for cataloging and tracking production costs/development)
    [Manufacturing.ods]
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2025-09-26 Modified Components, filament volume and print times for head restraint and substructure
    [Manufacturing.ods]
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2025-09-28 Added Support on top of the pogo pins to prevent print support build up
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2025-09-28 Modified Substructure cable guide (shortened) to prevent support build up
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2025-10-10 Modified Jaw joint to prevent collision when inserting hinge
2025-10-10 Added New times accounting for new printing system
    [Manufacturing.ods]
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2025-10-15 Modified Vacuum Buck design (For ASA printing), pogo pin mount tolerances for substructure & cable routing for substructure
2025-10-15 Added More Hardware notes for vacuum forming & cable routing
    [Notes.ods]
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2025-10-16 Added Mass & Time for visor buck (ASA)
    [Manufacturing.ods]
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2025-10-20 Added More notes regarding hardware and rubber band mounting
    [Notes.ods]
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2025-10-21 Added Hardware pogo pins disconnecting due to flexing issue to notes
    [Notes.ods]
2025-10-22 Modified Substructure port position to account for mounting tolerance
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2025-10-27 Added Notch at the front of buck to prevent supports
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2025-11-05 Added Current issues to diagram
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2025-11-10 Modified UART communication analysis report (Fixed FPS bottleneck issue & reliablility calculations)
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2025-11-14 Added The process down time issue to notes
    [Notes.ods]
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2025-12-05 Modified 4 Bar linkage (Reinforced the first joint & corrected tolerance for a tighter joint
2025-12-06 Modified Sag amount from buck height to few CM by stretching the sheet when up to temp
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2026-01-03 Added Pixel weight rasterisation & Added Bug fix (UART buffer overload)
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2026-01-14 Added ESP32 Flash size correction, sprite manager, basic (test) and advanced (test)
    [partitions_16mb.csv]
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2026-01-16 Added GPU warnings and errors debug & Added GPU driver for cpu usage and communication
    [CPU_GpuDriverTest.cpp, GpuCommands.hpp]
2026-01-19 Added Sensor driver separation & Added Wifi sprite system test & Added GPU sprite driver & Added Pipeline fix for sprite to GPU in main CPU code
    [GpuCommands.hpp, MicDriver.hpp]
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2026-01-27 Modified OLED from main run code (separated code) & Added Sensor bootloader fixes
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2026-01-29 Added SD Factory reset
    [SceneManager.hpp]
2026-01-29 Added New YAML scene management system (Buggy at the moment)
    [PageDisplayConfig.hpp]
2026-01-29 Added Removed bugs from YAML scene management
    - Not saving issue
    - Not applying effects issue
    - Many UI issues with auto generation of variables
    [PageDisplayConfig.hpp]
2026-01-31 Added Panel ghosting fix
    [PageDisplayConfig.hpp]
2026-01-31 Added Panel flashing and OLED delayed update fix
    [GpuCommands.hpp, PageDisplayConfig.hpp]
2026-01-31 Added Web UI fix for animation list disappearing & Modified Current animation settings to be more stable
    [GpuCommands.hpp, PageDisplayConfig.hpp]
2026-02-01 Added Scene not fully saving with all shaders bug fix
    [GpuCommands.hpp]
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2026-02-02 Added GPU connected state not updating bug fix
    [GpuCommands.hpp]
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2026-02-04 Added Shader setting configuration stuck bug fix & Added GPU frame optimisation
2026-02-04 Removed Buggy legacy colour override shader type & Modified Glitch shader to be a toggle effect
    [GpuCommands.hpp, PageDisplayConfig.hpp]
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
